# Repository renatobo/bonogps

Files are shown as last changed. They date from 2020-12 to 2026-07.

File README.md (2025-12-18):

# What is BonoGPS?

- [What is BonoGPS?](#what-is-bonogps)
  - [For the track day enthusiast](#for-the-track-day-enthusiast)
  - [For the SW Engineer / maker](#for-the-sw-engineer--maker)
    - [Diagram of project components](#diagram-of-project-components)
  - [Quick Start Guide](#quick-start-guide)
  - [Known Good Configurations](#known-good-configurations)
  - [Complete Bill of Materials (BOM)](#complete-bill-of-materials-bom)
  - [How to Verify Everything is Working](#how-to-verify-everything-is-working)
  - [Common Mistakes to Avoid](#common-mistakes-to-avoid)
  - [HowTo](#howto)
    - [Daily Usage](#daily-usage)
      - [Save a configuration](#save-a-configuration)
    - [Connecting to an app](#connecting-to-an-app)
  - [Hardware build instructions](#hardware-build-instructions)
    - [GPS Choice and setup preconfiguration](#gps-choice-and-setup-preconfiguration)
  - [Software build instructions](#software-build-instructions)
  - [Technical Specifications](#technical-specifications)
  - [Troubleshooting and FAQ](#troubleshooting-and-faq)
  - [Possible enhancements and ideas](#possible-enhancements-and-ideas)
  - [Glossary](#glossary)
  - [Credits and tools](#credits-and-tools)

## For the track day enthusiast

The main goal of this device is to **make GPS data (speed, location) available to mobile apps that can record data up to 25 Hz, for example for track riding**. While there are many good (and not even too expensive) solutions out there, building one for yourself is a great experience.

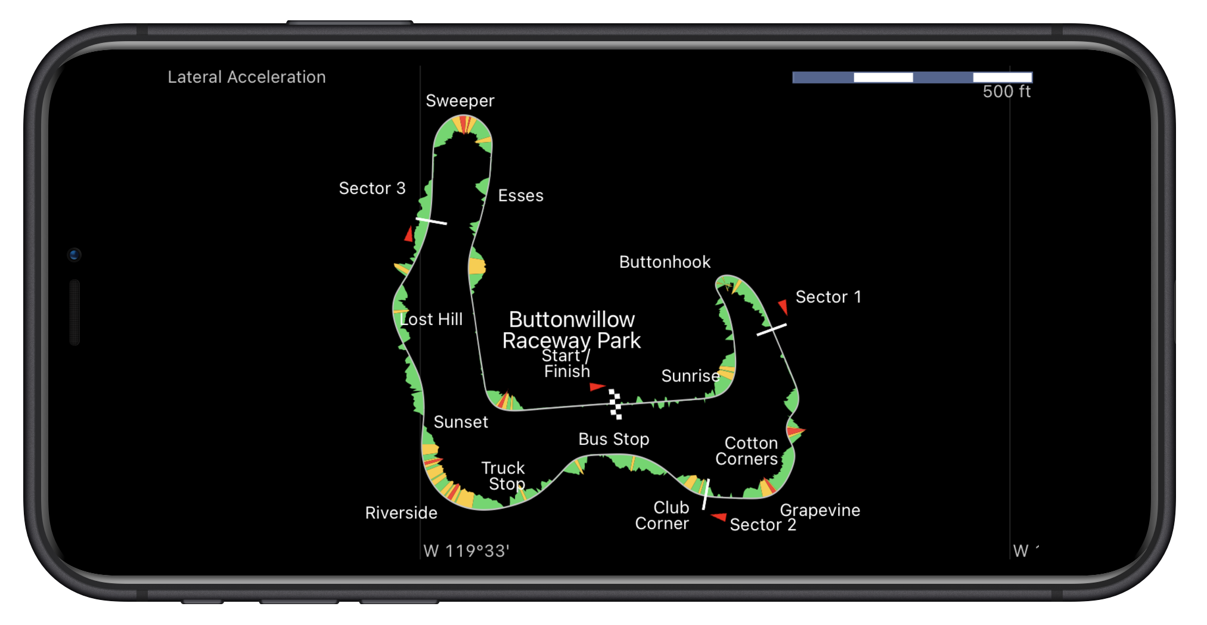
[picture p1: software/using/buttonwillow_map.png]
Map of Buttonwillow lateral acceleration


Currently these apps are supported

1. [Harry's Lap Timer](https://www.gps-laptimer.de) >> details [here](software/connecting/harrylaptimer)
2. [TrackAddict](https://www.hptuners.com/product/trackaddict-app/) >> details [here](software/connecting/trackaddict)
3. [RaceChrono](https://racechrono.com/) >> details [here](software/connecting/racechrono)
4. [RaceTime](https://www.racetimeapp.com/en/) >> details [here](software/connecting/racetime)

If you are not into the maker thing or if you don't know anyone who might be, [look into RaceBox products like mini/miniS](https://www.racebox.pro/) and even [a 25Hz kit](https://www.racebox.pro/products/racebox-micro), or [a XGPS160](https://gps.dualav.com/explore-by-product/xgps160).

## For the SW Engineer / maker

This repo contains software, a list of hardware, and (simple) schematics to build an ESP32 device that reads NMEA sentences from a GPS receiver compatible with u-blox M10 and M8 series, for example:

| GPS Module | Chipset | Max Refresh | Antenna Type | Recommended | Link |
| --- | --- | --- | --- | --- | ---- |
| **BK880** | M10 | **25 Hz** | Active | ✓ Best | [Store](https://store.beitian.com/products/beitian-compass-qmc5883l-amp2-6-pix4-pixhawk-gnss-gps-glonass-dual-flight-control-gps-module-bn-880q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) |
| **BK280** | M10 | **25 Hz** | Passive | ✓ Best | [Store](https://store.beitian.com/collections/gps-module/products/beitian-gps-module-with-antenna-ubx-m10050-gnss-chip-ultra-low-power-gnss-receiver-for-track-be-180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) |
| BN880 | M8 | 10 Hz | Active | Good | [Store](https://store.beitian.com/products/beitian-ubx-m8030-g-mouse-supports-gps-qzss-and-sbas-fixed-wing-traversing-aircraft-gps-module-antenna-bn-180-220-280-357-880-880q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) |
| BN220 | M8 | 10 Hz | Passive | Budget | [Store](https://store.beitian.com/products/beitian-ubx-m8030-g-mouse-supports-gps-qzss-and-sbas-fixed-wing-traversing-aircraft-gps-module-antenna-bn-180-220-280-357-880-880q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) |
| DIYmall NEO-M8N | M8N | 10 Hz | Active | Compatible | [Amazon](https://www.amazon.com/DIYmall-NEO-M8N-Module-HMC5983-Antenna/dp/B012RNLG0K) |

**Note:** Active antennas provide better signal quality. M10 modules (BK880/BK280) offer 25Hz refresh rate which is ideal for track use. See [GPS setup guide](hardware/GPS) for detailed configuration.

and repeats them back to a logger device, either

1. a Bluetooth Low Energy (BLE) service
2. a BT Classic (BT-SPP) stream
3. a TCP-IP socket

The logger device is likely going to be one of the *Track Lap time apps* listed above running on your phone.

Examples of actual devices are in [hardware/assembled](hardware/assembled), at a cost of 25$ and 40$ (GPS receivers with active antennas are a little bit more expensive but worth it, and a larger battery helps as well)

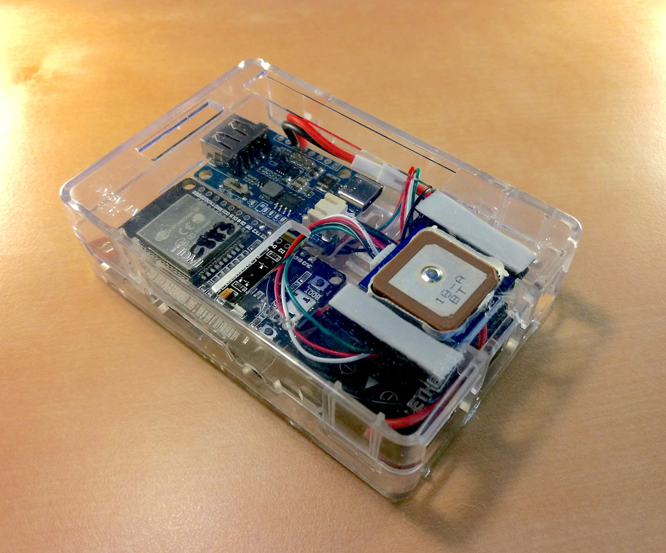
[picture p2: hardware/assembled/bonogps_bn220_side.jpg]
Prototype picture


A web configuration (basic responsive HTML) panel allows changing configuration and selecting GPS parameters on the fly: access it via [http://bonogps.local](http://bonogps.local) (when in WiFi AP mode, this becomes [http://10.0.0.1](http://10.0.0.1) on Android without mDNS resolution).

The settings required by each app are available as presets that you can load for your device (iOS, Android). More information on what version, features, and connections of each app are in [software/connecting](software/connecting).

You can also interface your GPS to [uBlox u-center](https://www.u-blox.com/en/product/u-center) via TCP-IP. In this case, be aware that the UART speed is fixed.

### Diagram of project components

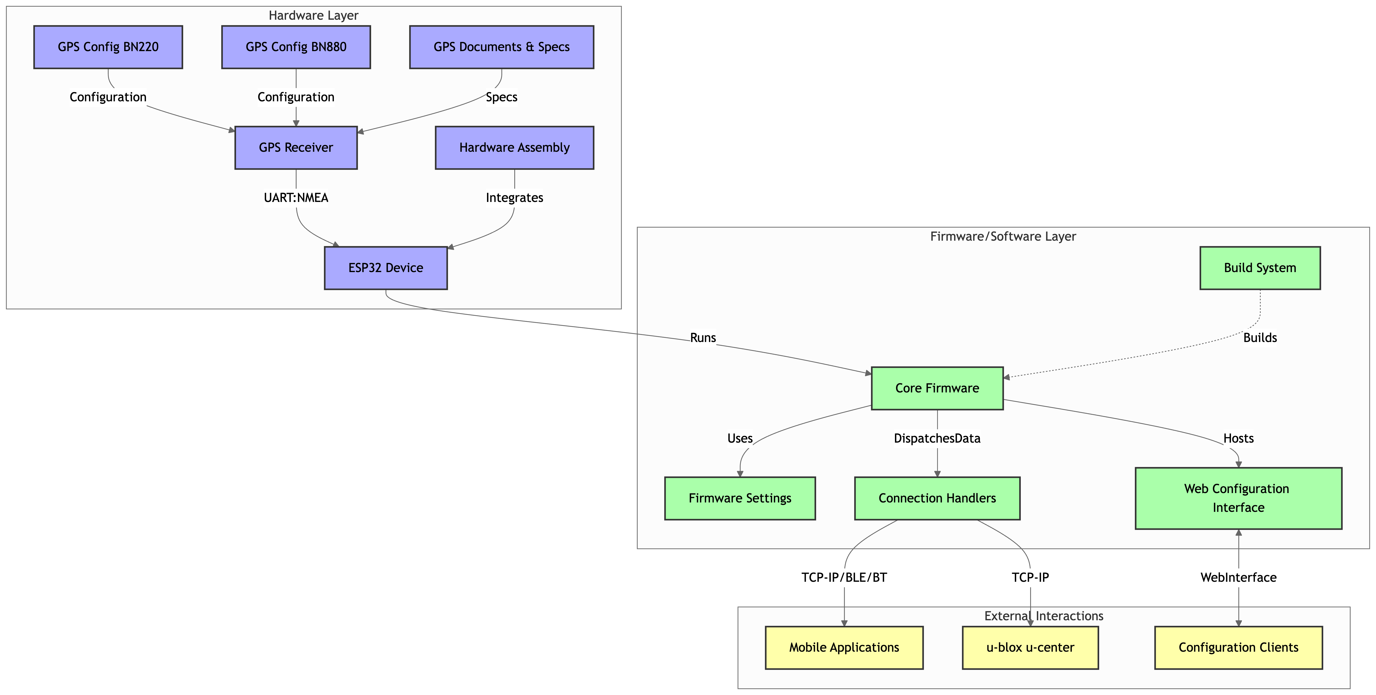
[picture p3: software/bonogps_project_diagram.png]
Project diagram


## Quick Start Guide

**New to BonoGPS? Get started in 5 steps:**

### Step 1: Get the Hardware (Budget: $30-60)

**Minimum setup (~$30):**
- ESP32 DevKit board (~$8-12) - [Amazon](https://www.amazon.com/s?k=esp32+devkit)
- BN220 GPS module (~$15-20) - [Beitian Store](https://store.beitian.com/)
- USB cable for programming/power
- Basic jumper wires

**Recommended setup (~$45):**
- ESP32 DevKit or LOLIN D32 PRO (~$12-20)
- BN880 GPS with active antenna (~$25) - [Beitian Store](https://store.beitian.com/)
- Li-Ion battery (650-2000mAh, ~$5-10)
- Case or 3D printed enclosure

**Best performance (~$60):**
- LOLIN D32 PRO with built-in battery charger (~$15-20)
- BK880 or BK280 GPS (M10, 25Hz) (~$35-45) - [Beitian Store](https://store.beitian.com/)
- 2000mAh Li-Ion battery (~$8-12)
- Custom 3D printed mount

### Step 2: Wire It Up (15 minutes)

Connect GPS to ESP32 - only 4 wires needed:
- GPS **VCC** → ESP32 **3.3V** (power)
- GPS **GND** → ESP32 **GND** (ground)
- GPS **TX** → ESP32 **RX** (GPIO 16 on DevKit, GPIO 4 on LOLIN D32 PRO)
- GPS **RX** → ESP32 **TX** (GPIO 17 on DevKit, GPIO 2 on LOLIN D32 PRO)

See detailed wiring diagrams: [Generic ESP32](hardware/esp32) | [LOLIN D32 PRO](hardware/esp32/lolin_d32_pro.md)

### Step 3: Configure GPS Module (30 minutes)

**Critical:** GPS must be configured before first use.

1. Download [u-blox u-center](https://www.u-blox.com/en/product/u-center)
2. Connect GPS to computer via USB-to-serial adapter
3. Follow the [GPS configuration guide](hardware/GPS)
4. Set baudrate to **115200**
5. Enable required NMEA messages
6. Save configuration to GPS flash memory

### Step 4: Build and Upload Software (20-45 minutes)

**Option A: Arduino IDE (easier for beginners)**
1. Install [Arduino IDE 2.x](https://www.arduino.cc/en/software)
2. Add ESP32 board support
3. Install required libraries (see [library list](software/building#external-libraries))
4. Open `bonogps.ino`
5. Select "ESP32 Dev Module" or "LOLIN D32 PRO"
6. Select "Minimal SPIFFS (1.9MB)" partition scheme
7. Upload to ESP32

**Option B: PlatformIO (recommended for developers)**
1. Install [VS Code + PlatformIO](https://platformio.org/install/ide?install=vscode)
2. Clone this repository: `git clone https://github.com/renatobo/bonogps.git`
3. Open project folder in VS Code
4. Select build target for your board
5. Build and upload

See detailed instructions: [Software build guide](software/building)

### Step 5: Connect to Your App (10 minutes)

1. Power on BonoGPS - wait for GPS fix (LED blinks once/second)
2. Connect phone to **BonoGPS-XXXX** WiFi network
3. Open browser to [http://10.0.0.1](http://10.0.0.1)
4. Go to **Device > Load Preset** - select your app and platform
5. Enable appropriate connection (BLE/BT-SPP/TCP-IP)
6. Open your lap timer app and connect

**Supported apps:** [Harry's Lap Timer](software/connecting/harrylaptimer) | [TrackAddict](software/connecting/trackaddict) | [RaceChrono](software/connecting/racechrono) | [RaceTime](software/connecting/racetime)

**Need help?** See [Troubleshooting FAQ](#troubleshooting-and-faq) below.

---

## Known Good Configurations

These hardware and app combinations have been tested and confirmed working. Use these as reference if you want a guaranteed-to-work setup.

### Budget Build - iOS ($45)
**Hardware:**
- ESP32 DevKit (~$10)
- BN880 GPS with active antenna (~$25)
- 1000mAh Li-Ion battery (~$6)
- Micro USB cable for programming
- Basic transparent case

**Software & Connection:**
- Harry's Lap Timer (iOS)
- Connection: BLE
- Preset: "Harry's Lap Timer iOS BLE"
- Expected performance: 10Hz, good accuracy (2-3m)

**Why this works:** BN880 active antenna provides reliable signal, BLE is native to iOS, Harry's Lap Timer has best BLE support.

### Best Performance - iOS ($65)
**Hardware:**
- LOLIN D32 PRO (~$18)
- BK880 GPS M10 with active antenna (~$40)
- 2000mAh Li-Ion battery (~$10)
- Custom 3D printed mount

**Software & Connection:**
- Harry's Lap Timer (iOS)
- Connection: BLE
- Preset: "Harry's Lap Timer iOS BLE"
- Expected performance: 20Hz over BLE, excellent accuracy (<2m)

**Why this works:** M10 chipset supports 25Hz, LOLIN has battery management, BLE optimized for iOS. Best overall iOS solution.

### Budget Build - Android ($35)
**Hardware:**
- ESP32 DevKit (~$8)
- BN220 GPS with passive antenna (~$18)
- Powered via USB (no battery)
- Velcro mounting

**Software & Connection:**
- RaceChrono (Android)
- Connection: BT-SPP
- Preset: "RaceChrono Android BT-SPP"
- Expected performance: 10Hz, good accuracy in open areas

**Why this works:** BT-SPP is most reliable on Android, RaceChrono is free and widely used, no battery needed for testing.

### Recommended - Android ($50)
**Hardware:**
- ESP32 DevKit or LOLIN D32 PRO (~$12-18)
- BN880 GPS with active antenna (~$25)
- 1500mAh Li-Ion battery (~$8)
- Basic enclosure

**Software & Connection:**
- RaceChrono or TrackAddict (Android)
- Connection: BT-SPP
- Preset: App-specific BT-SPP preset
- Expected performance: 10Hz, excellent accuracy (2-3m)

**Why this works:** Active antenna ensures good signal, BT-SPP handles full NMEA messages reliably, proven battery life for track days.

### Advanced - Android with High Refresh ($65)
**Hardware:**
- LOLIN D32 PRO (~$18)
- BK880 M10 GPS with active antenna (~$40)
- 2000mAh Li-Ion battery (~$10)
- Professional mounting solution

**Software & Connection:**
- Harry's Lap Timer (Android)
- Connection: BT-SPP or TCP-IP
- Preset: "Harry's Lap Timer Android BT-SPP"
- Expected performance: 10Hz over BT-SPP (25Hz requires TCP-IP)

**Why this works:** M10 chipset provides maximum performance, larger battery for full track day, LOLIN handles power management. **Note:** 25Hz requires TCP-IP connection which has less range than Bluetooth.

### Universal WiFi Setup - iOS & Android ($45)
**Hardware:**
- ESP32 DevKit (~$10)
- BN880 GPS (~$25)
- 2000mAh Li-Ion battery (~$10) - important for WiFi power draw

**Software & Connection:**
- RaceChrono (iOS or Android)
- Connection: TCP-IP over WiFi
- IP: 10.0.0.1, Port: 1818
- Expected performance: 10Hz, works on any platform

**Why this works:** TCP-IP works universally, no Bluetooth pairing needed, RaceChrono supports custom TCP devices. Larger battery compensates for WiFi power consumption.

### What About TrackAddict?
**Hardware:** Any ESP32 + BN220/BN880
**Platform:** Android only (not available on iOS)
**Connection:** BT-SPP only
**Important:** Must use **GP Talker ID** (not GN). Load "TrackAddict Android BT-SPP" preset.

### Testing Configuration (Cheapest, $30)
For initial testing before investing in batteries/cases:
- ESP32 DevKit (~$8)
- BN220 GPS (~$18)
- USB power from laptop
- Any supported app
- Test app connection indoors via WiFi, then test GPS outdoors

---

## Complete Bill of Materials (BOM)

Use this comprehensive shopping list to gather all components for your BonoGPS build. Choose components based on your budget and performance requirements.

### Core Components (Required)

| Component | Options | Qty | Est. Cost | Purpose | Where to Buy | Notes |
|---|---|-----|---|---|---|---|
| **ESP32 Board** | ESP32 DevKit (generic) | 1 | $8-12 | Main controller | [Amazon](https://www.amazon.com/s?k=esp32+devkit), AliExpress | Most common, cheapest |
| | LOLIN D32 PRO | 1 | $15-20 | Main controller + extras | [WEMOS/LOLIN Store](https://www.wemos.cc/) | Battery charger, PSRAM, TF card |
| **GPS Module** | BN220 (M8, passive) | 1 | $15-20 | Budget GPS | [Beitian Store](https://store.beitian.com/) | 10Hz max, passive antenna |
| | BN880 (M8, active) | 1 | $23-27 | Good GPS | [Beitian Store](https://store.beitian.com/) | 10Hz max, active antenna (recommended) |
| | BK280 (M10, passive) | 1 | $35-40 | Best GPS | [Beitian Store](https://store.beitian.com/) | 25Hz capable, passive antenna |
| | BK880 (M10, active) | 1 | $38-45 | Best GPS | [Beitian Store](https://store.beitian.com/) | 25Hz capable, active antenna (best performance) |
| | NEO-M8N | 1 | $25-30 | Compatible GPS | [Amazon](https://www.amazon.com/s?k=neo-m8n+gps) | Alternative M8 module |
| **USB Cable** | Micro USB cable | 1 | $3-5 | Programming & power | Amazon, any electronics store | For ESP32 DevKit |
| | USB-C cable | 1 | $5-8 | Programming & power | Amazon, any electronics store | For LOLIN D32 PRO |
| **Jumper Wires** | Male-to-female, 10cm | 4+ | $2-5 | GPS wiring | Amazon, AliExpress | Only needed if not soldering |

**Core components subtotal:** $30-60 depending on choices

### Power Components (Recommended for portable use)

| Component | Options | Qty | Est. Cost | Purpose | Where to Buy | Notes |
|---|---|-----|---|---|---|---|
| **Battery** | 650mAh Li-Ion 3.7V | 1 | $5-7 | ~2-2.5 hrs runtime | Amazon, hobby stores | JST connector |
| | 1000mAh Li-Ion 3.7V | 1 | $6-8 | ~3-4 hrs runtime | Amazon, hobby stores | JST connector |
| | 1500mAh Li-Ion 3.7V | 1 | $8-10 | ~5-6 hrs runtime | Amazon, hobby stores | JST connector |
| | 2000mAh Li-Ion 3.7V | 1 | $8-12 | ~6-8 hrs runtime | Amazon, hobby stores | JST connector, best for track day |
| **Battery Charger** | USB Li-Ion charger | 1 | $3-6 | Battery charging | Amazon, AliExpress | Not needed for LOLIN D32 PRO (built-in) |
| | LiPo balance charger | 1 | $15-25 | Multi-battery charging | Amazon, hobby stores | Optional, for multiple batteries |

**Power components subtotal:** $5-40 depending on battery size and charger

### Assembly Components (Optional but recommended)

| Component | Options | Qty | Est. Cost | Purpose | Where to Buy | Notes |
|---|---|-----|---|---|---|---|
| **Enclosure** | Transparent plastic case | 1 | $3-8 | Basic protection | Amazon, electronics stores | Various sizes available |
| | Custom 3D printed case | 1 | $5-15 | Perfect fit | Local makerspace, online 3D print services | STL files in [hardware/assembled](hardware/assembled) |
| | Weatherproof box | 1 | $10-20 | Professional protection | Amazon | For permanent motorcycle installations |
| **Mounting** | Velcro strips | 1 set | $3-5 | Removable mounting | Amazon, hardware stores | Easy attachment/removal |
| | Double-sided tape (3M VHB) | 1 roll | $5-10 | Semi-permanent | Amazon, hardware stores | Strong, vibration-resistant |
| | Zip ties | 10+ | $2-5 | Cable management | Amazon, hardware stores | Various sizes |
| **Wiring** | Heat shrink tubing | 1 set | $5-8 | Wire insulation | Amazon | Professional finish |
| | 22-24 AWG stranded wire | 1m | $3-5 | Custom wiring | Amazon, electronics stores | If making custom cables |
| | JST connectors | 5 sets | $5-10 | Battery connectors | Amazon, hobby stores | For custom battery connections |
| **Soldering** | Soldering iron kit | 1 | $15-40 | Permanent connections | Amazon | If you don't have one |
| | Solder (lead-free) | 1 roll | $8-15 | Soldering | Amazon, electronics stores | 60/40 or lead-free |
| | Flux pen | 1 | $5-8 | Better solder joints | Amazon | Makes soldering easier |

**Assembly components subtotal:** $0-80+ depending on tools and quality

### Configuration Tools (One-time purchase)

| Component | Options | Qty | Est. Cost | Purpose | Where to Buy | Notes |
|---|---|-----|---|---|---|---|
| **USB-to-Serial Adapter** | CP2102 or FTDI adapter | 1 | $5-10 | GPS configuration | Amazon, AliExpress | Required for GPS setup with u-center |
| | USB-to-TTL with 3.3V/5V switch | 1 | $8-12 | GPS configuration (better) | Amazon | More versatile, safer |

**Configuration tools subtotal:** $5-12 (one-time, reusable)

### Software (Free)

| Software | Cost | Purpose | Where to Get |
|---|---|---|---|
| Arduino IDE 2.x | Free | Firmware compilation (beginner) | [arduino.cc](https://www.arduino.cc/en/software) |
| VS Code + PlatformIO | Free | Firmware compilation (advanced) | [platformio.org](https://platformio.org/) |
| u-blox u-center | Free | GPS configuration | [u-blox.com](https://www.u-blox.com/en/product/u-center) |
| Harry's Lap Timer | $0-100 | iOS/Android lap timing | App Store / Play Store |
| RaceChrono | Free-$20 | iOS/Android lap timing | App Store / Play Store |
| TrackAddict | Free-$25 | Android lap timing | Play Store |
| RaceTime | Free | Android lap timing | Play Store |

### Shopping List Templates

**Minimum viable build ($30-35):**
- [ ] ESP32 DevKit ($8-12)
- [ ] BN220 GPS ($15-20)
- [ ] Micro USB cable ($3-5)
- [ ] 4x jumper wires ($2-5) OR soldering supplies
- [ ] USB-to-serial adapter ($5-10) for GPS config
- **Total: ~$33-52**

**Recommended portable build ($50-65):**
- [ ] ESP32 DevKit or LOLIN D32 PRO ($10-18)
- [ ] BN880 GPS ($25)
- [ ] 1000-1500mAh battery ($6-10)
- [ ] USB cable ($3-8)
- [ ] Plastic case ($3-8)
- [ ] Velcro or double-sided tape ($3-5)
- [ ] USB-to-serial adapter ($5-10)
- **Total: ~$55-84**

**Best performance build ($70-90):**
- [ ] LOLIN D32 PRO ($15-20)
- [ ] BK880 M10 GPS ($38-45)
- [ ] 2000mAh battery ($8-12)
- [ ] USB-C cable ($5-8)
- [ ] 3D printed custom case ($5-15)
- [ ] Mounting solution ($3-10)
- [ ] USB-to-serial adapter ($5-10)
- [ ] Soldering supplies if needed ($15-40)
- **Total: ~$79-160**

### Notes on Purchasing

**GPS Modules:**
- Buy directly from Beitian Store for authentic modules
- Beware of clones on AliExpress/eBay (may have older firmware or fake chipsets)
- Active antennas significantly improve performance in difficult conditions

**Batteries:**
- Match voltage: 3.7V Li-Ion or LiPo only
- Check connector: JST 2-pin is most common
- Capacity = runtime: 650mAh → 2hrs, 2000mAh → 8hrs
- Never charge Li-Ion batteries below 0°C (32°F)

**ESP32 Boards:**
- DevKit: Universal compatibility, cheapest
- LOLIN D32 PRO: Built-in battery management worth the extra cost for portable use

**Where to save money:**
- Skip the case initially (test on desk)
- Use USB power instead of battery for testing
- Use jumper wires instead of soldering initially
- BN220 instead of BN880 (passive vs active antenna)

**Where NOT to save money:**
- GPS module quality (buy from reputable source)
- USB cable quality (cheap cables cause upload/power issues)
- Battery quality (cheap batteries fail quickly)

---

## How to Verify Everything is Working

After completing the Quick Start, use this checklist to confirm your BonoGPS is functioning correctly:

### Hardware & Boot Checks
- ✅ **ESP32 powers on:** Device responds when plugged in via USB or battery
- ✅ **Built-in LED indicates WiFi mode:**
  - Slow blink (500ms cycle) = Access Point mode active
  - Fast blink (250ms cycle) = Client mode active
  - Off = WiFi disabled
- ✅ **GPS module powers on:** GPS module LED is visible (if module has one)

### GPS Functionality
- ✅ **GPS acquires satellite fix:**
  - BN/BK modules: Red LED blinks once per second after fix
  - First time: Allow 5-15 minutes outdoors with clear sky view
  - Subsequent times: Should get fix in 1-5 seconds
- ✅ **Satellite count adequate:** At least 4 satellites visible for accurate positioning
  - Check in web interface under "Status" or "GPS Info"
  - 8+ satellites = excellent signal
  - 4-7 satellites = good signal
  - <4 satellites = insufficient for accurate position

### Connectivity & Web Interface
- ✅ **Can access web interface:**
  - Connect to BonoGPS-XXXX WiFi network
  - Navigate to http://10.0.0.1 (Android) or http://bonogps.local (iOS/desktop)
  - Configuration page loads successfully
- ✅ **Web interface shows correct device info:**
  - Device name displays (BonoGPS-XXXX)
  - Battery voltage shown (if using LOLIN D32 PRO with battery)
  - Firmware version visible

### App Connection
- ✅ **Mobile app discovers device:**
  - BLE: Device appears as "BonoGPS-XXXX" in Bluetooth settings
  - BT-SPP: Device pairs successfully via Bluetooth
  - TCP-IP: App connects to 10.0.0.1:1818
- ✅ **App receives GPS data:**
  - Speed readings update in real-time
  - Position shows on map (if app has map view)
  - Satellite count matches GPS module readings
- ✅ **Data update rate is correct:**
  - 10Hz modules: ~10 updates per second
  - 25Hz modules: ~25 updates per second (M10 chipset only)

### Track Day Ready
- ✅ **Battery runtime adequate:** Full charge provides expected runtime based on capacity
- ✅ **GPS maintains fix while moving:** No dropouts during test drive
- ✅ **Mounting secure:** Device stays in place under vibration
- ✅ **App records session successfully:** Can complete and save a test session

**If any check fails**, see the [Troubleshooting FAQ](#troubleshooting-and-faq) section below.

---

## Common Mistakes to Avoid

### Critical Mistakes (Will prevent device from working)

**❌ Forgetting to configure GPS before first use**
- **Why it matters:** GPS modules ship with default settings that may not work with BonoGPS or your app
- **Solution:** Follow the [GPS configuration guide](hardware/GPS) before connecting GPS to ESP32
- **Time cost:** 30-45 minutes to configure correctly

**❌ Wrong partition scheme during upload**
- **Why it matters:** Default partition is too small for BonoGPS firmware with Bluetooth
- **Solution:** Select "Minimal SPIFFS (1.9MB)" in Arduino IDE or PlatformIO
- **Error:** Build fails with "not enough space" or upload fails

**❌ Swapped TX/RX pins**
- **Why it matters:** UART communication requires TX→RX and RX→TX crossover
- **Solution:** Connect GPS TX to ESP32 RX, and GPS RX to ESP32 TX
- **Symptom:** No GPS data received, web interface shows "No GPS fix"

**❌ Testing GPS indoors**
- **Why it matters:** GPS requires direct line of sight to satellites
- **Solution:** Test outdoors with clear sky view, away from buildings and trees
- **First fix:** Allow 5-15 minutes for initial satellite almanac download

### App Compatibility Mistakes

**❌ Using GN Talker ID with RaceChrono or TrackAddict**
- **Why it matters:** These apps require GP Talker ID specifically
- **Solution:** Load the app-specific preset from web interface (sets Main Talker ID = GP)
- **Symptom:** App shows "no data" or "invalid GPS"

**❌ Wrong connection method for platform**
- **Why it matters:** iOS doesn't support BT-SPP, Android BLE has limitations
- **Solution:**
  - **iOS:** Use BLE (Harry's Lap Timer) or TCP-IP (RaceChrono)
  - **Android:** Use BT-SPP (most reliable) or TCP-IP as backup
- **Symptom:** Device not found or connection drops

**❌ Too high refresh rate with satellite messages enabled**
- **Why it matters:** Bluetooth bandwidth is limited
- **Solution:**
  - For BLE: Use 20Hz or lower, disable GSA/GSV or poll at 5-second intervals
  - For BT-SPP: 10Hz is safe with full messages
- **Symptom:** Connection drops, data corruption, app crashes

### Build and Upload Mistakes

**❌ Wrong NimBLE library version**
- **Why it matters:** Breaking changes between versions 1.x, 2.x, and 3.x
- **Solution:** Use NimBLE-Arduino version **2.x** specifically
- **Error:** Compilation fails with "class NimBLEDevice has no member..."

**❌ Not cloning from Git (downloading ZIP instead)**
- **Why it matters:** Build script uses Git to determine version info
- **Solution:** Use `git clone https://github.com/renatobo/bonogps.git`
- **Error:** "git_rev_macro.py" errors during PlatformIO build

**❌ Insufficient USB power**
- **Why it matters:** ESP32 + GPS + WiFi can draw up to 500mA
- **Solution:** Use quality USB cable and powered USB port (not USB hub)
- **Symptom:** Random resets, brownouts, WiFi disconnections

### Hardware Assembly Mistakes

**❌ Using 5V instead of 3.3V for GPS power**
- **Why it matters:** Most GPS modules are 3.3V only, 5V will damage them
- **Solution:** Connect GPS VCC to ESP32 **3.3V pin**, never 5V
- **Result:** Permanent GPS module damage

**❌ Weak solder connections for motorcycle use**
- **Why it matters:** Vibration will eventually break cold solder joints
- **Solution:** Use proper soldering technique or crimped connectors
- **Symptom:** Intermittent GPS connection, random disconnections

**❌ GPS antenna placement under metal or carbon fiber**
- **Why it matters:** Metal and carbon fiber block GPS signals completely
- **Solution:** Place antenna under plastic fairings/seat cowls only
- **Symptom:** Never gets satellite fix, satellite count always 0

### Configuration Mistakes

**❌ Not saving GPS configuration to flash**
- **Why it matters:** Configuration is lost when GPS powers off
- **Solution:** In u-center, send UBX-CFG-CFG command to save to flash
- **Symptom:** GPS works after configuration but reverts on next power-on

**❌ Mismatched baudrate between GPS and ESP32**
- **Why it matters:** Serial communication requires matching speeds
- **Solution:** Set GPS to 115200 baud, matches `GPS_STANDARD_BAUD_RATE` in code
- **Symptom:** Garbled data, no GPS messages received

**❌ Forgetting to enable required NMEA messages**
- **Why it matters:** Apps need specific messages (GGA, RMC minimum)
- **Solution:** Load app preset or manually enable messages in u-center
- **Symptom:** App connects but shows "no GPS data"

**Pro tip:** Follow the Quick Start Guide step-by-step and verify each stage before moving to the next. Most issues are caught early this way.

---

## HowTo

### Daily Usage

1. Turn on the ESP32 and wait a few minutes for the GPS to get a fix on position (on BN devices, the red led will blink every second)
2. Open your preferred mobile app and connect it to your BonoGPS-*ABCD* device (ABCD is a combination of 4 letters and numbers unique to your ESP32 device)
3. Enjoy your ride!

Most runtime configurations are managed via its web-based interface: you can use your phone or any device with a web browser which is able to connect to either the built-in Access Point the BonoGPS provides or (if you are home and you have configured the WiFi Client credentials) [http://bonogps.local](http://bonogps.local)

The local built-in access point will be named BonoGPS-*ABCD* device (ABCD is a combination of 4 letters and numbers unique to your ESP32 device) and the password to it is in the source code (you can change it to your discretion - it's simply meant to avoid anyone connecting by mistake)

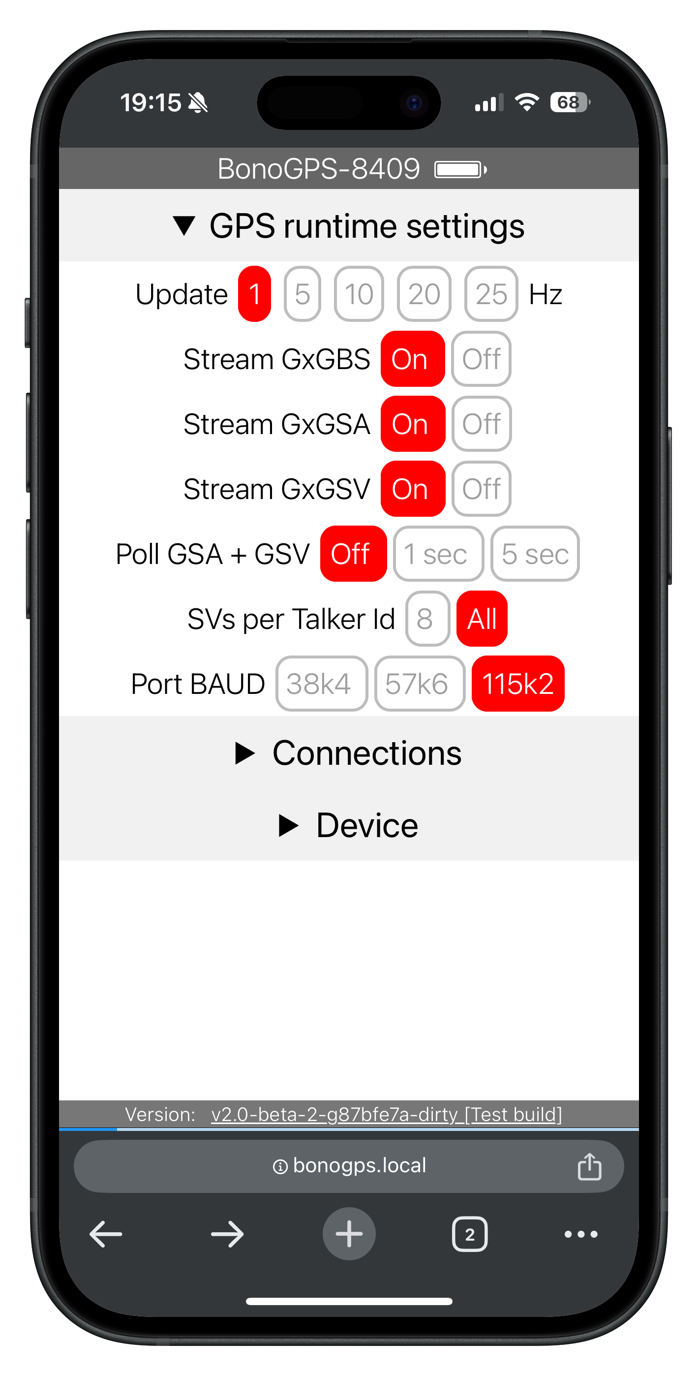
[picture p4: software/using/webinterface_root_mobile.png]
Main page of web configuration panel from mobile device


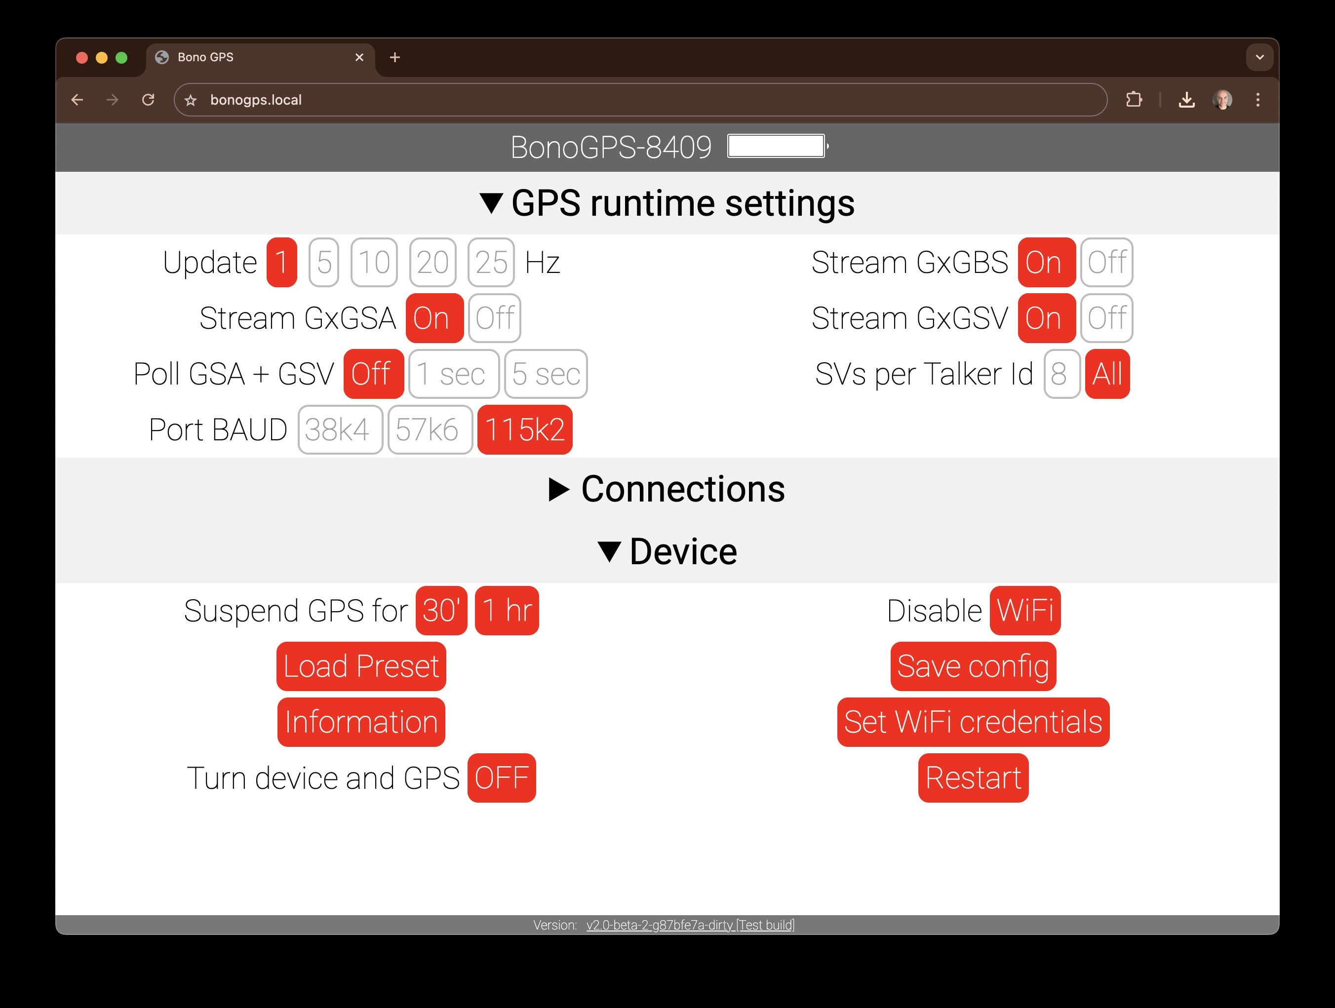
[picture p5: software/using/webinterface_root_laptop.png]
Main page of web configuration panel from laptop


- **GPS runtime settings:** GPS messages, rate of updates, serial port speed
- **Connections:** List clients, enable BLE/BT-SPP connectivity, enable/disable the builtin TCP-IP messages repeater, switch between WiFi client to a well-known WiFi network or built-in Access Point
- **Device:** Put GPS in powersaving for some time, Disable WiFi, load preset configurations, save current configuration, collect information about current status of the device, save WiFi credentials for client mode restart the ESP32

The BOOT button (or another button of your choice) allows you to loop between WiFi modes on the fly:

- short press: toggle between WiFi Access Point (built in led, usually blue, slowly blinking 500 ms cycle) and no WiFi (built in led off)
- long press (at least 2 seconds): enable WiFi Client so that you can reach the unit from your preferred WiFi network (internal led/blue led light flashes rapidly with a 250 ms cycle)

#### Save a configuration

If you load a preset or if you change a runtime settings, you can preserve it across restart of the device.

Go to *Device > Save Config* and you'll find these options

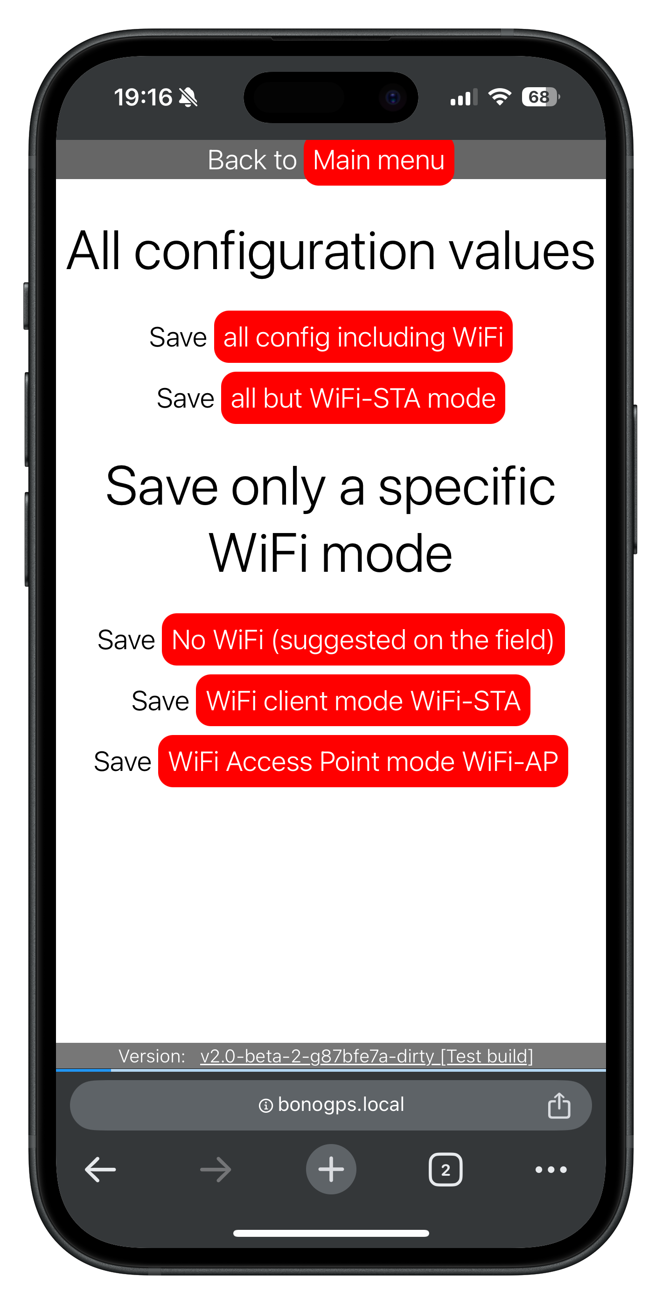
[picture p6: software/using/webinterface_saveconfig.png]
Save Config page


For convenience, the WiFi status (Start its own AP, or connect to a local WiFi) can be excluded or saved separately.

### Connecting to an app

There are many mobile apps to log lap times, few accept custom devices, in particular on iOS. The ones below are tested.

| App | Platform | Connection | Max Refresh | Tested Version | Setup Guide |
| --- | --- | --- | --- | --- | --- |
| [Harry's Lap Timer](https://www.gps-laptimer.de) | iOS | **BLE** (recommended), TCP-IP | 20Hz (BLE) | v24.9.1 | [Guide](software/connecting/harrylaptimer) |
| [Harry's Lap Timer](https://www.gps-laptimer.de) | Android | **BT-SPP** (recommended), TCP-IP | 10Hz | v24.9.1 | [Guide](software/connecting/harrylaptimer) |
| [TrackAddict](https://www.hptuners.com/product/trackaddict-app/) | Android | BT-SPP | 10Hz | v4.6.0 | [Guide](software/connecting/trackaddict) |
| [RaceChrono](https://racechrono.com/) | iOS | TCP-IP | 10Hz | v7.0.10 | [Guide](software/connecting/racechrono) |
| [RaceChrono](https://racechrono.com/) | Android | BT-SPP | 10Hz | v7.0.10 | [Guide](software/connecting/racechrono) |
| [RaceTime](https://www.racetimeapp.com/en/) | Android | BT-SPP | 10Hz | v3.3.8 lite | [Guide](software/connecting/racetime) |

**Note:** Recommended connection methods are shown in **bold**. See detailed setup instructions in each guide.

You can load a preset configuration from the configuration page selecting *Device > Load Preset* and then choosing your mobile phone device and app combination (when there are alternatives, the recommended option is in bold)

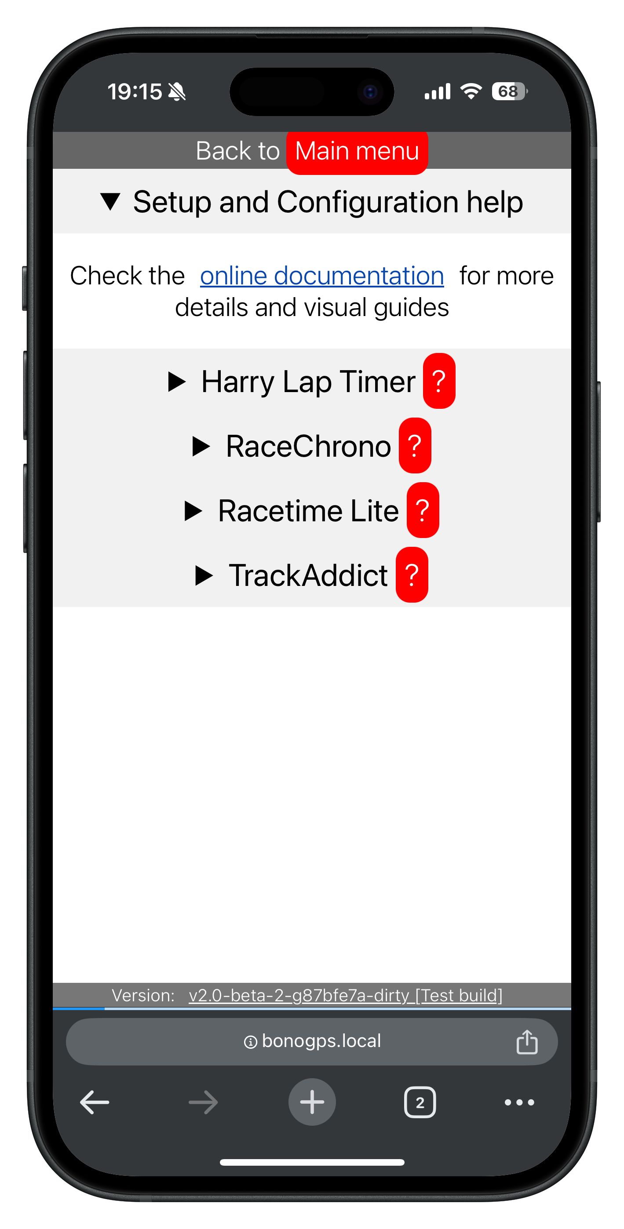
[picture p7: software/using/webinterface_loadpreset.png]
Loading presets


## Hardware build instructions

**⏱️ Time:** 30-60 minutes | **🎯 Difficulty:** Beginner (basic soldering skills helpful)

The minimum build is a ublox M8 series GPS receiver module connected to an ESP32:

- TX/RX from the GPS to a serial port (default in the code is UART2/Serial2) on ESP32. Remember: you need to connect RX on one device to TX on the other and viceversa
- the GPS power pins to ESP32: VCC to 3v3, GND to GND

BN220 comes with a 4 pin adapter cable for GND TX RX VCC, while BN880 includes 2 additionals pins for SDA and SCL of the IMU which are not used so you should leave them unconnected.

Schematics are relatively simple

- power the GPS module (3.3V on ESP32 to VCC on GPS receiver, GND on ESP32 to GND on GPS receiver)
- connect GPS RX to ESP32 UART2 TX and GPS TX to ESP32 UART2 RX (RX and TX are switched: GPS transmits, ESP32 receives)

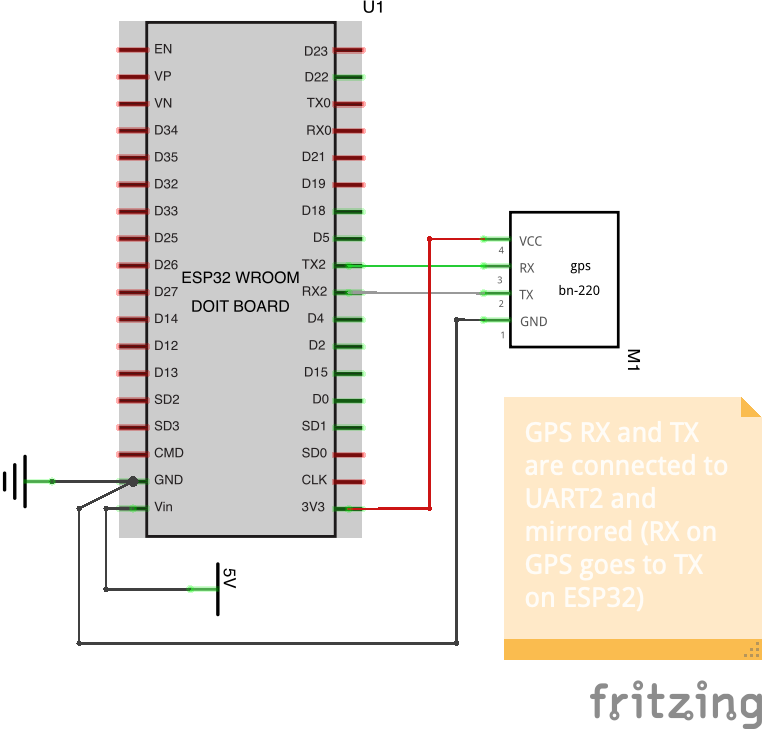
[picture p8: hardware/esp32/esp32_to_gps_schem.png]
Schematics


Examples are in [hardware/assembled](hardware/assembled) including an example with more options using an ESP32 device type Lolin D32 Pro which has an internal battery charger [hardware/esp32/lolin_d32_pro.md](hardware/esp32/lolin_d32_pro.md)

**See also:**
- [GPS Configuration Guide](hardware/GPS) - Configure GPS before use
- [Assembly Troubleshooting](hardware/assembled#hardware-assembly-troubleshooting) - Common wiring issues
- [LOLIN D32 PRO Specific Guide](hardware/esp32/lolin_d32_pro.md) - Battery charging setup

### GPS Choice and setup preconfiguration

**⏱️ Time:** 30-45 minutes | **🎯 Difficulty:** Intermediate | **Prerequisites:** USB-to-serial adapter, u-center software

Thanks to needs of a very active drone community, there are a lot of inexpensive GPS receivers: some considerations on performance/accuracy/cost are reported [in the hardware/GPS folder](hardware/GPS).

What you need to configure is documented [in the hardware/GPS folder](hardware/GPS): this is **important**, the performances of your GPS won't be optimal until you do, or the whole setup will not work at all.

**See also:**
- [GPS Module Comparison](hardware/GPS#performance-comparison) - Detailed specs for each module
- [GPS Troubleshooting](hardware/GPS#gps-hardware-troubleshooting) - Module-specific issues
- [u-blox u-center Guide](hardware/GPS) - Configuration software instructions

## Software build instructions

**⏱️ Time:** 20-45 minutes (Arduino IDE: 20-30 min, PlatformIO: 30-45 min first time) | **🎯 Difficulty:** Beginner to Intermediate | **Prerequisites:** Arduino IDE or VS Code with PlatformIO, USB cable

This code is developed specifically for ESP32, and tested with [PlatformIO](https://platformio.org/) (main development platform) and the [Arduino IDE version 2 (2.3.4)](https://www.arduino.cc/en/software). More information on what libraries are needed and software organization [in the software/building folder](software/building).

**See also:**
- [Build Troubleshooting](software/building#build-troubleshooting) - Library versions, compilation errors
- [Board Settings](include/README.md) - Pin definitions and configurations
- [Connecting to Apps](software/connecting) - After successful build

## Technical Specifications

### Performance Expectations

**GPS Accuracy:**
- **Horizontal position:** 2-3 meters (6-10 feet) typical with M8/M10 chipsets
- **Speed accuracy:** ±0.1 km/h at constant velocity
- **Update rates:** 10Hz (M8 modules), 25Hz (M10 modules)
- **Cold start time:** 5-15 minutes (first power-on)
- **Hot start time:** 1-5 seconds (after recent fix)
- **Signal quality:** C/N0 values typically 30-40 dBHz (higher is better)

**Power Consumption:**
- **ESP32:** 80-160mA (varies with WiFi/Bluetooth activity)
- **GPS module:** 30-80mA (depends on module and fix status)
- **LED indicators:** 10-40mA
- **Total typical:** 250-350mA average during operation
- **Peak consumption:** Up to 500mA when WiFi and GPS are both active

**Battery Life Examples:**
- 650mAh battery: ~2-2.5 hours runtime
- 1000mAh battery: ~3-4 hours runtime
- 2000mAh battery: ~6-8 hours runtime (full track day)

**Note:** Actual battery life depends on WiFi/Bluetooth usage, GPS update rate, and environmental conditions.

### Connectivity Specifications

**WiFi:**
- **Standard:** 802.11 b/g/n (2.4 GHz only)
- **Range:** ~30-50 meters open air (depends on environment)
- **Access Point mode:** Supports up to 4 simultaneous clients
- **TCP server port:** 1818 (configurable)
- **mDNS hostname:** bonogps.local

**Bluetooth Low Energy (BLE):**
- **Standard:** Bluetooth 4.2 / 5.0 (depends on ESP32 module)
- **Range:** ~10-30 meters typical
- **Service UUID:** 1819 (Location and Navigation Service)
- **Max throughput:** ~20Hz GPS data with minimal satellite info
- **iOS support:** Full (recommended connection method)

**Bluetooth Classic (BT-SPP):**
- **Standard:** Bluetooth 2.0 SPP (Serial Port Profile)
- **Range:** ~10-30 meters typical
- **Baudrate:** 115200 (matches GPS UART)
- **Max throughput:** ~10Hz GPS data with satellite info
- **Android support:** Full (recommended connection method)

### Build Size and Memory

**Flash Memory Usage:**
- **With BLE + BT-SPP:** ~1.5-1.7 MB (requires Minimal SPIFFS partition)
- **With BLE only:** ~1.3-1.4 MB
- **With BT-SPP only:** ~1.2-1.3 MB
- **Minimum partition:** 1.9 MB app space required

**RAM Usage:**
- **ESP32 SRAM:** ~120-180 KB used (out of 320 KB available)
- **PSRAM:** Optional, helps with stability if available (LOLIN D32 PRO has 4MB)

**SPIFFS Storage:**
- **Configuration files:** ~2-4 KB
- **Reserved space:** 190 KB (with Minimal SPIFFS partition)

### Supported NMEA Messages

**Standard output messages:**
- `GxGGA` - Global Positioning System Fix Data
- `GxRMC` - Recommended Minimum Specific GPS Data
- `GxGBS` - GNSS Satellite Fault Detection (accuracy estimates)
- `GxGSA` - GPS DOP and Active Satellites (optional, polled)
- `GxGSV` - GPS Satellites in View (optional, polled)
- `GxVTG` - Track Made Good and Ground Speed
- `GxZDA` - Time and Date

**Talker ID support:**
- `GN` - Multi-constellation GNSS (GPS+GLONASS+Galileo+BeiDou)
- `GP` - GPS only (required by some apps like RaceChrono)

**Message rates:** Configurable from 1Hz to 25Hz (hardware dependent)

### Environmental Specifications

**Operating conditions:**
- **Temperature:** -20°C to +70°C (-4°F to 158°F) typical
- **Note:** Li-Ion batteries should not be charged below 0°C (32°F)
- **Humidity:** Most ESP32 boards are not waterproof without enclosure
- **Vibration:** Solder connections recommended for motorcycle use
- **Mounting:** GPS antenna requires clear sky view (metal/carbon blocks signal)

**GPS antenna considerations:**
- **Active antennas:** Better signal quality, require 3.3V power, ~50mA draw
- **Passive antennas:** Lower signal quality, no extra power required
- **Placement:** Best under plastic fairings/seat cowls, avoid metal/carbon

### Limitations and Known Issues

**Connection limitations:**
- **BT-SPP reconnection:** Android may require device restart or re-pairing
- **BLE throughput:** Limited to ~20Hz with full NMEA messages
- **WiFi TCP:** Single client at a time for GPS data stream
- **Memory pressure:** Running BLE + BT-SPP + WiFi simultaneously may cause instability

**GPS limitations:**
- **Indoor use:** GPS will not work indoors or under metal roofs
- **Urban canyons:** Tall buildings can degrade accuracy
- **Tree cover:** Dense foliage can reduce satellite visibility
- **First fix:** Takes 5-15 minutes on first power-on to download almanac

**Software limitations:**
- **OTA updates:** Disabled by default to save flash space
- **Web interface:** Basic HTML/CSS, optimized for mobile browsers
- **Configuration backup:** Manual export/import via web interface

See [Troubleshooting FAQ](#troubleshooting-and-faq) for solutions to common problems.

## Troubleshooting and FAQ

### Common Issues and Solutions

#### GPS and Hardware Issues

**Q: My GPS is not getting a fix / takes very long to acquire satellites**

**A:** Several factors can affect GPS acquisition time:
- **First time setup:** Cold start can take 5-15 minutes to download almanac data
- **Antenna placement:** Ensure the GPS antenna has clear view of the sky. The BN-880 LED should blink once per second when it has a fix
- **Antenna orientation:** For BN-880/BK-880, the antenna should face upward (skyward)
- **Indoor use:** GPS will not work indoors or in areas with obstructed sky view
- **Configuration:** Verify your GPS is properly configured with the correct baudrate (115200) and messages enabled. See [GPS configuration guide](hardware/GPS)

**Q: No GPS data is reaching my mobile app**

**A:** Troubleshooting steps:
1. Check that the GPS has a fix (BN devices: red LED blinking every second)
2. Verify the baudrate matches: GPS port should be 115200 (check `GPS_STANDARD_BAUD_RATE` in code)
3. Confirm correct NMEA messages are enabled for your app (load the appropriate preset)
4. Check TX/RX wiring: GPS TX → ESP32 RX, GPS RX → ESP32 TX
5. Open an [issue](https://github.com/renatobo/bonogps/issues) with details if problem persists

**Q: Which GPS module should I buy?**

**A:** See the [GPS comparison table](#for-the-sw-engineer--maker) in this README. Quick recommendations:
- **Best performance:** BK880 or BK280 (M10 chipset, 25Hz, ~$35-45)
- **Good balance:** BN880 (M8 chipset with active antenna, 10Hz, ~$25)
- **Budget option:** BN220 (M8 chipset with passive antenna, 10Hz, ~$15-20)

Active antennas provide significantly better signal quality. Avoid NEO-M8N if you need multiple GNSS constellations.

#### Bluetooth and Connection Issues

**Q: ESP32 reboots when I change Bluetooth settings / No Bluetooth available**

**A:** This is typically caused by:
- **Insufficient partition space:** Ensure you're using the "Minimal SPIFFS" partition scheme (1.9MB app space)
- **Memory issues:** Both BLE and BT-SPP enabled simultaneously can cause memory pressure. Try disabling one if not needed
- **Library conflicts:** Ensure you're using NimBLE-Arduino version 2.x (not 1.x)
- Check the [closed issue #60](https://github.com/renatobo/bonogps/issues/60) for resolution details

**Q: Can't reconnect to RaceChrono via BT-SPP after first disconnect**

**A:** Known issue with Android BT-SPP. Workarounds:
- Restart the ESP32 device
- "Forget" the Bluetooth device on Android and re-pair
- Restart the RaceChrono app
- See [issue #30](https://github.com/renatobo/bonogps/issues/30) for ongoing discussion

**Q: BLE connection issues with Harry's Lap Timer on iOS**

**A:** Common solutions:
- Ensure BLE is enabled in the web configuration
- Verify the service UUID is **1819** and characteristic UUID is **2A67**
- Device name should be `BonoGPS-XXXX` (check web interface header)
- iOS may cache old Bluetooth data - try restarting your iPhone
- BLE works best at 20Hz or lower with GSA/GSV polling disabled or at low frequency (every 5 seconds)

#### WiFi and Web Interface Issues

**Q: Can't access the web interface at bonogps.local**

**A:** Troubleshooting:
- **Android users:** Use [http://10.0.0.1](http://10.0.0.1) instead (Android doesn't support mDNS by default)
- **Access Point mode:** Connect to the BonoGPS-XXXX WiFi network first (password is in the source code)
- **Client mode:** Ensure your device is on the same WiFi network as BonoGPS
- Check the built-in LED: Slow blink (500ms) = AP mode, Fast blink (250ms) = Client mode
- Use the BOOT button to cycle between WiFi modes (short press for AP/off, long press for Client)

**Q: How do I change WiFi modes?**

**A:** Use the BOOT button (or external button on LOLIN D32 PRO):
- **Short press:** Toggle between Access Point mode and WiFi off
- **Long press (2+ seconds):** Switch to Client mode (connects to your saved WiFi network)

The built-in blue LED indicates the mode:
- Slow blinking (500ms cycle): Access Point active
- Fast blinking (250ms cycle): Client mode active
- Off: WiFi disabled

#### Build and Compilation Issues

**Q: Arduino IDE compilation fails with NimBLE errors**

**A:** Solutions:
- Use NimBLE-Arduino version **2.x** (not 1.x or 3.x)
- Install the exact library versions from `platform.ini` `lib_deps` section
- Use EasyButton version **2.0.1** specifically (newer versions have breaking changes)
- Ensure you selected "Minimal SPIFFS (1.9MB)" partition scheme
- See [issue #50](https://github.com/renatobo/bonogps/issues/50) for NimBLE-specific solutions

**Q: Build fails with "not enough space" or partition errors**

**A:** The compiled binary is large due to Bluetooth stacks:
- Select `Tools > Partition Scheme > Minimal SPIFFS (1.9MB APP)`
- In PlatformIO: use `board_build.partitions = min_spiffs.csv`
- Disable unused features (BLE or BT-SPP) if you only need one connection type

**Q: Git revision macro errors during PlatformIO build**

**A:** The build uses `git_rev_macro.py` to get version info:
- Clone the repository with git (don't download as ZIP)
- If issues persist, comment out the script invocation in `platformio.ini`
- Manually define `GIT_REV` and `GIT_REPO` macros if needed

### App-Specific Issues

**Q: RaceChrono shows weird/incorrect data**

**A:** Check these settings:
- Main Talker ID must be **GP** (not GN) for RaceChrono
- Enable only `GPGGA`, `GPRMC`, optionally `GPGSA`/`GPGSV`
- Load the RaceChrono preset from *Device > Load Preset*
- See [RaceChrono setup guide](software/connecting/racechrono)

**Q: TrackAddict not receiving data**

**A:** TrackAddict requirements:
- Requires Main Talker ID = **GP**
- Must have `GPRMC`, `GPGGA`, and `GPGLL` enabled
- Only works via BT-SPP on Android
- Load the TrackAddict preset from the web interface

### Getting Help

If your issue isn't covered here:

1. Check the [GitHub Discussions](https://github.com/renatobo/bonogps/discussions) - many questions already answered
2. Review [closed issues](https://github.com/renatobo/bonogps/issues?q=is%3Aissue+is%3Aclosed) for similar problems
3. Check app-specific guides in [software/connecting](software/connecting)
4. Open a new [issue](https://github.com/renatobo/bonogps/issues) with:
   - Your hardware (ESP32 model, GPS model)
   - Software version and how you built it
   - What app you're connecting to
   - Detailed description of the problem
   - Any error messages or logs

## Possible enhancements and ideas

See [issues with label enhancement](https://github.com/renatobo/bonogps/issues?q=is%3Aissue+is%3Aopen+label%3Aenhancement) on the github project

## Glossary

**GPS & Navigation Terms:**

- **GPS Fix:** When the GPS receiver has locked onto enough satellites (minimum 4) to calculate position. Indicated by LED blinking once per second on BN/BK modules.
- **Cold Start:** First power-on when GPS has no recent satellite data. Takes 5-15 minutes to download almanac and ephemeris data.
- **Hot Start:** GPS restart when recent satellite data is still valid. Typically achieves fix in 1-5 seconds.
- **Warm Start:** GPS restart after some time, when almanac is still valid but ephemeris is outdated. Takes 30-60 seconds.
- **Satellite Almanac:** Coarse orbital data for all satellites, valid for months. Required for cold start.
- **Ephemeris:** Precise orbital data for specific satellites, valid for 2-4 hours. Required for accurate positioning.
- **GNSS (Global Navigation Satellite System):** Umbrella term for all satellite navigation systems (GPS, GLONASS, Galileo, BeiDou).
- **GPS (Global Positioning System):** US satellite navigation system, one type of GNSS.
- **M8 / M10:** u-blox GPS chipset generations. M8 supports 10Hz max, M10 supports 25Hz max.
- **C/N0 (Carrier-to-Noise Ratio):** Signal quality measurement in dBHz. Higher is better (30-40 dBHz typical, 45+ excellent).
- **HDOP (Horizontal Dilution of Precision):** Geometric accuracy indicator. Lower is better (<1.0 excellent, 1-2 good, >5 poor).
- **DOP (Dilution of Precision):** Measure of satellite geometry effect on position accuracy.

**GPS Antenna Terms:**

- **Active Antenna:** Has built-in amplifier (LNA), requires power, better signal quality. Typical for BN880/BK880.
- **Passive Antenna:** No amplifier, cheaper, lower signal quality. Typical for BN220/BK280.
- **LNA (Low Noise Amplifier):** Built-in amplifier in active antennas that boosts weak GPS signals.

**GPS Message Formats:**

- **NMEA (National Marine Electronics Association):** Standard text format for GPS data (e.g., $GPGGA,123456...).
- **UBX:** u-blox binary protocol, more compact than NMEA but requires parsing library.
- **Talker ID:** Two-letter prefix indicating satellite system source:
  - **GP:** GPS only (US satellites)
  - **GN:** Multi-constellation GNSS (GPS + GLONASS + Galileo + BeiDou)
- **NMEA Messages:**
  - **GGA:** Global Positioning System Fix Data (position, altitude, fix quality)
  - **RMC:** Recommended Minimum Specific GPS Data (position, speed, course, time)
  - **GSA:** GPS DOP and Active Satellites (satellite IDs, dilution of precision)
  - **GSV:** GPS Satellites in View (satellite count, signal strength per satellite)
  - **GBS:** GNSS Satellite Fault Detection (accuracy estimates)
  - **VTG:** Track Made Good and Ground Speed (course and speed)
  - **ZDA:** Time and Date (UTC time and date)

**Connectivity Terms:**

- **BLE (Bluetooth Low Energy):** Low-power Bluetooth standard (Bluetooth 4.0+). Recommended for iOS with Harry's Lap Timer. Max ~20Hz GPS data.
- **BT-SPP (Bluetooth Serial Port Profile):** Classic Bluetooth serial connection. Recommended for Android. Max ~10Hz with full messages.
- **TCP-IP:** Network connection over WiFi. Works on both iOS and Android. Single client at a time for GPS stream.
- **UART (Universal Asynchronous Receiver-Transmitter):** Serial communication protocol between GPS and ESP32.
- **Baudrate:** Speed of serial communication in bits per second. BonoGPS uses 115200 baud.
- **mDNS (Multicast DNS):** Network protocol that resolves bonogps.local to IP address. Doesn't work on Android by default.

**ESP32 Terms:**

- **ESP32:** Microcontroller with built-in WiFi and Bluetooth. Brain of BonoGPS device.
- **Flash Memory:** Non-volatile storage on ESP32 where firmware is stored (~4MB total).
- **RAM/SRAM:** Volatile memory for program execution (~320KB on standard ESP32).
- **PSRAM:** Optional extra RAM (4MB on LOLIN D32 PRO) for improved stability.
- **Partition Scheme:** How flash memory is divided. BonoGPS requires "Minimal SPIFFS (1.9MB)" for app space.
- **SPIFFS:** File system on ESP32 for storing configuration files (~190KB with minimal partition).
- **OTA (Over-The-Air):** Wireless firmware updates. Disabled by default in BonoGPS to save flash space.
- **GPIO (General Purpose Input/Output):** Programmable pins on ESP32 for connecting peripherals.
- **UART2/Serial2:** Second serial port on ESP32, used for GPS communication (TX=GPIO17, RX=GPIO16 on DevKit).

**Build & Development Terms:**

- **Arduino IDE:** Beginner-friendly development environment for programming ESP32.
- **PlatformIO:** Professional IDE extension for VS Code, preferred for BonoGPS development.
- **Library:** Pre-written code package that adds functionality (e.g., NimBLE-Arduino for Bluetooth).
- **NimBLE:** Lightweight Bluetooth Low Energy library for ESP32. BonoGPS requires version 2.x.
- **Preset:** Pre-configured settings for specific apps, loaded via web interface (Device > Load Preset).

**u-blox Configuration Terms:**

- **u-center:** Windows software from u-blox for configuring GPS modules.
- **UBX-CFG-xxx:** Configuration commands for u-blox GPS modules (e.g., UBX-CFG-PRT for port settings).
- **Save to Flash:** Persist GPS configuration so it survives power cycles. Critical step often forgotten!

**Hardware Terms:**

- **DevKit:** Generic ESP32 development board, most common and cheapest option (~$8-12).
- **LOLIN D32 PRO:** Premium ESP32 board with battery charger, PSRAM, and TF card slot (~$15-20).
- **Li-Ion / LiPo:** Rechargeable lithium battery types. 3.7V nominal, charge to 4.2V, discharge to 3.0V minimum.
- **JST Connector:** Small 2-pin connector commonly used for batteries.
- **VCC:** Power supply voltage pin (3.3V for GPS modules).
- **GND:** Ground / 0V reference voltage pin.
- **TX (Transmit):** Data output pin. GPS TX connects to ESP32 RX.
- **RX (Receive):** Data input pin. GPS RX connects to ESP32 TX.

**App-Specific Terms:**

- **Harry's Lap Timer (HLT):** Most feature-rich lap timer app, only iOS app supporting BLE GPS.
- **RaceChrono:** Lap timer with cleanest UX, requires GP Talker ID.
- **TrackAddict:** Android-only lap timer, requires GP Talker ID.
- **Hz (Hertz):** Updates per second. 10Hz = 10 position updates per second. 25Hz = 25 updates per second (M10 modules only).

## Credits and tools

- Very valuable information from the mobile apps developers: [Harry's Lap Timer forum](http://forum.gps-laptimer.de/viewforum.php?f=2), [HP Tuner Track Adict forum](https://forum.hptuners.com/forumdisplay.php?74-TrackAddict), [RaceChrono forum](https://racechrono.com/forum/categories/diy-builds)
- Email conversations with Harald Schlangmann (Harry's Lap Timer) and Roberto Morini (Racetime) who I thank for the time and effort in developing and supporting their apps
- There are several other similar projects on github, a few from which I learned a lot: [RaceChronoDYI-TBeam](https://github.com/0x8008135/RaceChronoDYI-TBeam) [RaceChrono BLE DIY device (GPS and CAN-Bus)](https://github.com/aollin/racechrono-ble-diy-device) [DAWA](https://github.com/quichedood/DAWA-6.x)
- Screenshot framing by [Mockuphone](https://mockuphone.com/) and [Android developers marketing tools
](https://developer.android.com/distribute/marketing-tools/device-art-generator)
- [The GPS Dictionary](https://www.u-blox.com/sites/default/files/the_gps_dictionary.pdf)

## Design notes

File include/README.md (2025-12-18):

# Include files

This directory contains header files used by the BonoGPS project.

## Board Configuration

- [include/bonogps_board_settings.h](bonogps_board_settings.h) includes board settings (PINS mostly) that are specific to a tested board.

## Generated files

**Important:** These header files are auto-generated - do not manually modify them. Regenerate them with [generate_css.sh](../generate_css.sh)

- [include/bonogps_css_base.h](bonogps_css_base.h) preprocessing macro that defines the strings returned by the `http://bonogps.local/css` url in the portal
- [include/bonogps_css_base_battery.h](bonogps_css_base_battery.h) preprocessing macro that defines the strings returned by the `http://bonogps.local/css` url in the portal with additional definitions to show the battery (no need to increase the flash size if you don't need a battery gauge). This is used when macro `SHOWBATTERY` is used

## Source files

Apply your customizations to CSS files here in their native format: they are minimized when imported in the source code.

- [include/style_base.css](style_base.css) CSS definitions for the web portal
- [include/style_base_battery.css](style_base_battery.css) CSS definitions required to display the battery gauge in the web portal

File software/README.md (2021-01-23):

# Documentation on Software

How to develop/build/upload the source code in [building](building)

How to connect your running bonogps device to a mobile app in [connecting](connecting)

Everyday usage and configurations in [using](using)

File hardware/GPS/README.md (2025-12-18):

# Which GPS receiver?

- [Which GPS receiver?](#which-gps-receiver)
  - [FAQ](#faq)
    - [Q: Can I use a cheaper Neo-6M module?](#q-can-i-use-a-cheaper-neo-6m-module)
    - [Q: Can I use a newer Neo-9M module?](#q-can-i-use-a-newer-neo-9m-module)
    - [Q: What modules are recommended?](#q-what-modules-are-recommended)
    - [Q: No data is made available to my apps, what's wrong?](#q-no-data-is-made-available-to-my-apps-whats-wrong)
    - [Q: M8N, M8Q, M8U .. which one?](#q-m8n-m8q-m8u--which-one)
  - [Comparison of performance vs precision](#comparison-of-performance-vs-precision)
    - [3 hours of measurements side by side](#3-hours-of-measurements-side-by-side)
  - [GPS modules setup via presaved configuration](#gps-modules-setup-via-presaved-configuration)
  - [Setup on your own, step by step](#setup-on-your-own-step-by-step)
    - [Settings that are required](#settings-that-are-required)
      - [UBX-CFG-GNSS](#ubx-cfg-gnss)
        - [GPS, SBAS, Galileo, GLONASS](#gps-sbas-galileo-glonass)
        - [GPS, SBAS](#gps-sbas)
      - [UBX-CFG-MSG](#ubx-cfg-msg)
      - [UBX-CFG-NMEA](#ubx-cfg-nmea)
      - [UBX-CFG-PRT](#ubx-cfg-prt)
      - [UBX-CFG-NAV5](#ubx-cfg-nav5)
    - [Settings to optimize performances](#settings-to-optimize-performances)
      - [UBX-CFG-RATE](#ubx-cfg-rate)
      - [UBX-CFG-PMS](#ubx-cfg-pms)
      - [UBX-CFG-SBAS](#ubx-cfg-sbas)
        - [Without Integrity, WAAS for Americas](#without-integrity-waas-for-americas)
        - [With Integrity, WAAS for Americas](#with-integrity-waas-for-americas)
      - [UBX-CFG-NAVX5](#ubx-cfg-navx5)
      - [UBX-CFG-ITFM](#ubx-cfg-itfm)
        - [With Active Antenna (e.g. BN-880)](#with-active-antenna-eg-bn-880)
        - [With Passive Antenna (e.g. BN-220)](#with-passive-antenna-eg-bn-220)
    - [Messages that do not required changes](#messages-that-do-not-required-changes)
    - [Save Configuration](#save-configuration)
  - [References](#references)

This project requires a receiver compatible with inexpensive Beitian M8 (classic) or M9 series (performance)

- they are widely available: used in avionics (drones) projects
- cost-effective
- allow 10Hz (M8 Classic) to 25Hz (M10 Performance series) refresh rate
- granular configuration of NMEA messages

## FAQ

### Q: Can I use a cheaper Neo-6M module or Beitian M10 BE-XXX series?

**A:** Neo-6M not really, as it gives a max of 5Hz frequency and its performance are far less than a Neo-8M module for a fraction more of the cost. Beitian BE-XXX series is limited to 4 Hz, so that's also a no.

### Q: Can I use a newer M9 module?

**A:** Yes - testing performed on some M9 Beitian devices like BK880 and BK280 confirm them as good choices if you are looking at 25 Hz refresh

### Q: What modules are recommended?

**A:** Genuine ublox are best, with an active antenna that is tuned for GPS+Glonass+Galileo. Too much to say about this subject, see the discussion forum.

### Q: No data is made available to my apps, what's wrong?

**A:** First thing to check is: is the PORT RATE stored in your GPS (see below paragraph **UBX-CFG-PRT**) matching the one expected by the bonogps.cpp code in macro `GPS_STANDARD_BAUD_RATE` ? It should be 115200. Open an issue otherwise so that we can work out troubleshooting

### Q: M8N, M8Q, M8U .. which one?

**A:** According to the [NEO-M8-FW3 datasheet](https://www.u-blox.com/sites/default/files/NEO-M8-FW3_DataSheet_%28UBX-15031086%29.pdf), you should avoid NEO-M8N as it's limited to 5 Hz for 2 or more concurrent constellations (e.g. GPS+<GLONASS/Galileo> or even all three). NEO-M8Q and NEO-M8M have 10Hz for multiple constellations, and 18Hz for a single one. Read up [here](https://discuss.ardupilot.org/t/gps-config-u-blox-m8n/46970/34) as well. Beitian uses a different naming convention and it can be confusing: check specs for (a) refresh rate (b) type of antenna

## Comparison of performance vs precision

A comparison in a static location with clear sky among performance (speed = navigation rate, intensity = SV CN0) and precision (HDOP):

| Module | Chipset | Antenna | Multi-Constellation Rate | GPS Only Rate | Signal Quality (C/N0) | Precision | Notes |
| --- | --- | --- | --- | --- | --- | --- | ----- |
| BK880 | M10 | Active | 25 Hz | 25 Hz | 35-40 dBHz | Excellent | Best choice for track use |
| BK280 | M10 | Passive | 25 Hz | 25 Hz | 30-35 dBHz | Excellent | Best budget option |
| NEO-M8N | M8N | Active | 5 Hz | 10 Hz | 35-40 dBHz | Very Good | Genuine u-blox, slow refresh |
| BN880 | M8 | Active | 10 Hz | 18 Hz | 30-35 dBHz | Good | Good balance |
| BN220 | M8 | Passive | 10 Hz | 18 Hz | ~30 dBHz | Good | Budget, may struggle in poor visibility |

**Key Findings:**
- **M10 modules (BK series)** offer the best overall performance with 25Hz support
- **Active antennas** significantly improve signal quality (5-10 dBHz better)
- **Signal quality (C/N0):** Higher is better; 35+ dBHz is excellent
- **Galileo** provides better precision than GLONASS in current testing

### 3 hours of measurements side by side

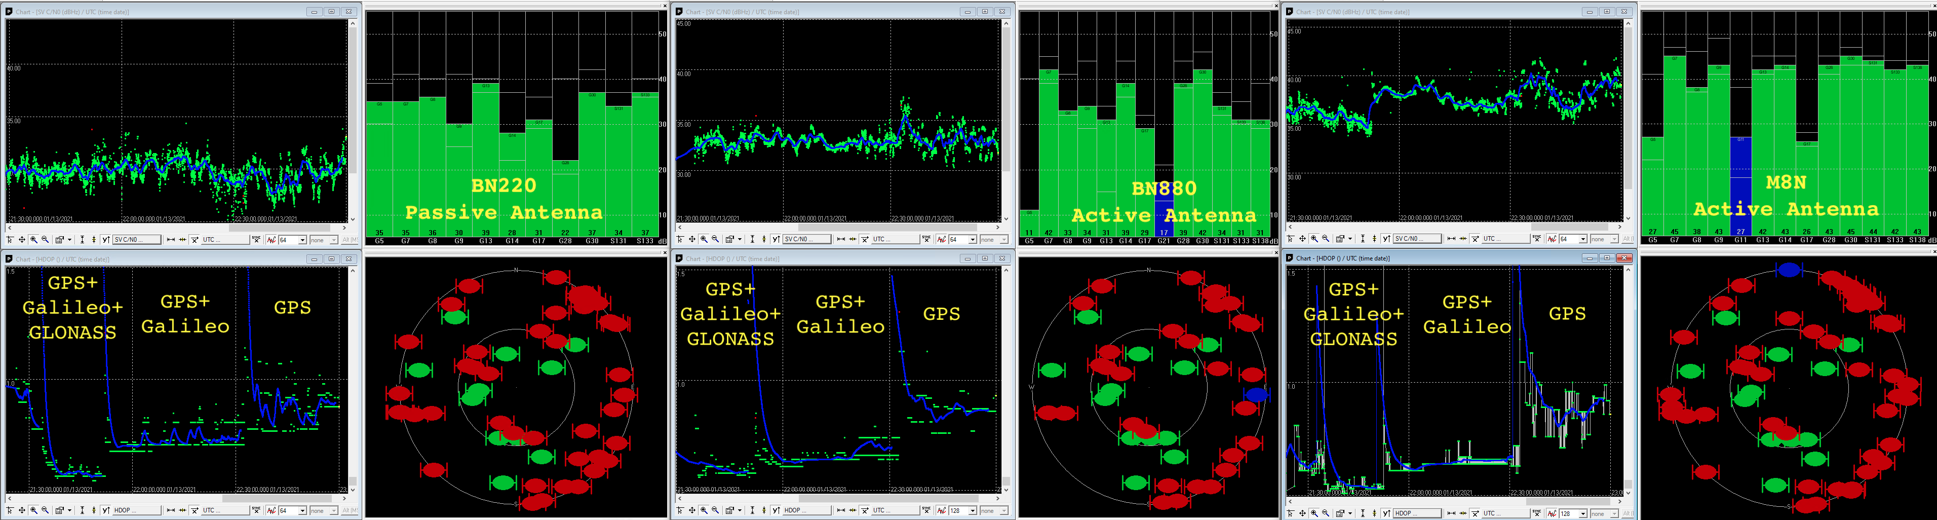
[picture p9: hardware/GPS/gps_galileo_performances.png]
Comparison of performances


## GPS modules setup via presaved configuration

To reduce complexity of this software, you need to save a baseline configuration of your GPS module. Parameters include

- default port speed (it should match GPS_STANDARD_BAUD_RATE, starting from v1.1 there is a basic auto baud rate detection)
- what satellite systems to use (GPS, Glonass, Galileo, BeiDou)
- what Wide Area Augmentation System to be used
- disable all unnecessary NMEA messages
- set motion defaults

... etc.

_Note: these instructions are specific to a GPS module compatile with ublox 8 messages._

You can setup an out of the box M8 module restoring one of these saved configurations:

- passive antenna [BN220](gps-bn220-config.txt)
- active antenna [BN820](gps-bn880-config.txt)

The procedure is

1. Connect the receiver to your PC (a FTDI USB to TTL module comes handy, the same one used to program Arduino boards without USB ports, [example](https://www.amazon.com/s?k=ftdi+usb+to+serial&i=electronics&ref=nb_sb_noss_1));
2. Open U-Center and connect to the serial device used at step 1 (you can configure correct COM port and Baudrate under Receiver tab);
3. Go to Tools -> GNSS Configuration or Tools -> Receiver Configuration, depending on your U-Center version;
4. Find one of the saved configuration files in this folder;
5. Select your GPS module series (BN220 and BN820 is M8);
6. Select "Store Configurations into BBR/Flash";
7. Click 'File > GNSS'.

At this point the configuration is stored on your device in its flash memory. Please note that some cheap GPS receiver modules do not have flash memory and they will not work for this project.

The example configuration offered in this repo configures the default baudrate of the GPS receiver at 115200 (which is the expected baudrate by bonogps software), but sometimes the GPS receiver has a factory default of 9600 baudrate. This will lead to connection errors as soon as U-Center applies the baudrate setting. So, once you start receiving connection errors, configure the baudrate to 115200 via (Receiver -> Baudrate). After that, the flashing should continue normally.

Save configuration is notably (as is - several sources say so and I find it as well) unreliable, so please run it more than a few times and check that settings have actually been saved across resets/power downs.

## Setup on your own, step by step

### Settings that are required

After an established connection with your GPS, open 'View > Messages' or press F9

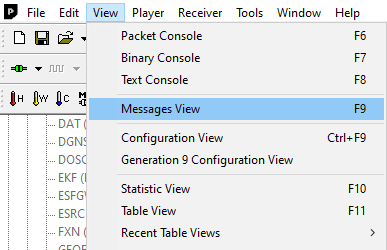
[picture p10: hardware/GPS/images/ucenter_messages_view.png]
F9


then go the UBX section

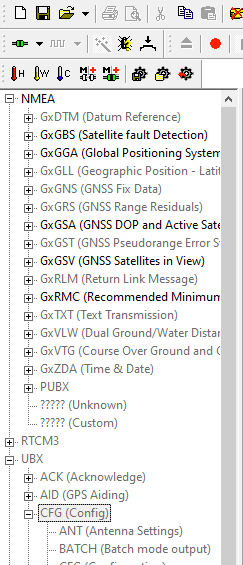
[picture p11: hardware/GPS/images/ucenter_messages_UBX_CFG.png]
UBX->CFG


#### UBX-CFG-GNSS

More satellites and constellations (GPS, Galileo, GLONASS) does not necessarily mean better results: hardware here limits performances, so you might have to compromise speed for amount of data.

There is plenty of information online on drone GPS solutions that explain the optimal update rate for each hardware (e.g. [ArduPilot](https://github.com/ArduPilot/ardupilot/issues/13053)).

Configurations tested, optimized for NAMER:

- BK280, BK880 or other 10 series capable of 20Hz or 25Hz with 2+ constellations and tracking 42 channels: Enable GPS, SBAS, Galileo, Glonass
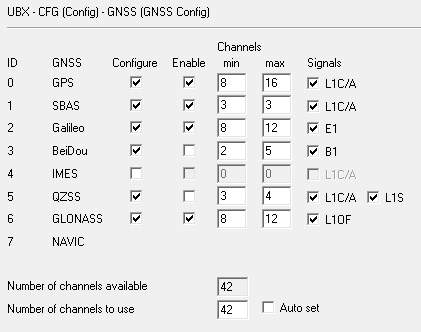
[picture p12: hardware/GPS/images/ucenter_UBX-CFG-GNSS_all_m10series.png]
All constellations M10 series


- BN-880, BN220, NEO-M8Q, NEO-M8M and other devices capable of 10Hz with 2+ constellations: Enable GPS, SBAS, Galileo, Glonass
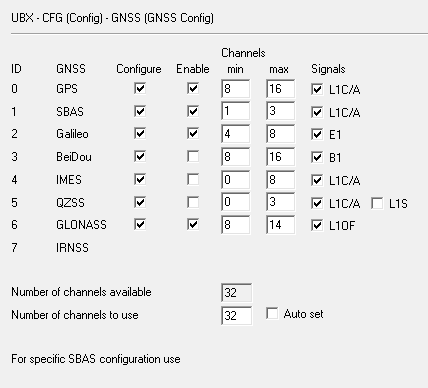
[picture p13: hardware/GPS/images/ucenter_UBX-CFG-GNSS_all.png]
All constellations


- NEO-M8N: GPS, SBAS (unless you are happy with 5Hz, then you can enable additional ones)
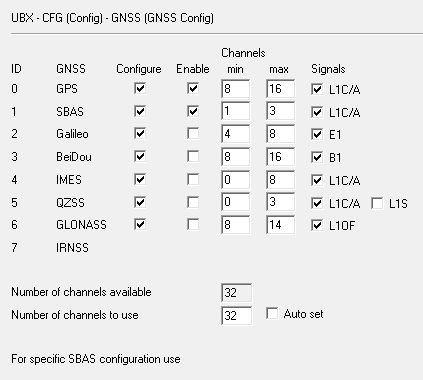
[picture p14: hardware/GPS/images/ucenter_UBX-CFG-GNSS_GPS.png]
GPS and SBAS only


Common for NAMER users

- GPS, Galileo, Glonass: enabled
- SBAS: enabled
- BeiDou has good coverage in APAC => disabled 
- IMES disabled as ineffective for this use
- QZSS is used to improve coverage in East Asia and Oceania => disabled

##### GPS, SBAS, Galileo, GLONASS

BK-880, BK-280, M10 and other devices at 25Hz with multiple constellations up to 42 satellites

```text
B5 62 06 3E 34 00 00 00 2A 06 00 08 10 00 01
00 01 01 01 03 03 00 01 00 01 01 02 08 0C 00
01 00 01 01 03 02 05 00 00 00 01 01 05 03 04
00 00 00 05 01 06 08 0C 00 01 00 01 01 21 DE
```

BN-880, BN-220, M8Q and other devices at 10Hz with multiple constellations

```text
B5 62 06 3E 3C 00 00 20 20 07 00 08 10 00 01
00 01 01 01 01 03 00 01 00 01 01 02 04 08 00
01 00 01 01 03 08 10 00 00 00 01 01 04 00 08
00 00 00 01 03 05 00 03 00 00 00 01 05 06 08
0E 00 01 00 01 01
```

##### GPS, SBAS

E.g. to use 10Hz on M8N

```text
B5 62 06 3E 3C 00 00 00 20 07 00 08 10 00 01
00 01 01 01 01 03 00 01 00 01 01 02 04 08 00
00 00 01 01 03 08 10 00 00 00 01 01 04 00 08
00 00 00 01 01 05 00 03 00 00 00 01 01 06 08
0E 00 00 00 01 01 2D 79
```

#### UBX-CFG-MSG

- First disable all messages (click on the top level node NMEA, right click -> 'Disable child messages')

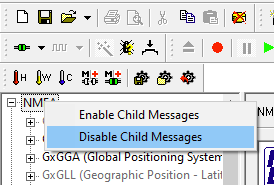
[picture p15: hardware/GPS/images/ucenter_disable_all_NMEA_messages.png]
disable all messages


- Enable `GxGGA` and `GxRMC` messages

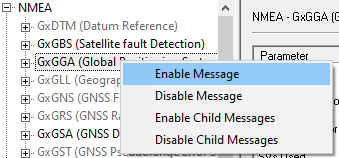
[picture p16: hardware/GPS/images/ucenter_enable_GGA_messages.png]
Enable GGA


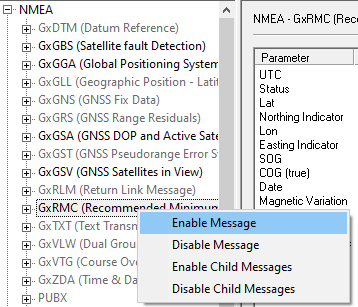
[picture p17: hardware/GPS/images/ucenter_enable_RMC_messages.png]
Enable RMC


Disable all messages

```text
B5 62 06 01 03 00 F0 0A 00 04 23
B5 62 06 01 03 00 F0 09 00 03 21
B5 62 06 01 03 00 F0 00 00 FA 0F
B5 62 06 01 03 00 F0 01 00 FB 11
B5 62 06 01 03 00 F0 0D 00 07 29
B5 62 06 01 03 00 F0 06 00 00 1B
B5 62 06 01 03 00 F0 02 00 FC 13
B5 62 06 01 03 00 F0 07 00 01 1D
B5 62 06 01 03 00 F0 03 00 FD 15
B5 62 06 01 03 00 F0 0F 00 09 2D
B5 62 06 01 03 00 F0 04 00 FE 17
B5 62 06 01 03 00 F0 05 00 FF 19
B5 62 06 01 03 00 F0 08 00 02 1F
B5 62 06 01 03 00 F1 00 00 FB 12
B5 62 06 01 03 00 F1 01 00 FC 14
B5 62 06 01 03 00 F1 03 00 FE 18
B5 62 06 01 03 00 F1 04 00 FF 1A
B5 62 06 01 03 00 F1 05 00 00 1C
B5 62 06 01 03 00 F1 06 00 01 1E
```

Enable `GGA`

```text
B5 62 06 01 03 00 F0 00 01 FB 10
```

then enable `RMC`

```text
B5 62 06 01 03 00 F0 04 01 FF 18
```

#### UBX-CFG-NMEA

This is automatically set when changing the number of SV's, no need to set it

- NMEA messages: 4.10 format
- Max SVs `0 - Standard`
- Mode Flags: Consider Mode checked
- Numbering used for SVs not supported by NMEA: `1 - Extended (3 digit)`
- Main Talker ID `0 - System dependent`
- GSV Talker ID `0 - GNSS Specific`

If you are using BeiDou, there might be additional configuration required

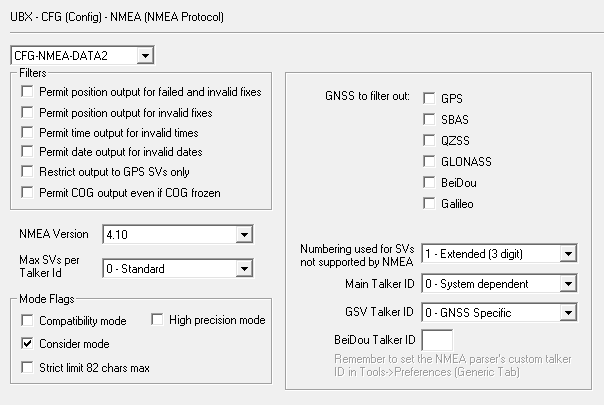
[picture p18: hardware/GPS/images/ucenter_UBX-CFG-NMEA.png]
ucenter_UBX-CFG-NMEA


```text
B5 62 06 17 14 00 00 41 00 02 00 00 00 00 01
00 00 01 00 00 00 00 00 00 00 00 76 63
```

#### UBX-CFG-PRT

go to UBX > CFG > PRT (Port) node and for Target 1 set

- Protocol In: `0+1 UBX+MNEA`
- Protocol Out: `0+1 UBX+MNEA`
- Baudrate: `115200`
  
Version 1 required a predefine Baudrate, but it caused issues when a temporary value was changed, so from version 1.1 BonoGPS tries to automatically set the baud rate.

If you have long cables, you might want to test `56k`

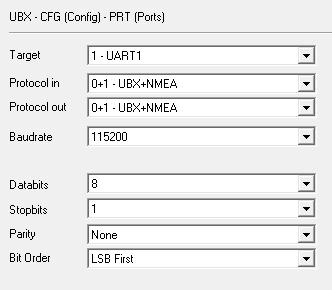
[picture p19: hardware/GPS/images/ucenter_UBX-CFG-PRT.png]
ucenter_UBX-CFG-PRT


```text
B5 62 06 00 14 00 01 00 00 00 D0 08 00 00 00
C2 01 00 03 00 03 00 00 00 00 00 BC 5E 
```

#### UBX-CFG-NAV5

The default configuration of these GPS receiver is optimized for pedestrian or slowly moving vehicles. We can suggest parameters that are a better fit for a fast vehicle

- Dynamic model -> 4 Automotive

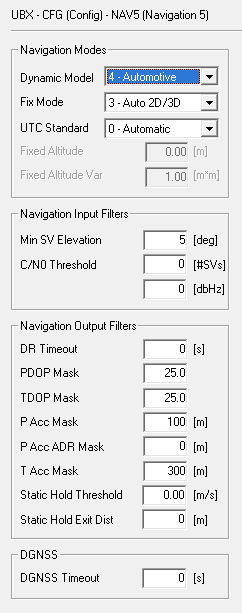
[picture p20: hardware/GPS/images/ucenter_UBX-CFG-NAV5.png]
ucenter_UBX-CFG-NAV5


```text
B5 62 06 24 24 00 FF FF 04 03 00 00 00 00 10
27 00 00 05 00 FA 00 FA 00 64 00 2C 01 00 00  
00 00 00 00 00 00 00 00 00 00 00 00 14 98
```

### Settings to optimize performances

#### UBX-CFG-RATE

This is automatically set by the configuration portal, no need to set it. For 10Hz

- Time Source `0 - UTC Time` (not sure if `1 - GPS` is a better option)
- Measurement Period `100 ms`

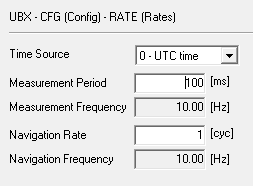
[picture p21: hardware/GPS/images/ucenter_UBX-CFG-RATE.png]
ucenter_UBX-CFG-RATE


```text
B5 62 06 08 06 00 64 00 01 00 00 00 79 10
```

On BN220 and other devices that can handle > 10 Hz, you can use 18Hz (not supported by the configuration portal right now)

```text
B5 62 06 08 06 00 37 00 01 00 00 00 4C 02
```

#### UBX-CFG-PMS

This sets optimal performances, sacrificing battery life

- Set `0 - Full Power`, and `Save Configuration`

ucenter_UBX-CFG-PMS

```text
B5 62 06 86 08 00 00 00 00 00 00 00 00 00 94 5A
```

then

```text
B5 62 06 09 0D 00 00 00 00 00 FF FF 00 00 00 00 
00 00 07 21 AF
```

#### UBX-CFG-SBAS

- Enable SBAS
- Turn on Ranging, Correction Data
- If you are using GPS only, then you should enable Integrity information
- Number of search channels = 3 is configured in the CFG-GNSS panel
- Set SBAS specific to your region: use the PRN Codes WAAS for Americas, EGNOS for Europe. Auto-scan will identify them by itself at the cost of a longer startup time

##### Without Integrity, WAAS for Americas

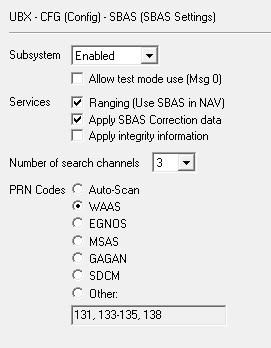
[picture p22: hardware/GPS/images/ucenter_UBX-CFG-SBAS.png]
ucenter_UBX-CFG-SBAS


```text
B5 62 06 16 08 00 01 03 03 00 00 E8 04 00 17 79
```

##### With Integrity, WAAS for Americas

```text
B5 62 06 16 08 00 01 07 03 00 00 E8 04 00 1B 95
```

#### UBX-CFG-NAVX5

- Message Version 2 (the default)
- AssistNow Autonomous `Use AssistNow Autonomous`

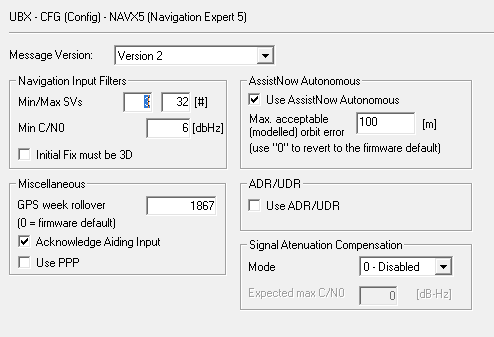
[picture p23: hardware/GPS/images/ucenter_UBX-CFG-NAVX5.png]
ucenter_UBX-CFG-NAVX5


```text
B5 62 06 23 28 00 02 00 4C 66 C0 00 00 00
00 00 03 20 06 00 00 00 00 01 4B 07 00 00
00 00 00 00 00 01 00 00 64 00 00 00 00 00
00 00 00 00 A6 82
```

#### UBX-CFG-ITFM

- Enable jamming and interference

##### With Active Antenna (e.g. BN-880)

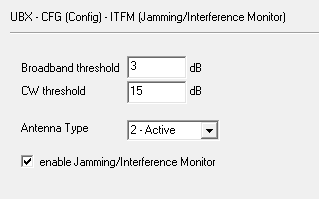
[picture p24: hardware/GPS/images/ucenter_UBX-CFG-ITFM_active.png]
ucenter_UBX-CFG-ITFM_active


```text
B5 62 06 39 08 00 F3 AC 62 AD 1E 63 00 00 76 A5
```

##### With Passive Antenna (e.g. BN-220)

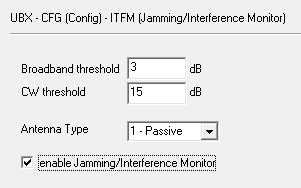
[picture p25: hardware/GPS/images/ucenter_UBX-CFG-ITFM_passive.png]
ucenter_UBX-CFG-ITFM_passive


```text
B5 62 06 39 08 00 F3 AC 62 AD 1E 53 00 00 66 75
```

### Messages that do not required changes

- CFG-ANT
- CFG-DAT
- CFG-INF
- CFG-ODO
- CFG-PM2 *-> use UBX-CFG-PMS instead*
- CFG-RXM *-> use UBX-CFG-PMS instead*
- CFG-TP5
- CFG-USB
- CFG-LOGFILTER

### Save Configuration

- Open menu "Receiver > Action > Save config"

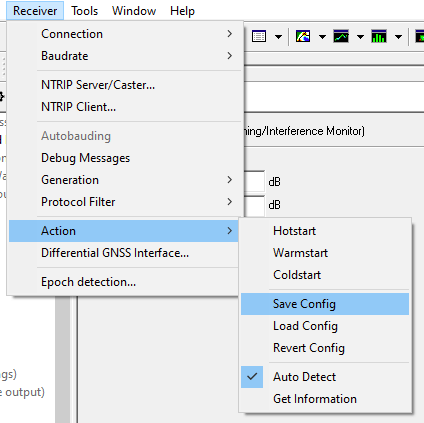
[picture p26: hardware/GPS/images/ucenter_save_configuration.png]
ucenter_save_configuration


or issue

```text
B5 62 06 09 0D 00 00 00 00 00 FF FF 00 00 00 00 00 00 17 31 BF
```

## GPS Hardware Troubleshooting

### Module-Specific Issues

#### BN220 / BN880 Series (M8 Chipset)

**Problem:** GPS not responding / No communication with ESP32

**Solution:**
- Verify power connections: VCC to 3.3V (NOT 5V), GND to GND
- Check TX/RX are crossed: GPS TX → ESP32 RX, GPS RX → ESP32 TX
- Confirm baudrate is 115200 after configuration (factory default may be 9600)
- Try swapping TX/RX if no communication after verifying baudrate
- Measure voltage at GPS VCC pin - should be 3.0-3.6V

**Problem:** GPS has fix (LED blinking) but no data in app

**Solution:**
- Verify NMEA messages are enabled (not just UBX binary)
- Check Main Talker ID matches app requirements (GP for most apps, GN for Harry's Lap Timer)
- Load the correct preset for your app from web interface
- Verify baudrate is 115200 in both GPS config and ESP32 code

**Problem:** BN220 poor signal quality / slow to acquire

**Solution:**
- BN220 has passive antenna - signal quality will be lower than BN880
- Ensure clear sky view - even thin materials can significantly degrade signal
- Consider upgrading to BN880 (active antenna) or BK280/BK880 (M10 chipset)
- Passive antennas struggle in marginal conditions (urban canyons, heavy cloud cover)
- Expected C/N0: ~30 dBHz (compared to 30-35 dBHz for BN880)

**Problem:** Configuration not persisting after power cycle

**Solution:**
- Some cheap GPS modules lack flash memory - configuration is lost on power down
- Save configuration multiple times in U-Center (known to be unreliable)
- Verify "Store Configurations into BBR/Flash" is selected
- After saving, power cycle and verify settings persist
- If settings don't persist, module may not have flash - consider replacement

#### BK280 / BK880 Series (M10 Chipset)

**Problem:** Can't configure to 25Hz refresh rate

**Solution:**
- Verify your module is genuine M10 chipset (check label)
- M10 supports 25Hz with multiple constellations enabled
- In U-Center: View > Messages View > UBX > CFG > RATE
- Set Measurement Period to 40ms (25Hz = 1000ms/25)
- Ensure Time Source is set to UTC or GPS Time
- Save configuration to flash

**Problem:** Module not recognized in U-Center

**Solution:**
- Try multiple baudrates: 9600, 38400, 115200
- M10 modules may ship with different default baudrates
- Use "Auto Bauding" feature in U-Center
- Check physical connections to FTDI adapter
- Try different USB ports / cables

**Problem:** Performance worse than expected with 25Hz

**Solution:**
- Verify constellation configuration: GPS + Galileo + GLONASS + SBAS recommended
- Check that GSA/GSV messages are polled (not streaming) at low frequency (every 5 seconds)
- Streaming all messages at 25Hz can saturate UART - use selective message configuration
- Monitor ESP32 serial buffer overflow in logs

#### NEO-M8N (Genuine u-blox)

**Problem:** Limited to 5Hz with multiple constellations

**Solution:**
- This is normal behavior for M8N variant - hardware limitation
- M8N: 5Hz max with 2+ constellations, 10Hz with GPS only
- For higher rates with multiple constellations, use M8Q/M8M or M10 series
- Consider if accuracy improvement from multiple constellations worth lower refresh rate for your use case

**Problem:** Module more expensive but seems identical to BN880

**Solution:**
- Genuine u-blox modules have better signal quality (35-40 dBHz vs 30-35 dBHz)
- Better accuracy and consistency in challenging conditions
- Higher manufacturing quality and reliability
- Better support and documentation from u-blox
- Worth the premium for professional/critical applications

### Antenna Issues

**Problem:** Intermittent GPS fix / Signal drops

**Solution:**
- Check antenna cable connections (especially BN880 with separate antenna)
- Ensure antenna has clear sky view - 45° cone from vertical is minimum
- Verify antenna is mounted horizontally (patch antennas must face sky)
- Check for interference sources: phone chargers, LED lights, other RF devices
- Metal surfaces can improve ground plane but can also shield if antenna is too close

**Problem:** Active antenna not working (BN880, BK880)

**Solution:**
- Verify GPS module is providing power to antenna (3.3V on antenna connection)
- Check antenna cable for damage (especially at connectors)
- Active antennas have internal LNA - requires clean power supply
- Measure current draw: active antenna should draw 10-30mA additional
- Try passive antenna temporarily to isolate issue (antenna vs module)

**Problem:** GPS works on bench but not when installed in vehicle/bike

**Solution:**
- Metal fairing/tank can shield GPS signal
- Carbon fiber blocks GPS signals effectively - avoid mounting under CF
- Find location with least obstruction: top of seat cowl, under transparent plastics
- Test signal quality at installation location before finalizing mounting
- May need external antenna with longer cable to reach better location

### Configuration and Communication Issues

**Problem:** U-Center shows communication errors

**Solution:**
- Verify correct COM port selected
- Check FTDI adapter drivers installed (CH340, CP2102, FT232)
- Try lower baudrate (9600) if connection fails at 115200
- Ensure no other software accessing serial port simultaneously
- Windows: Check Device Manager for COM port conflicts
- Linux: Add user to dialout group: `sudo usermod -a -G dialout $USER`

**Problem:** Configuration changes not taking effect

**Solution:**
- After changing any UBX-CFG setting, click "Send" button in U-Center
- Watch for ACK/NAK response in message view
- NAK indicates parameter rejected - check valid ranges in u-blox documentation
- Changes are temporary until saved to flash with UBX-CFG-CFG
- Power cycle module after saving to verify persistence

**Problem:** NMEA messages contain wrong Talker ID

**Solution:**
- Configure UBX-CFG-NMEA Main Talker ID
- Options: 0=System dependent (usually GN), 1=GP, 2=GL, 3=GA, 4=GB
- Most apps require GP (GPS only talker)
- Harry's Lap Timer accepts GN (GNSS multi-constellation)
- Wrong Talker ID is #1 reason apps don't recognize GPS data

### Performance and Accuracy Issues

**Problem:** HDOP values too high / Poor accuracy

**Solution:**
- Ensure multiple constellations enabled (GPS + Galileo + GLONASS)
- Verify clear sky view - buildings/trees cause multipath errors
- Allow 5-15 minutes for almanac download on first fix
- Check number of satellites in use (need 6+ for good accuracy)
- Urban canyon effects can't be eliminated - need clear horizon
- Good HDOP: < 2.0, Acceptable: 2.0-5.0, Poor: > 5.0

**Problem:** Position jumps or drifts when stationary

**Solution:**
- Normal with consumer GPS - typical accuracy 2-3 meters
- Can be improved with SBAS (WAAS/EGNOS) enabled
- Static position will wander within accuracy circle
- Use dynamic model "Automotive" not "Stationary" for vehicle use
- Consider post-processing with RTKLIB if accuracy critical (not real-time)

**Problem:** Altitude readings inaccurate

**Solution:**
- GPS altitude is MSL (Mean Sea Level), not AGL (Above Ground Level)
- Vertical accuracy 1.5x worse than horizontal (typical: 3-5 meters vs 2-3 meters)
- Barometric altitude sensor needed for precise altitude
- Many track apps correct altitude using track database

### Testing and Validation

**Problem:** How to verify GPS is working correctly?

**Solution:**
1. **Check LED indicators** (BN modules):
   - Red LED blinking every second = GPS has fix
   - Red LED solid or irregular = No fix

2. **Use U-Center via TCP/IP**:
   - Connect BonoGPS via WiFi
   - U-Center: Receiver > Connection > Network > TCP
   - IP: 10.0.0.1 (AP mode) or bonogps.local (Client mode)
   - Port: 1818
   - View satellite constellation and signal strength

3. **Check web interface**:
   - Navigate to Device > Info
   - Should show GPS status, number of satellites, fix type

4. **Monitor serial output**:
   - Enable debug logging (`Core Debug Level > Debug`)
   - Check for NMEA sentences in serial monitor
   - Verify message format matches app requirements

**Problem:** How to compare GPS module performance?

**Solution:**
- Place modules side-by-side with clear sky view
- Record C/N0 (carrier-to-noise) values - higher is better
- Compare time to first fix (TTFF) - should be < 30 seconds (hot start)
- Check number of satellites tracked simultaneously
- Monitor HDOP values - lower is better
- Static test: measure position scatter over 10+ minutes
- Dynamic test: Record same track with different modules and compare

### Common Configuration Mistakes

**Problem:** Checklist of common configuration errors

**Common Mistakes:**
1. ❌ Wrong baudrate (ESP32 expects 115200, GPS still at 9600)
2. ❌ NMEA messages disabled (only UBX binary enabled)
3. ❌ Wrong Main Talker ID (app expects GP, GPS sending GN)
4. ❌ Configuration not saved to flash (lost on power cycle)
5. ❌ Too many messages streaming at high rate (UART overflow)
6. ❌ GSA/GSV streaming instead of polling (bandwidth waste)
7. ❌ Navigation mode set to "Stationary" instead of "Automotive"
8. ❌ TX/RX not crossed (GPS TX must go to ESP32 RX)
9. ❌ SBAS disabled (loses accuracy improvement)
10. ❌ Update rate too high for chipset (M8N can't do 10Hz with multi-GNSS)

### Getting Help with GPS Issues

If problems persist:
1. Test GPS with U-Center directly (bypass ESP32) to isolate hardware vs software issues
2. Check [u-blox support portal](https://portal.u-blox.com) for module-specific documentation
3. Review [GitHub Discussions - GPS topics](https://github.com/renatobo/bonogps/discussions/categories/q-a)
4. Post issue with:
   - GPS module model and chipset (M8/M9/M10)
   - Configuration used (attach U-Center config if possible)
   - U-Center screenshots showing satellite view and message traffic
   - Description of environment (indoor/outdoor, vehicle type, mounting location)

## References

- [ublox M8 Receiver description](https://www.u-blox.com/sites/default/files/products/documents/u-blox8-M8_ReceiverDescrProtSpec_%28UBX-13003221%29.pdf)
- [Assist Now](https://portal.u-blox.com/s/question/0D52p00008eSdzE/how-to-enable-and-flash-assistnow-autonomous-on-zoem8b)
- [SBAS](https://github.com/cleanflight/cleanflight/blob/master/docs/Gps.md)
- [Enable Galileo](https://github.com/iNavFlight/inav/wiki/Ublox-3.01-firmware-and-Galileo)
- [UBX Tool](https://gpsd.io/ubxtool-examples.html)
- Setting PORT, Frequency and save settings from [freematics](https://freematics.com/forum/viewtopic.php?t=1759)
- [https://learn.sparkfun.com/tutorials/getting-started-with-u-center-for-u-blox/all](https://learn.sparkfun.com/tutorials/getting-started-with-u-center-for-u-blox/all)

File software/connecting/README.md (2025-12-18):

# Setup and configuration of mobile apps

**⏱️ Time:** 10-20 minutes per app | **🎯 Difficulty:** Beginner to Intermediate (varies by platform)

This directory contains detailed setup instructions for connecting BonoGPS to various lap timer applications.

## Supported Apps

| App | iOS | Android | Recommended Connection | Features | Setup Guide |
| --- | --- | --- | --- | --- | --- |
| Harry's Lap Timer | ✓ | ✓ | BLE (iOS), BT-SPP (Android) | Satellite view, 20Hz support, battery status | [Guide](harrylaptimer) |
| TrackAddict | ✗ | ✓ | BT-SPP | Standard lap timing | [Guide](trackaddict) |
| RaceChrono | ✓ | ✓ | TCP-IP (iOS), BT-SPP (Android) | Satellite view, clean UX | [Guide](racechrono) |
| RaceTime | ✗ | ✓ | BT-SPP | Lightweight, simple setup | [Guide](racetime) |

## Quick Start

1. Choose your app from the table above
2. Follow the detailed setup guide for your platform
3. Load the appropriate preset from the BonoGPS web interface (*Device > Load Preset*)
4. Connect and start recording!

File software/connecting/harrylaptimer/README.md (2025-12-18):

# Connecting to Harry's LapTimer

**⏱️ Time:** 10-15 minutes | **🎯 Difficulty:** Beginner (iOS BLE), Intermediate (Android BT-SPP or TCP/IP)

- [Connecting to Harry's LapTimer](#connecting-to-harrys-laptimer)
  - [Features](#features)
  - [iOS Bluetooth Low Energy setup](#ios-bluetooth-low-energy-setup)
  - [iOS and Android TCP/IP setup](#ios-and-android-tcpip-setup)
  - [Android BT-SPP Setup](#android-bt-spp-setup)
  - [GPS Configuration for NMEA messages](#gps-configuration-for-nmea-messages)

More info at [https://www.gps-laptimer.de/](https://www.gps-laptimer.de/), where you can also find a very good [user and developer forum](http://forum.gps-laptimer.de/viewforum.php?f=2). It offers the largest set of customizable options to build your own external device and it is the only supported platform for iOS phones via Bluetooth Low Energy.

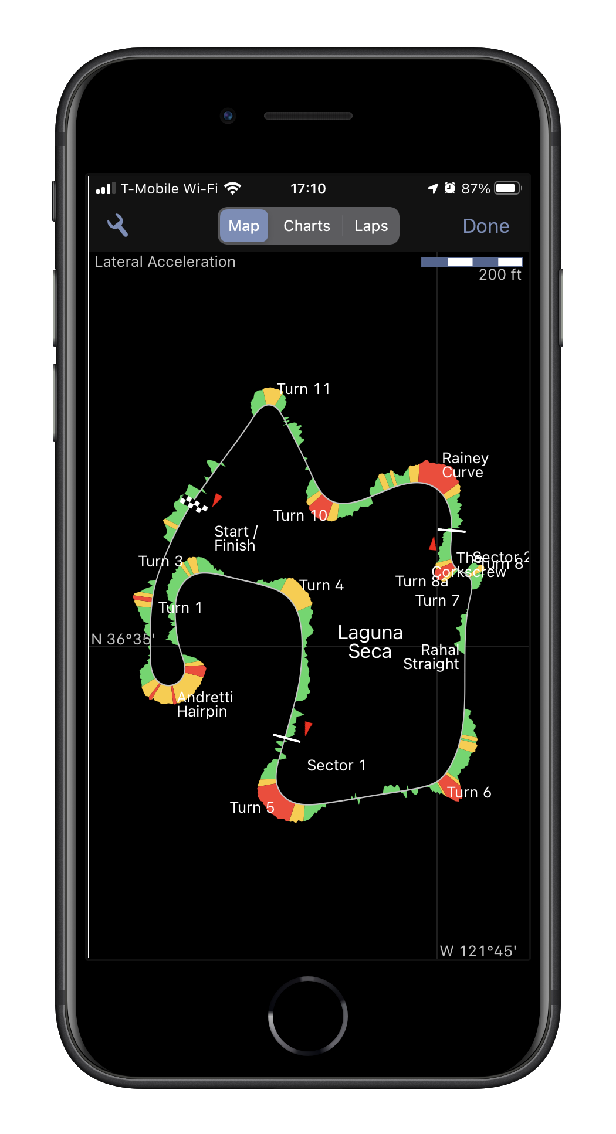
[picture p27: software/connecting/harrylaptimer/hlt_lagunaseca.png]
Example


## Features

- NMEA parsing offered by HLT directly: `GxRMC`+`GxGGA`+`GxGBS` messages
- Enable or Disable `GxGSV`+`GxGSA` as needed, with a lower update frequency selectable for 1, 2, or 5 sec (as [instructed by Harry](http://forum.gps-laptimer.de/viewtopic.php?t=4359))
- tested up to v24.9.1
- from v1.2 of BonoGPS, battery information on certain ESP32 boards (for example LOLIN D32 PRO) is available so that HLT can provide it back to you while using the app

Connections

- iOS and Android: TCP/IP port 8118. This is the easier option, yet it prevents connecting other devices to your mobile phone (e.g. an action camera or an ODBII device) so it's not recommended
- iOS: BLE tested on iPhone (tested from 7 to 15). BLE nicely handles up to 20Hz GPS update rates when `GSV`/`GSA` streaming is disabled or polled at low frequencies (e.g. every 5 seconds)
- Android: BT-SPP tested on Android, 10Hz and  `GSV`/`GSA` at higher polling frequency (streaming saturates the UART connection on the GPS itself)

After configuring the connection, your unit shows up in the Sensors List as 'Custom [BTLE/TCP-IP] GNSS' device

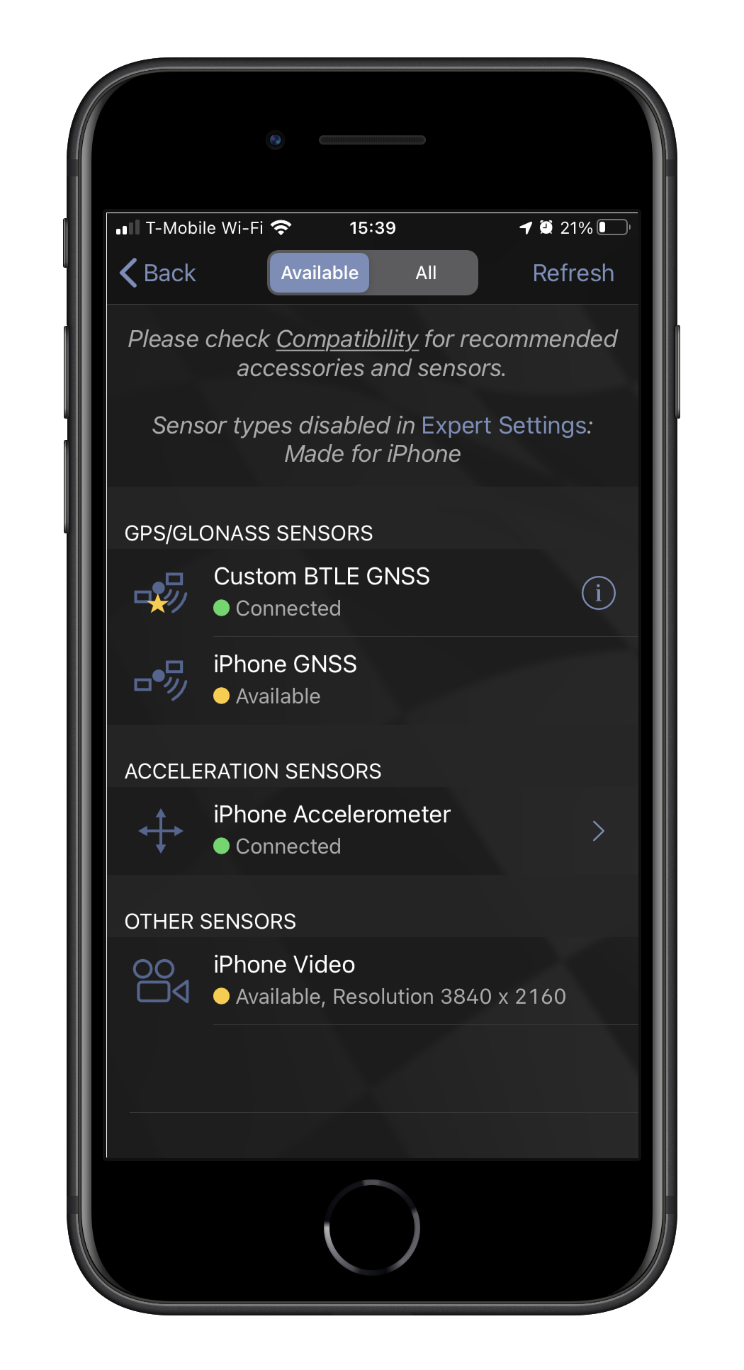
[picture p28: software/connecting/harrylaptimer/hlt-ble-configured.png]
Configured


now you can open the '**GPS**' page and check that you are receiving valid GPS data

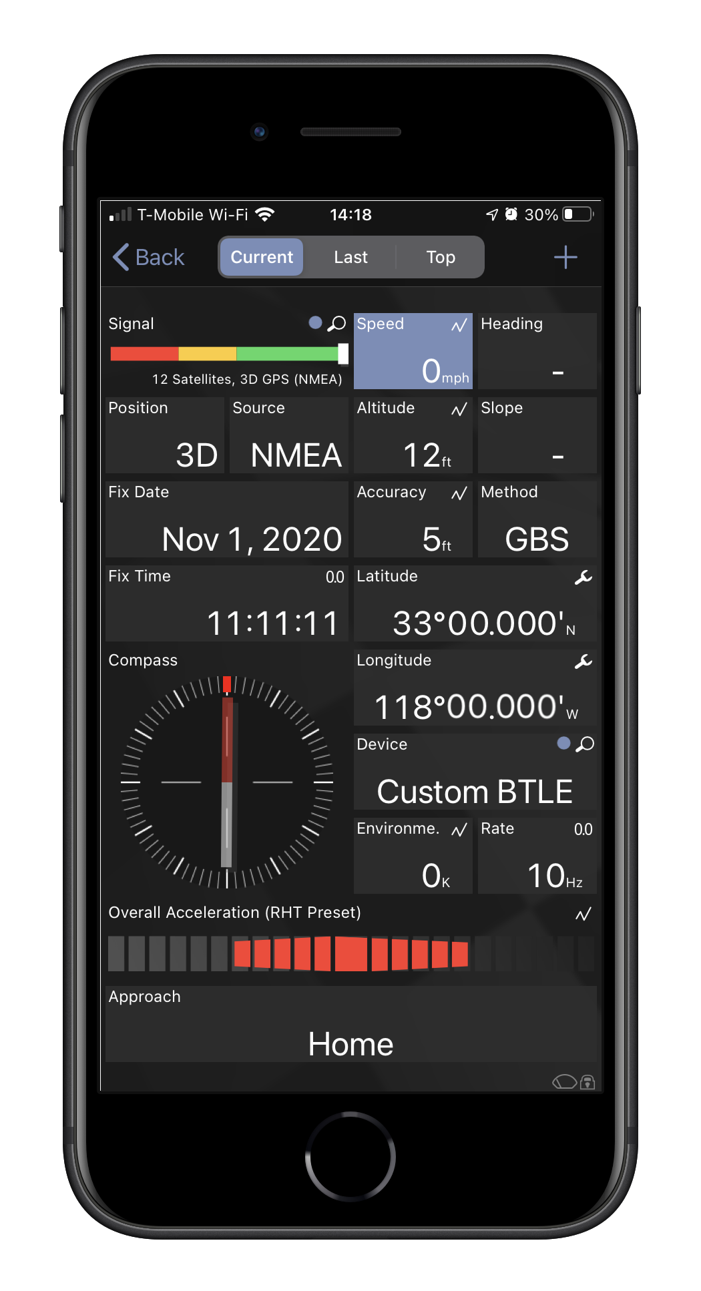
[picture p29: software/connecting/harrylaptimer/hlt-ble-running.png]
Running


with a paid add-on, you can also see the satellites constellation map

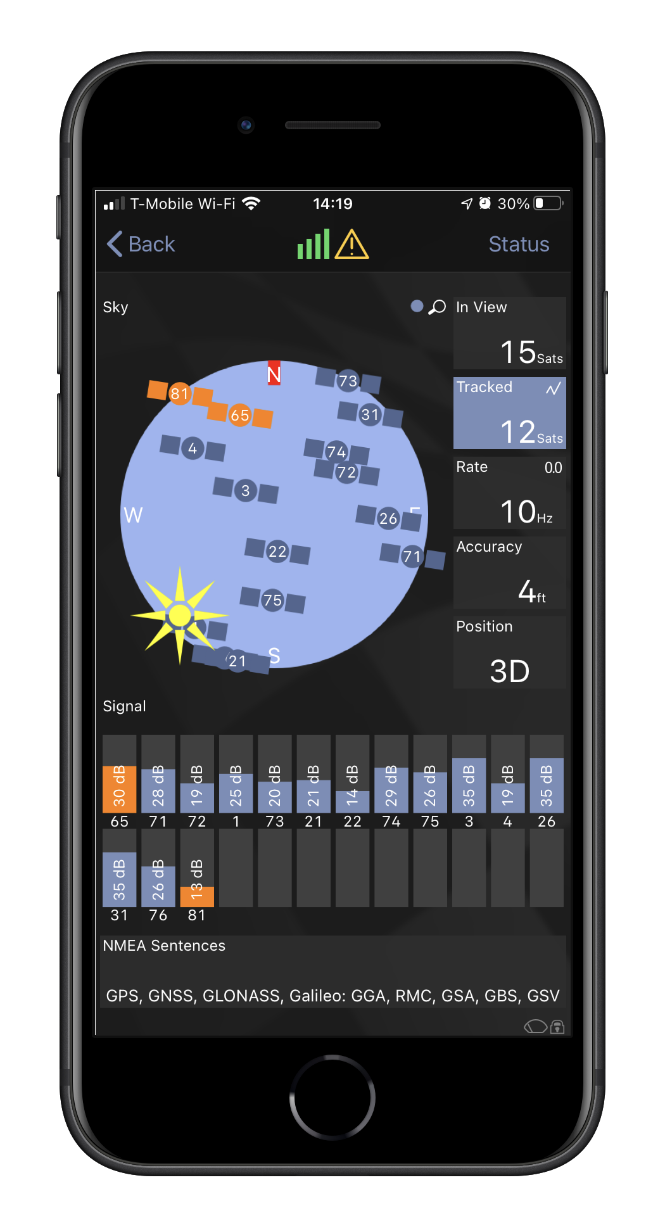
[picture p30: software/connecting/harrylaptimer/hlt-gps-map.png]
GPS Map


## iOS Bluetooth Low Energy setup

Go to *Administration > Settings > Expert Settings* and

- within 'accessory tweaks', turn on 'Use Bluetooth LE Sensors'
- within 'custom btle gps adapter', set 'Peripheral Name' to `BonoGPS-XXXX` where `XXXX` is the id of your device as shown in the title of the configuration page
- within 'custom btle gps adapter', set 'Service UUID' to  **1819** (standard for `SERVICE_LOCATION_AND_NAVIGATION_UUID`)
- within 'custom btle gps adapter', set 'Read Characteristic UUID' **2A67** (standard for `CHARACTERISTIC_LOCATION_AND_SPEED_CHARACTERISTIC_UUID`)

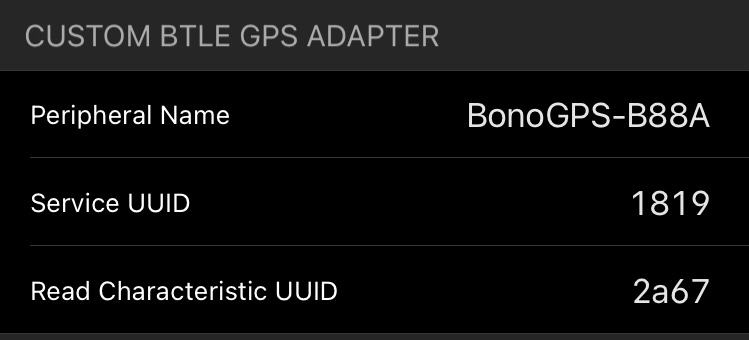
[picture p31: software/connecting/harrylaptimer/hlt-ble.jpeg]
BLE


Click on the (i) to see more information about what HLT collects
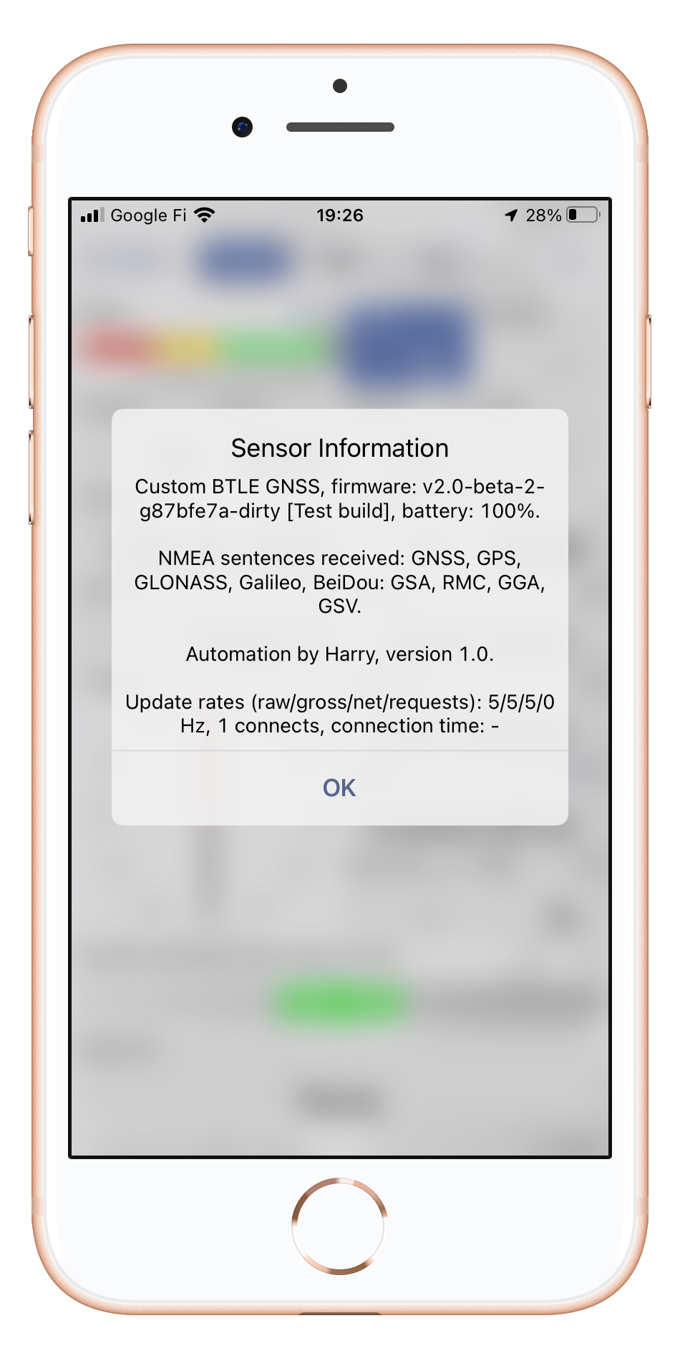
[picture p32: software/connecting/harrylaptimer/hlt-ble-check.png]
BLE with battery


If your ESP32 board has a battery and you have enabled the `SHOWBATTERY` feature, it will be reported as battery %.

## iOS and Android TCP/IP setup

Go to *Administration > Settings > Expert Settings* and

- within 'accessory tweaks', turn on 'Use WiFi Sensors'
- within 'custom WiFi gps adapter', set Connection Type `TCP/IP`, 'Device IP Address' to `10.0.0.1`, TCP Port to `1818`

WiFi

## Android BT-SPP Setup

Go to *Sensor List* and

- Pair your bluetooth device as any BT device on your phone
- Click on the _Bluetooth +_ icon at the top of the page
- Select your newly paired BonoGPS device
- Specify _use as GPS_

Configuration panel

Use the (i) icon to check the messages being exchanged

List of received messages

Now head to *GPS* to verify it is correctly working

GPS page showing status and information received

## GPS Configuration for NMEA messages

According [to this good reference message](http://forum.gps-laptimer.de/viewtopic.php?f=19&t=4359) on the forum

> I recommend to enable RMC+GGA+GSA+GSV, with RMC+GGA at 10 Hz and GSA+GSV at 1 Hz or lower.

- `GxGSA` and `GxGSV` are polled every 5 seconds (2.5 seconds each) with `$EIGNQ,GSA*2D` and `$EIGNQ,GSV*3A` respectively
- `GxGGA`, `GxRMC`, and `GxGBS` are streaming

HLT is the only app that easily works with the GN talker id, so no translation of Talker ID was necessary.

**See also:**
- [GPS Configuration Guide](../../../hardware/GPS) - How to set up NMEA messages
- [Main Troubleshooting FAQ](../../../README.md#troubleshooting-and-faq) - Common connection issues
- [Other Supported Apps](../) - Compare with RaceChrono, TrackAddict, RaceTime

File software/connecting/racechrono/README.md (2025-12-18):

# RaceChrono

**⏱️ Time:** 10-15 minutes | **🎯 Difficulty:** Beginner | **Prerequisites:** Load RaceChrono preset from BonoGPS web interface

- [RaceChrono](#racechrono)
  - [Setup over BT-SPP on Android](#setup-over-bt-spp-on-android)
  - [Setup over WiFi on iOS](#setup-over-wifi-on-ios)
  - [GPS configuration for NMEA messages](#gps-configuration-for-nmea-messages)

The lap timer with the cleanest UX currently supported: [https://racechrono.com/](https://racechrono.com/)

- tested with v7.0.10 free (thus satellites view untested) on Android
- BT-SPP on Android
- TCP-IP for iOS
- GSA+GSV polling at 5 sec

## Setup over BT-SPP on Android

Open settings from the gear icon in the main page, then add a bluetooth receiver selecting your BonoGPS unit

Setup

When you start recording (the round big "start" button) if everything goes well you'll be able to see the constellations of satellites in the dashboard view

Display

When you click on the lower left green "swipe up" icon, you'll be able to see further information about the GPS status

Information

## Setup over WiFi on iOS

Make sure you have connected your iPhone to the AP on the BonoGPS device as you would to perform the setup

Open settings from the gear icon in the main page, then add an Internal sensor

Information

Select "RaceChrono DIY" as the next option 

Information

Under the "Add other device" select TCP/IP 

Information

This next section requires several selections, step 1, enable the "NMEA 0183" slider 

Information

On the same page as above now set your target IP address and port, the default is shown below but if you have changed the network and the port in the code please put the updated values in. 

Information

When you start recording (the round big "start" button) if everything goes well you'll be able to see the constellations of satellites in the dashboard view

Display

When you click on the lower left green "swipe up" icon, you'll be able to see further information about the GPS status

Information

## GPS configuration for NMEA messages

Instructions directly from the SW Developer of RaceChrono in the support forum point out [here](https://racechrono.com/forum/discussion/comment/11252/#Comment_11252) and [here](https://racechrono.com/forum/discussion/1421/best-settings-for-qstarz818xt)

- Sentences need to start with `$GP`
- Only `GGA+RMC` or `RMC+VTG+ZDA` combinations are used
- `GSA+GSV` are optional
- `GBS` sentence is not used

This means

- Main Talker ID = GP
- `GSA` and `GSV` every 5 seconds, with only `GSV` restricted to GP

**See also:**
- [GPS Configuration Guide](../../../hardware/GPS) - How to set up GP Talker ID and NMEA messages
- [Main Troubleshooting FAQ](../../../README.md#troubleshooting-and-faq) - Connection and GPS issues
- [Other Supported Apps](../) - Compare with Harry's Lap Timer, TrackAddict, RaceTime

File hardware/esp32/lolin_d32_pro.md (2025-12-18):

# LOLIN D32 PRO

- [No BOOT Button](#no-boot-button)
- [Serial2 PINs need to be assigned](#serial2-pins-need-to-be-assigned)
- [Battery monitoring](#battery-monitoring)
- [Turning on and off when on a battery](#turning-on-and-off-when-on-a-battery)
- [External LEDs for WiFi and Active](#external-leds-for-wifi-and-active)
- [Complete example schematic](#complete-example-schematic)

## No BOOT Button

You need to supply an external temporary button to enable the WiFi switching option that the builtin BOOT button provides on the DevKit board.

Its pin is defined in `include/bonogps_board_settings.h` as  `WIFI_MODE_BUTTON`

## Serial2 PINs need to be assigned

This board does not have dedicated definitions for Serial2, so you need to pick a couple of PINs and assign them to the TX/RX function.

These pins need to be defined in `include/bonogps_board_settings.h` as `RX2` and `TX2`

The recommended options (defined in `bonogps_board_settings`) are

- RX2 -> GPIO_NUM_4 (aka IO4, pin 12)
- TX2 -> GPIO_NUM_2 (aka IO2, pin 14)

pin out lolin d32 pro

Note: IO4 is used by the SD Card, so this might have to be changed if you use it.

## Battery monitoring

`GPIO_35`  provides Battery voltage with an A2D conversion (check this [tutorial](https://www.youtube.com/watch?t=88&v=yZjpYmWVLh8&feature=youtu.be)).

This replicates the functionality of *battery fuel gauge* available on the [Lipo Rider Plus](https://wiki.seeedstudio.com/Lipo-Rider-Plus/), but printed directly on the header of the main page of the web configuration interface.

main page header

This is the simple function used to collect voltage

```C
analogRead(GPIO_BATTERY) / 4096.0 * 7.445
```

Percentage is based on the common LiPo values as charged by its [TP4054](https://datasheetspdf.com/pdf/1090540/NanJingTopPower/TP4054/1): linear scale from 3.3V (0%) to 4.2V (100%).

These are enabled by the preprocessing macro `SHOWBATTERY`

## Turning on and off when on a battery

Since the battery is always attached, the easiest option is to use the `EN` pin by tying it to the ground. This disables the onboard voltage regulator ME6211 (check [schematics](https://www.wemos.cc/en/latest/_static/files/sch_d32_pro_v2.0.0.pdf))

## External LEDs for WiFi and Active

If you fully enclose your device, you should have external LEDs to show that the device is on and what type of WiFi mode.

- pick a low power LED (e.g. a 3mm red or yellow)
- compute what resistance you need (suggested: [LED Calculator](https://www.hobby-hour.com/electronics/ledcalc.php))

Now let bonogps know using these macros

- `LED_ACTIVE_EXTERNAL` : define it to the pin where the Active LED is connected
- `LED_WIFI` : define it to the pin where the Active LED is connected

## Complete example schematic

Considering

- `LED_ACTIVE_EXTERNAL` defined as `GPIO_NUM_14`, with LED at 20 mA so closest resistor off the shelf is 47 Ohm
- `LED_WIFI` defined as `GPIO_NUM_12`, with LED at 20 mA so closest resistor off the shelf is 47 Ohm
- `WIFI_MODE_BUTTON` defined as `GPIO_NUM_25`, with temporary switch
- external On/Off locking switch
- LiPo battery

This is how the schematics looks like

Lolin d32 pro schematic

BN-220 is shown, but it does not matter - it could be any of the supported ones.

[Fritzing source file](lolin_d32_pro.fzz)

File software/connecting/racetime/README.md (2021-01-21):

# Racetime

- [Setup](#setup)
- [GPS Configuration for NMEA messages](#gps-configuration-for-nmea-messages)

Latest supported app: [https://www.racetimeapp.com/en/](https://www.racetimeapp.com/en/)

- tested with v3.3.8 lite
- BT-SPP is the only option
- `GPGGA`, `GPRMC`, `GPVTG`, `GPGLL` enabled, with main talker id GP

## Setup

Open the app, an icon to connect an external bluetooth adapter is displayed

Setup

From the connection page, search your device

Connecting

When activated, the satellite icon lets you check the connection to the device

Actiated

The location icon lets you check the quality of signal, showing a red exclamation point if something is not in place correctly

Signal

## GPS Configuration for NMEA messages

According to information shared via email with the developer Roberto Morini, RaceTime supports

- `GPGSA`
- `GPGGA`
- `GPRMC`
- `GPVTG`
- `GPGLL`

which means we have to enable the _Main Talker id = GP_ option.
As there is no display of satellite positions, `GPGSA` is not enabled.

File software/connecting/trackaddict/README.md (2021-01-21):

# TrackAddict

- [Configuration](#configuration)
- [GPS Configuration for NMEA messages](#gps-configuration-for-nmea-messages)

Another very popular app, [https://www.hptuners.com/product/trackaddict-app/](https://www.hptuners.com/product/trackaddict-app/)

Example

- tested with v4.6.0 on Android
- BT-SPP is the only option
- it needs a specific set of NMEA messages configurations
- NBP was coded, yet not going to matter for TrackAddict as reported in [the forum](https://forum.hptuners.com/showthread.php?78403-GPS-over-NBP&highlight=gps)  

Please make sure that your BonoGPS unit is connected before recording a session, it will default back to internal GPS without informing you otherwise in a clear way.

## Configuration

In the main page, click on the gear icon, scroll down to "Input position and speed" and select Bluetooth GPS

Setup

Assuming everything well, the main page will now show the new refreshed rate of your BonoGPS unit

Connect

You can click on the green line at the bottom to find out more and validate the connection parameters

Check

Once you have setup a connection, remember to check you are using the external GPS when starting the recording of your session

## GPS Configuration for NMEA messages

> Track Addict is similarly configured to only accept NMEA messages with a GPS talker ID (i.e., `GPRMC` instead of `GNRMC`) [as discussed in the forum](https://forum.hptuners.com/showthread.php?69123-Track-addict-external-GPS&highlight=gps)
> Ideally, TrackAddict wants `GPRMC`, `GPGGA`, and `GPGLL` messages, with `GPRMC` and `GPGGA` being the recommended minimum.

These messages are enabled

- `GPGGA`
- `GPRMC`
- `GPGLL`

The _Main Talker id = GP_ option is required.

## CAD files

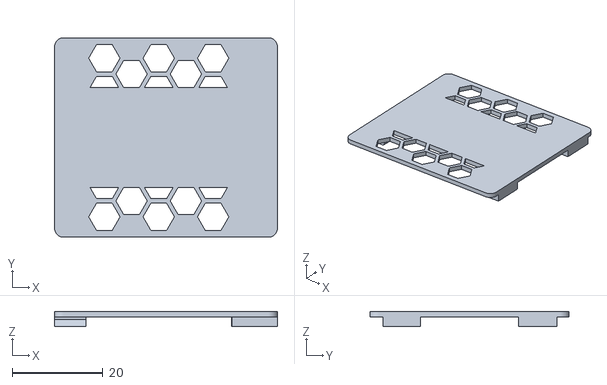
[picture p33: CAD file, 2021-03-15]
hardware/assembled/bonogps_panigale_battery_slider.stl
49.2 x 44.0 x 3.20

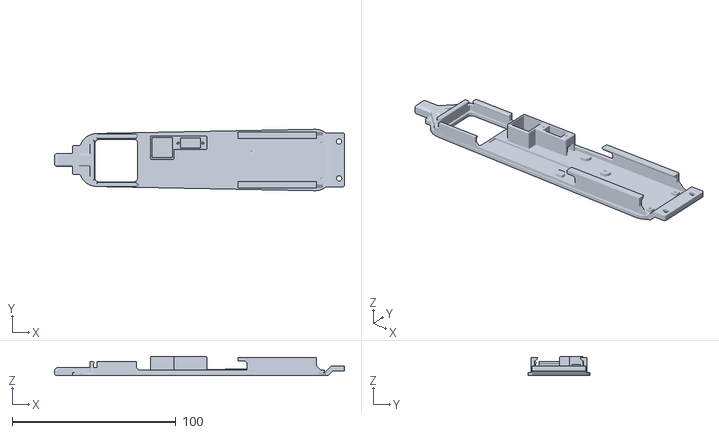
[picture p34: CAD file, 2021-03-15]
hardware/assembled/bonogps_panigale_baseboard.stl
177.0 x 37.6 x 11.8

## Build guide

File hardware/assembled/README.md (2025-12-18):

# A couple of working prototypes that don't look fancy but get the job done

- [A couple of working prototypes that don't look fancy but get the job done](#a-couple-of-working-prototypes-that-dont-look-fancy-but-get-the-job-done)
  - [Integrated in seat cowl (with BN880) of a Ducati Panigale 959 with 3D printed base](#integrated-in-seat-cowl-with-bn880-of-a-ducati-panigale-959-with-3d-printed-base)
    - [Rendering of 3D model](#rendering-of-3d-model)
    - [Picture of installed model](#picture-of-installed-model)
    - [3D printing](#3d-printing)
  - [Transparent case (with BN220)](#transparent-case-with-bn220)

Hardware is similar for both and it's mostly based on things I could easily find:

- basic [ESP32 DEVKIT](https://www.amazon.com/D-FLIFE-Development-Dual-Mode-Microcontroller-Integrated/dp/B08DR31G4G) board
- [BN880](https://www.amazon.com/Geekstory-Navigation-Raspberry-Aircraft-Controller/dp/B078Y6323W) (better as it has an active antenna) GPS or [BN220](https://www.amazon.com/Beitian-Navigation-Raspberry-Betaflight-Aircraft/dp/B07WM1GFY8) (cheaper)
- Li-Ion battery
- [JST2.0 cables](https://www.amazon.com/gp/product/B07NWD5NTN/ref=ppx_yo_dt_b_asin_title_o05_s00?ie=UTF8&psc=1) to connect battery to LiPo charger and LiPo charger to ESP32 power inputs (Vin, GND)

In one case, the unit is assembled within a left-over Raspberry Pi case (the transparent case helps in checking the light status) and a LiPo charger (Seeedstudio [LiPo Rider Plus](https://wiki.seeedstudio.com/Lipo-Rider-Plus/) charger - the first LiPo charger I found at MicroCenter while shopping, with a couple of nice features such as a fuel gauge)

A recommended and supported ESP32 board is [Wemos/LOLIN D32 Pro](https://www.wemos.cc/en/latest/d32/d32_pro.html) which has some benefits

- integrated LiPo charger
- more flash memory and PSRAM
- SD slot builtin

This software runs on it (be sure to select it within the Arduino IDE or to use the tasks named 'lolind32pro' within PlatformIO or to select the right definition in [include/bonogps_board_settings.h](include/bonogps_board_settings.h))

## Integrated in seat cowl (with BN880) of a Ducati Panigale 959 with 3D printed base

**⏱️ Time:** 3-4 hours (plus 12-15 hours for 3D printing) | **🎯 Difficulty:** Intermediate to Advanced | **Prerequisites:** Soldering skills, 3D printer access, basic electronics knowledge

The GPS antenna is underneath the very end of the tail, with minimal plastic over it and with the best clear line of sight of any other location on the bike.

A simple 3D printed board is used to hold all components in place

- GPS: BN880 or BK880 or BK280 (same form factor)
- ESP32: Lolin d32pro
- LiPo Battery (2000 mAh will last a full day of riding)
- A small on/off button
- A momentary button to serve as WiFi mode selection button (equivalent to BOOT on other ESP32 models)

Please note the battery holder is not stable, after several months of use it started randomly coming loose. A redesign of that part would be best.

### Rendering of 3D model

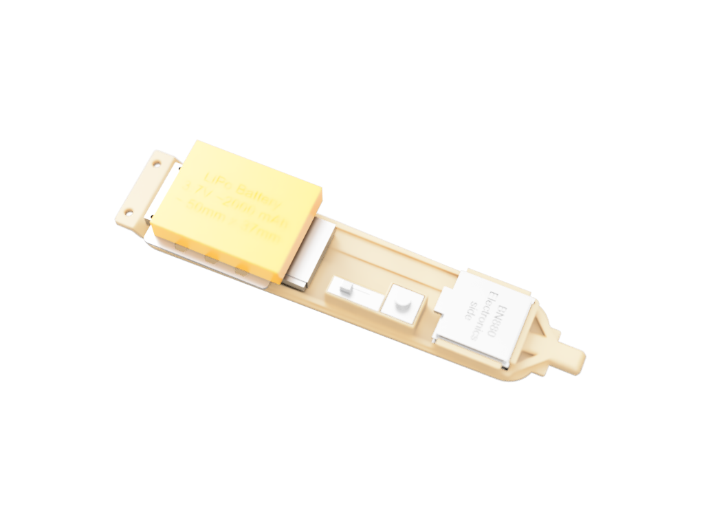
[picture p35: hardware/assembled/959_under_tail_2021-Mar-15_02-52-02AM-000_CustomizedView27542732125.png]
959 rendering


### Picture of installed model

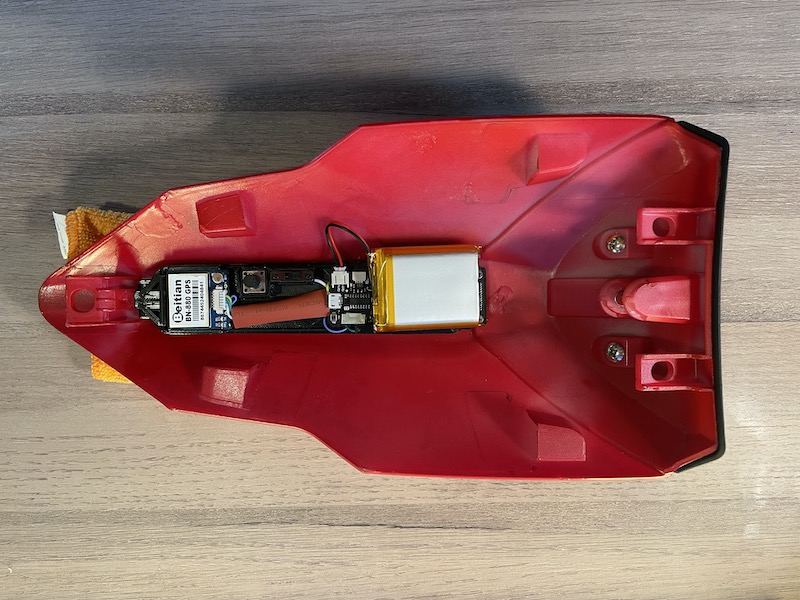
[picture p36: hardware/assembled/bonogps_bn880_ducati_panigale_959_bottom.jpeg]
959 3D printed base


### 3D printing

- [base board](bonogps_panigale_baseboard.stl)
- [battery slider](bonogps_panigale_battery_slider.stl)

If you have different components, [source files for Fusion 360 are also available](BonoGPS%20-%20Panigale%20899%201199%20959%201299.f3d).

Schematics are simple:

- a GPS serial connection TX+RX and its power
- a on/off switch that disables power to the internal Lolin D32 Pro regulator
- a momentary switch to act as WiFi mode selector, in lieu of a Boot button

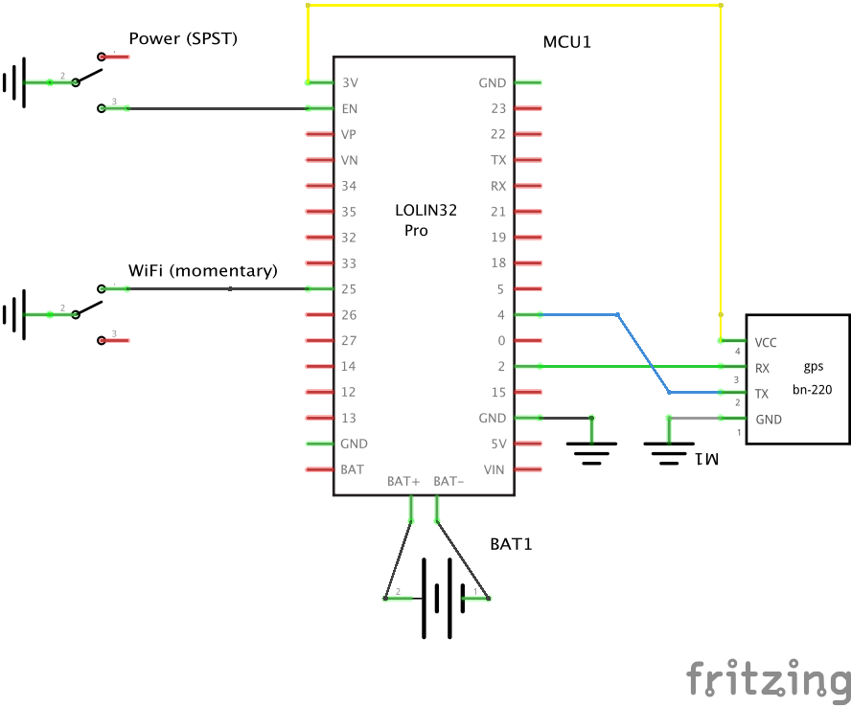
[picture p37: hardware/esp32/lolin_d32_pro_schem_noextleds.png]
schematic


Steps - [here a video of how all pieces fit together](959%20under%20tail%20v11.mp4)

- print the base board
- print the battery slider
- connect/solder the connector cables between ESP32 and GPS (4 wires): VCC to 3V, RX to pin 0, TX to pin 4, GND to GND
- connect/solder micro on/off switch and momentary button cables (leave cables open on the end towards ESP32) (3 wires). The on/off connects GND to EN pin or it leaves it open, the momentary button connects pin 25 to GND
- connect/solder the open end of cables for switches to ESP32
- mount the ESP32 in place with 3 small screws (I suggest M1.7)
- slide in BN880
- connect the BN880 with its connector
- use a zip tie or double sided tape or strong velcro to hold the battery on the battery slider
- carefully slide in the battery slider and make sure it holds its place: this is delicate so make sure you don't break the support structures
- connect the LiPo JST battery

.. and you are done! Don't forget you need to store a base configuration on your GPS before it's ready for use (check [GPS configuration](../GPS/README.md))

**See also:**
- [GPS Configuration Guide](../GPS) - **Critical:** Configure before first use
- [Software Build Guide](../../software/building) - Flash firmware to ESP32
- [Connecting Apps](../../software/connecting) - Link BonoGPS to lap timer apps

## Transparent case (with BN220)

**⏱️ Time:** 1-2 hours | **🎯 Difficulty:** Beginner | **Prerequisites:** Basic soldering, double-sided tape or velcro

A small 650mAh battery gives ~ 4 hrs of autonomy, I repurposed one that was supposed to be used for a digital camera

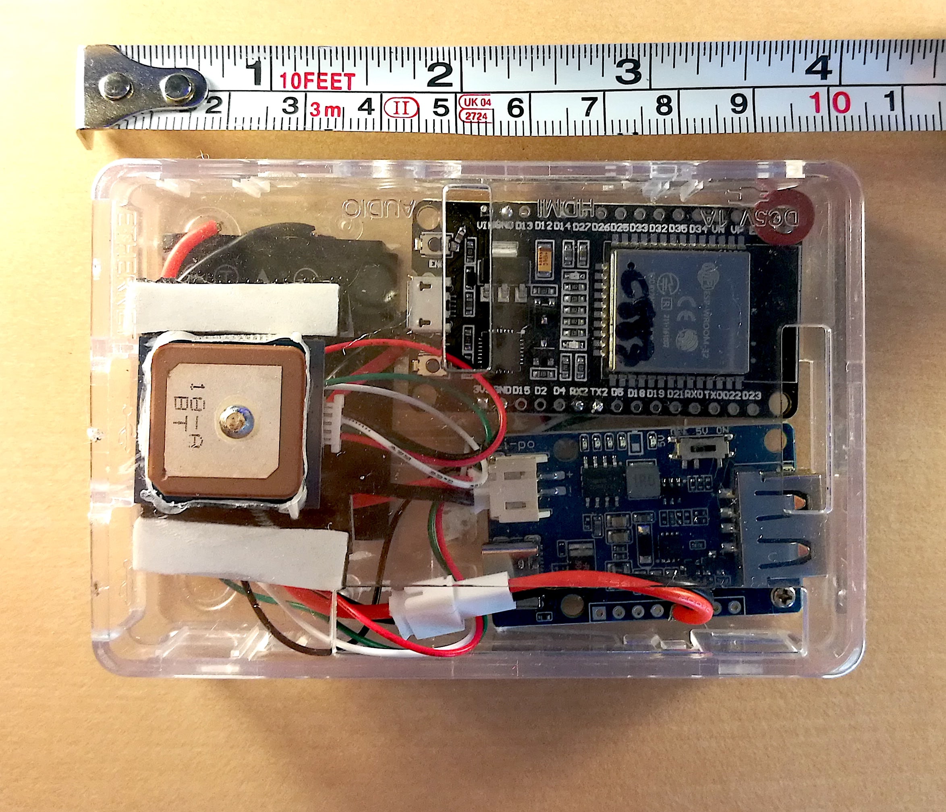
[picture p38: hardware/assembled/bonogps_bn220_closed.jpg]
Closed


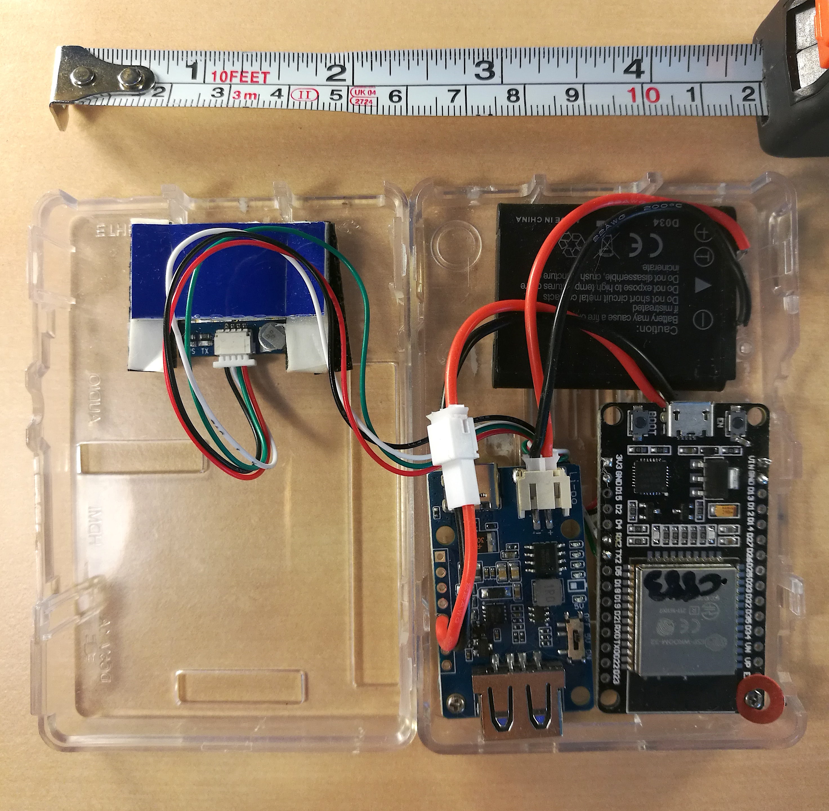
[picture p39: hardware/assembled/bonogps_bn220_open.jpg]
Open


From the side

I used double sided tape to attach this on top of a back seat/seat cowl or to secure it inside the fairing: an example for a Ducati Panigale 959/1299 here below:

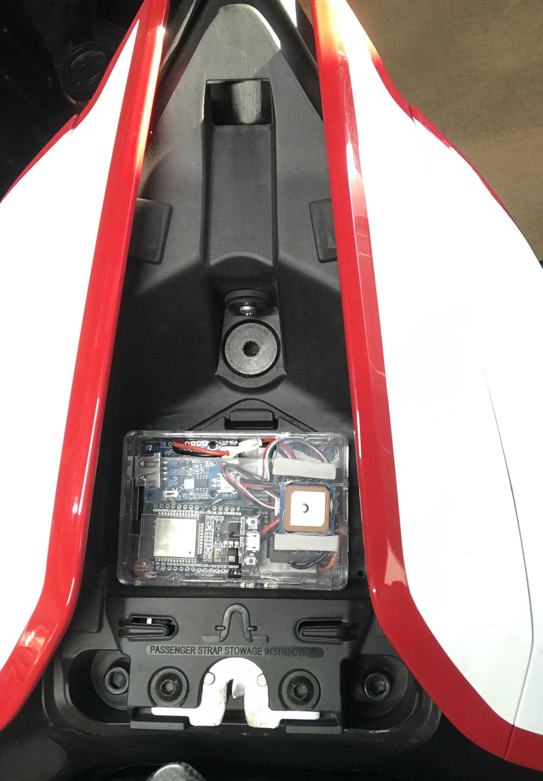
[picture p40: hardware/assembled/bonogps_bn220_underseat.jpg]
Inside


## Hardware Assembly Troubleshooting

### Wiring and Connection Issues

**Problem:** Device not powering on

**Solution:**
- Check battery voltage with multimeter (should be 3.7-4.2V for LiPo)
- Verify battery polarity (red=positive, black=negative)
- Test battery under load (weak batteries may show voltage but can't supply current)
- Check on/off switch connections (EN pin to GND = off, EN floating = on)
- For LOLIN D32 PRO: verify JST connector polarity matches board markings
- Try powering via USB to isolate battery/switch issues

**Problem:** ESP32 powers on but GPS doesn't work

**Solution:**
- Verify GPS power connections: VCC to 3.3V, GND to GND
- **Critical:** Do NOT connect GPS VCC to 5V - will damage GPS
- Check for loose connections in GPS connector
- Measure voltage at GPS VCC pin (should be 3.0-3.6V with GPS connected)
- If using dupont wires, ensure good mechanical connection (crimp quality)
- Solder connections preferred for reliability in vibration environment

**Problem:** Intermittent connection / Device works on bench but not when riding

**Solution:**
- Vibration from riding can loosen connections
- **Solder all critical connections** - do not rely on breadboard/dupont wires
- Add hot glue or strain relief to solder joints
- Secure GPS module with zip ties or mounting screws
- Check that wires aren't pulling on connections
- Consider using crimped JST/Molex connectors for removable connections

**Problem:** Wrong TX/RX connections

**Solution:**
- **Remember: TX → RX and RX → TX (crossed)**
- GPS TX (transmit) connects to ESP32 RX (receive)
- GPS RX (receive) connects to ESP32 TX (transmit)
- Common mistake: connecting TX to TX and RX to RX
- If no GPS data, try swapping TX/RX wires
- Double-check pinout diagram for your specific ESP32 board

### ESP32 Board Specific Issues

**Problem:** Generic ESP32 DevKit - which pins to use?

**Solution:**
- **UART2 default pins:**
  - RX2: GPIO16 (RX2)
  - TX2: GPIO17 (TX2)
- **Alternative if conflicts:**
  - Any GPIO can be used with Serial2.begin(baudrate, config, RX_pin, TX_pin)
  - Avoid: GPIO 6-11 (flash), GPIO 0 (boot), GPIO 2 (boot)
  - Good choices: GPIO 16, 17, 25, 26, 27, 32, 33
- Check `bonogps_board_settings.h` for configured pins
- Update code if using different pins

**Problem:** LOLIN D32 PRO specific issues

**Solution:**
- **No default Serial2 pins** - must be configured in code
- Default configuration uses:
  - RX2: GPIO4 (conflicts with SD card if used)
  - TX2: GPIO2
- **Battery not charging:**
  - Ensure LiPo battery has built-in protection circuit
  - Use 1S LiPo only (3.7V nominal)
  - Charging current: ~500mA via USB
- **No BOOT button:**
  - Must add external momentary button between GPIO25 and GND
  - Define `WIFI_MODE_BUTTON` in board settings
- See [LOLIN D32 PRO guide](../esp32/lolin_d32_pro.md) for complete wiring

**Problem:** ESP32 keeps resetting / Brown-out detected

**Solution:**
- Insufficient current from power source
- USB power: Some ports provide only 100mA (need 500mA+)
- Battery: Weak or depleted battery can't provide peak current
- GPS + ESP32 + WiFi/BT can draw 300-500mA peaks
- **Solutions:**
  - Use quality USB cable (charge cables, not data)
  - Use battery rated for at least 500mA continuous (1C for 500mAh+ battery)
  - Add 100-470µF capacitor near ESP32 power pins
  - Check for shorts in wiring
- Monitor serial output for brown-out messages

### Mounting and Installation Issues

**Problem:** GPS not getting fix when installed

**Solution:**
- Test GPS with device outside first (confirm GPS works)
- **Sky view critical** - GPS needs to "see" satellites
- Metal tank/fairing can block signal - test at intended location
- Carbon fiber is opaque to GPS signals
- Best locations on motorcycle:
  - Under seat cowl (transparent plastic above)
  - Top of tail section
  - Under gas tank cowl (only if plastic/fiberglass)
- Worst locations:
  - Under metal tank
  - Under carbon fiber bodywork
  - Inside metal case/box
- Use U-Center via TCP/IP to check signal strength at installation location

**Problem:** Device falls off / comes loose

**Solution:**
- Double-sided tape fails in heat and vibration
- Better options:
  - Velcro (industrial strength) - removable but secure
  - 3D printed mount with screws
  - Zip ties through fairing mounting holes
  - Adhesive-backed Velcro (3M brand)
- Clean mounting surface with isopropyl alcohol before applying adhesive
- Allow adhesive to cure 24 hours before riding
- Test security by pulling firmly before first ride

**Problem:** Battery life shorter than expected

**Solution:**
- **Calculate runtime:** Battery_mAh / Current_mA = Hours
- Example: 650mAh / 300mA average = 2.1 hours
- Current draw varies:
  - ESP32: 80-160mA (depends on WiFi/BT use)
  - GPS: 30-80mA (depends on module and fix status)
  - LEDs: 10-40mA
  - **Total typical: 250-350mA**
- **To extend runtime:**
  - Use larger battery (2000mAh+ for full day)
  - Disable WiFi when not needed
  - Use power saving GPS modes between sessions
  - Disable unused features (BLE or BT-SPP if not needed)
  - Turn off external LEDs
- Check for battery degradation (old batteries lose capacity)

### Switch and Button Issues

**Problem:** On/off switch not working

**Solution:**
- Verify switch is in series with power (typically between battery+ and EN pin)
- LOLIN D32 PRO: Switch connects EN to GND (pulled low = off)
- Check switch orientation - may be backwards
- Use multimeter continuity mode to verify switch operation
- Poor quality switches can have intermittent contact

**Problem:** WiFi mode button (BOOT) not responding

**Solution:**
- Short press (< 500ms) should toggle WiFi AP on/off
- Long press (> 2 seconds) should enable WiFi Client
- Check button is momentary (not latching)
- Verify button connects GPIO to GND (not GPIO to 3.3V)
- May need pull-up resistor if using long wires (10kΩ to 3.3V)
- Check `WIFI_MODE_BUTTON` definition matches your wiring
- Test button with multimeter in continuity mode

### LED Indicator Issues

**Problem:** Built-in LED not working or showing wrong pattern

**Solution:**
- Different ESP32 boards use different pins for LED
- Common LED pins: GPIO2 (DOIT), GPIO5 (LOLIN D32 PRO has RGB)
- Check your board schematic for LED pin
- **LED patterns:**
  - Slow blink (500ms): WiFi AP mode
  - Fast blink (250ms): WiFi Client mode
  - Solid/Off: WiFi disabled or wrong LED pin configured
- Some boards have inverted LED logic (LOW=on, HIGH=off)

**Problem:** External LED not working

**Solution:**
- Verify LED polarity (long leg = anode/positive, short leg = cathode/negative)
- **Typical wiring:** GPIO → Resistor → LED anode, LED cathode → GND
- Calculate resistor: R = (3.3V - LED_Vf) / LED_I
  - Red LED: (3.3-2.0)/0.020 = 65Ω (use 47-100Ω)
  - Blue/White LED: (3.3-3.0)/0.020 = 15Ω (use 22-47Ω)
- Test LED with multimeter in diode test mode
- Check GPIO pin definitions in `bonogps_board_settings.h`

### Enclosure and Environmental Issues

**Problem:** Device overheats in enclosure

**Solution:**
- ESP32 generates heat, especially with WiFi enabled
- Ensure ventilation in enclosure
- Avoid direct sunlight on enclosed device
- Consider heatsink on ESP32 module if in sealed enclosure
- LOLIN D32 PRO may get warm when charging - this is normal

**Problem:** Water/moisture damage

**Solution:**
- Most ESP32 boards are not waterproof
- Use conformal coating on PCB for moisture protection
- Silicone conformal coating spray (MG Chemicals 422B)
- Do not coat connectors or switches
- For rain riding: use waterproof enclosure with IP65+ rating
- Add desiccant pack inside sealed enclosures
- USB port is vulnerable - use dust cap when not in use

**Problem:** GPS performance degraded after installation

**Solution:**
- Antenna may be too close to metal
- Electrical noise from ignition/alternator can interfere
- Keep GPS away from:
  - Ignition coils (15+ cm minimum)
  - Alternator/stator
  - Power cables
  - Phone/RF transmitters
- Add ferrite bead on GPS power cable if noise suspected
- Test by powering from separate battery (isolate from vehicle electrical)

### Testing and Validation

**Problem:** How to test assembled device before installation?

**Checklist:**
1. ✅ Power on test (ESP32 boots, LED visible)
2. ✅ WiFi test (can connect to BonoGPS-XXXX AP)
3. ✅ Web interface test (can access http://10.0.0.1)
4. ✅ GPS test (place outside, wait for fix, check LED)
5. ✅ App connection test (connect phone app, verify data)
6. ✅ Button test (verify WiFi mode switching)
7. ✅ Battery test (fully charge, verify runtime)
8. ✅ Vibration test (shake device, check for loose connections)
9. ✅ Heat test (run for 30+ minutes, check for overheating)

**Problem:** Device works with USB but not with battery

**Solution:**
- USB provides regulated 5V, battery provides variable 3.3-4.2V
- Check if ESP32 has voltage regulator (most do)
- Verify battery is charged (> 3.6V under load)
- Check battery current capacity (need 500mA+)
- Test battery with multimeter under load
- Some ESP32 clones have poor quality regulators
- May need external LDO regulator for stable operation

### Getting Help with Assembly Issues

If you're stuck:
1. Take clear photos of your wiring
2. Measure voltages at key points with multimeter
3. Test components individually (GPS with U-Center, ESP32 with simple sketch)
4. Post in [GitHub Discussions](https://github.com/renatobo/bonogps/discussions) with:
   - Your ESP32 board model
   - GPS module model
   - Wiring diagram or photos
   - What works and what doesn't
   - Any error messages from serial monitor

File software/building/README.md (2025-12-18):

# Software development and build

- [Software development and build](#software-development-and-build)
  - [IDE options/suggestions: Arduino IDE or VS Code+Platformio](#ide-optionssuggestions-arduino-ide-or-vs-codeplatformio)
    - [Arduino IDE (recommended if you are new to the 'maker' approach)](#arduino-ide-recommended-if-you-are-new-to-the-maker-approach)
    - [PlatformIO](#platformio)
  - [Libraries](#libraries)
    - [External Libraries](#external-libraries)
    - [Built-in libraries](#built-in-libraries)
  - [Build options](#build-options)
    - [Large use of preprocessing macro](#large-use-of-preprocessing-macro)
    - [Logging facilities](#logging-facilities)
    - [How to enable OTA build](#how-to-enable-ota-build)
      - [OTA on Arduino IDE](#ota-on-arduino-ide)
      - [OTA on PlatformIO](#ota-on-platformio)
    - [Important: Partition size](#important-partition-size)
  - [Build Troubleshooting](#build-troubleshooting)

## IDE options/suggestions: Arduino IDE or VS Code+Platformio

Development is active on the [VS Code + Platformio](https://platformio.org/install/ide?install=vscode) combination: you can download the complete repository and work directly.

### Arduino IDE (recommended if you are new to the 'maker' approach)

**⏱️ Time:** 20-30 minutes | **🎯 Difficulty:** Beginner | **Prerequisites:** Arduino IDE 2.x, ESP32 board support

Code is written to be compatible with the Arduino IDE, there are a couple of steps required, starting from the assumption that you have already installed and set up the Arduino IDE for ESP32

- install the 'External libraries' listed in the section [deps] entry `lib_deps` of `platform.ini`. See below an example of how and when to select a specific version
- open the `bonogps.ino` file: it's empty as all in the code is somewhere else
- choose your board: "ESP32 Dev Module" (the generic board that everyone has, often tagged DOIT) or ["LOLIN D32 PRO" are supported](hardware/esp32/lolin_d32_pro.md), otherwise you might have to redefine your pins in `bonogps_board_settings.h`
- choose a partition schema with enough space (e.g. the Minimal SPIFFS with 1.9 MB of flash space)

The rest is common to any other build on the Arduino IDE.

If you are unsure of what board you are running, [check this introductory tutorial](https://randomnerdtutorials.com/getting-started-with-esp32/).

You can update software OTA, check a later paragraph here on how, as it's not enabled by default.

### PlatformIO

**⏱️ Time:** 30-45 minutes (first time setup) | **🎯 Difficulty:** Intermediate | **Prerequisites:** VS Code, Python, Git

Beside install PlatformIO (on VS Code as a recommendation), the build system uses a custom **python** script to determine the current software release version: `git_rev_macro.py` and it expects the project folder to be downloaded from github directly to build up the `GIT_REV` and `GIT_REPO` macro variables correctly.

If you are having issues, you can remove the line that invokes `git_rev_macro.py` and optionally set the 2 macros `GIT_REV` and `GIT_REPO` manually.

If you would like to define custom targets for your build, I recommend using a `platformio_custom.ini` file (there is a template in `platformio_custom.ini.template`).

## Libraries

### External Libraries

- [NimBLE-Arduino](https://github.com/h2zero/NimBLE-Arduino) from version 2.X
- [Uptime Library](https://github.com/YiannisBourkelis/Uptime-Library)
- [EasyButton](https://easybtn.earias.me/) specifically version 2.0.1: do not use any other version. This feature will be migrated to another library, as EasyButton is no longer developed and the latest version is not working
- [Task Scheduler](https://github.com/arkhipenko/TaskScheduler) 

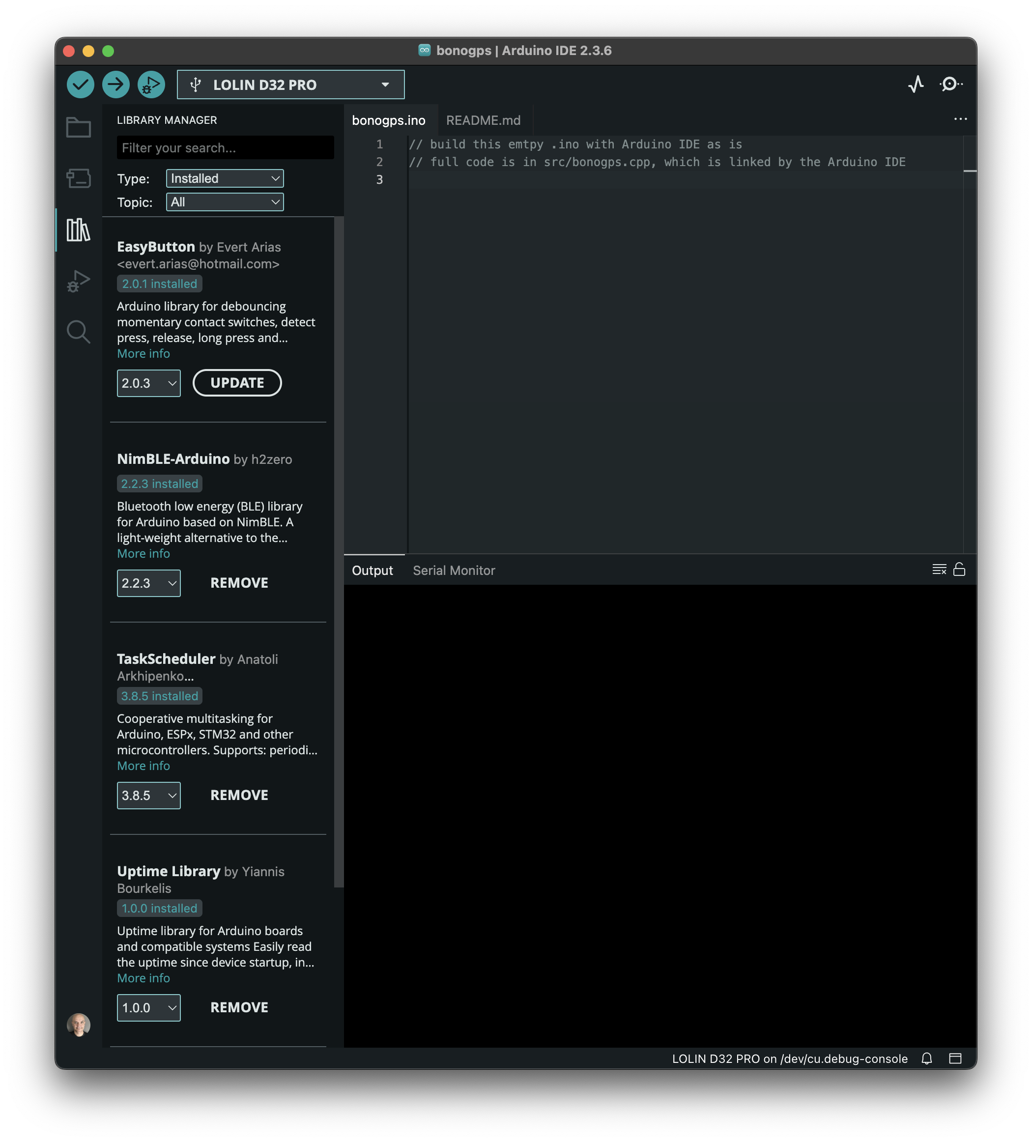
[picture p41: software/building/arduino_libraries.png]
arduino_libraries
On Arduino this would look like 

### Built-in libraries

Always included

- WebServer
- FS
- Preferences
- WiFi
- DNSServer
- ESPmDNS
- Update
- BluetoothSerial

Included via `#define` statements or compile macros

- ArduinoOTA: this really depends on how you prefer to update software on your device. It adds size to the flash, and it uses some memory, so if you don't plan on using it, don't include it.

## Build options

### Large use of preprocessing macro

To keep flash size small and to avoid several versions of the software, almost all features are enabled/disabled via macro preprocessing

For example, if you don't need BT-SPP or BLE, you can remove them. The most important ones are

- `BTSPPENABLED` Include BT-SPP capabilities (default: enabled)
- `BLEENABLED` Include BLE capabilities (default: enabled)
- `ENABLE_OTA` Include OTA capabilities (default: disabled)
- `SHOWBATTERY` Display battery status for boards that have built-in (like [LOLIN D32 PRO](../hardware/esp32/lolin_d32_pro.md)])

### Logging facilities

All logging on Serial Port is managed with `log_<i/d/e/w>()` functions (read more at [ESP32 Logging](https://thingpulse.com/esp32-logging/)). You can control how much logging is enabled within the Arduino IDE from the `Tools > Core Debug Level` menu.

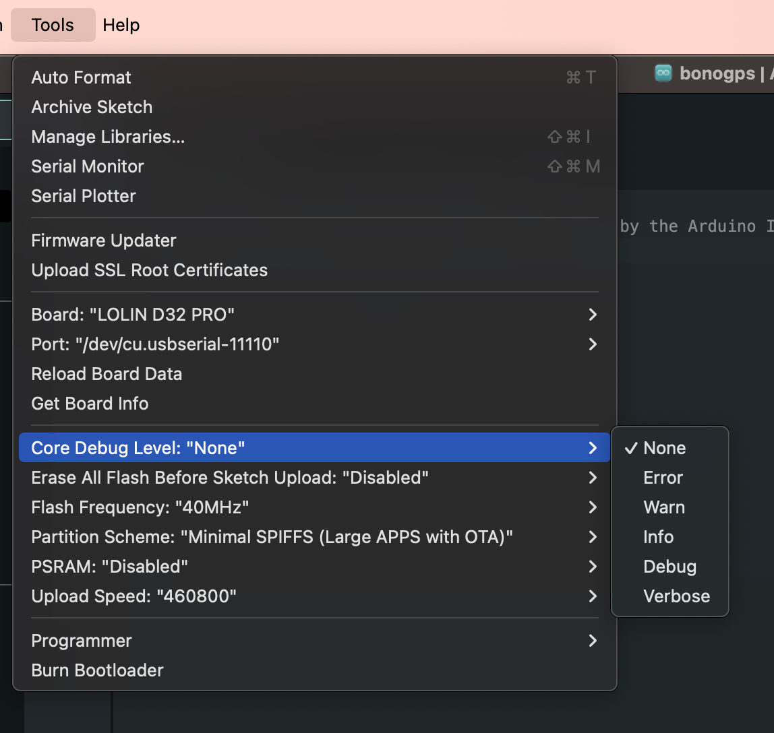
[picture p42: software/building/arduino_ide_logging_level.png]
arduino_ide_logging_level


### How to enable OTA build

OTA libraries are not enabled by default, to keep the binary size smaller and to have less software running at all times (it's a miracle there are no RAM issues with all tasks running).

Since updating via OTA is extremely convenient when you are testing, here is how to activate it via two preprocessing macro variables

- `ENABLE_OTA` if defined, libraries and code are built in, if undefined, no OTA is included
- `OTA_AVAILABILITY_SECS` defines for how long OTA is available after boot, either `-1` (forever) or a finite number of seconds. If undefined, it's `300`, to avoid any mistake on the field where you might mistakenly start flashing a firmware you are actually using

#### OTA on Arduino IDE

- uncomment `// #define ENABLE_OTA` at the beginning of `src/bonogps.cpp` (which you might have renamed to `bonogps.ino`)
- optionally, change for how long OTA is available defining `OTA_AVAILABILITY_SECS`

#### OTA on PlatformIO

- There are a couple of build targets ending in `_ota` that contain the command line define statements. If you need more build targets, I recommend using a local `platformio_custom.ini` that is not synced with the git repository
- you can also permanently enable it by changing the source code, as for the Arduino case (not recommended)

### Important: Partition size

You have to select a partitioning schema with 1.7 MB of programming space (e.g. Minimal SPIFFS with 1.9 MB), as the app with its libraries tends to be pretty large due to BT stacks.

Within PlatformIO, use the [platformio.ini](platformio.ini) available configuration

```ini
board_build.partitions = min_spiffs.csv
```

Within the Arduino IDE, from `Tools > Partition Scheme`

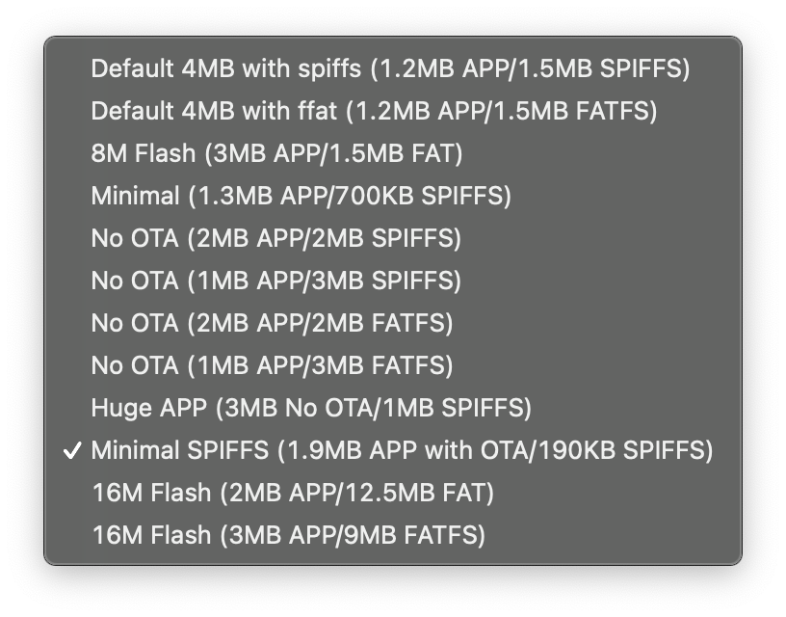
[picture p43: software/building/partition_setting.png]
Partition settings


**See also:**
- [Hardware Assembly Guide](../../hardware/assembled) - Physical connections and wiring
- [GPS Configuration](../../hardware/GPS) - **Must configure GPS before use**
- [Connecting Apps](../connecting) - Test your build with lap timer apps
- [Board Pin Definitions](../../include/README.md) - Customizing for different ESP32 boards

## Build Troubleshooting

### Common Build Issues

#### Library Compatibility Issues

**Problem:** `NimBLE-Arduino compilation errors` or `class NimBLEDevice has no member...`

**Solution:**
- Install NimBLE-Arduino **version 2.x** specifically (not 1.x or 3.x)
- In Arduino IDE: Library Manager → Search "NimBLE-Arduino" → Install version 2.x
- In PlatformIO: Specified in `platformio.ini` as `h2zero/NimBLE-Arduino@^2.0.0`

**Problem:** `EasyButton.h errors` or `undefined reference to EasyButton`

**Solution:**
- Install **EasyButton version 2.0.1** exactly (not 2.0.3 or higher)
- Newer versions have breaking API changes
- In Arduino IDE: Search for "EasyButton" by Evert Arias → Install 2.0.1
- In PlatformIO: `evert-arias/EasyButton@^2.0.1`

#### Compilation Errors

**Problem:** `Region 'iram0_0_seg' overflowed` or similar memory errors

**Solution:**
- Ensure partition scheme is set to "Minimal SPIFFS (1.9MB APP)"
- Reduce enabled features by commenting out `BTSPPENABLED` or `BLEENABLED` if you only need one
- Check `board_build.partitions = min_spiffs.csv` in PlatformIO

**Problem:** `GIT_REV or GIT_REPO undeclared`

**Solution:**
- Clone the repository using git (not download as ZIP)
- If using PlatformIO and still failing:
  1. Comment out the `git_rev_macro.py` line in `platformio.ini`
  2. Add manual defines: `-DGIT_REV=\"manual\"` and `-DGIT_REPO=\"local\"`

**Problem:** `Sketch too big` or `will not fit in partition`

**Solution:**
1. Verify partition scheme is "Minimal SPIFFS (1.9MB)"
2. Disable unused features:
   - Comment out `#define BTSPPENABLED` if not using BT-SPP
   - Comment out `#define BLEENABLED` if not using BLE
   - Comment out `#define ENABLE_OTA` if not using OTA updates
3. In Arduino IDE, ensure optimization is set to "Default" or "More" (not "Debug")

#### Upload and Connection Issues

**Problem:** `Failed to connect to ESP32` during upload

**Solution:**
- Hold the BOOT button while clicking Upload
- Check USB cable (use data cable, not charge-only)
- Install CH340 or CP2102 drivers if using clone ESP32 boards
- Try different USB ports
- Reduce upload speed in Arduino IDE (`Tools > Upload Speed` → try 115200)

**Problem:** `Serial port not found` or `Permission denied` on Linux

**Solution:**
```bash
# Add user to dialout group
sudo usermod -a -G dialout $USER
# Log out and log back in for changes to take effect
```

#### PlatformIO Specific Issues

**Problem:** `platformio.ini not found` or project structure errors

**Solution:**
- Open the root folder of the cloned repository in VS Code
- Ensure `.platformio` folder exists in your home directory
- Rebuild IntelliSense: `Ctrl+Shift+P` → "Rebuild IntelliSense Index"

**Problem:** Custom build targets not working

**Solution:**
- Create `platformio_custom.ini` from the template
- Add your custom configurations there
- This file is gitignored so your settings won't be overwritten

### Getting Verbose Build Output

**Arduino IDE:**
- `File > Preferences` → Check "Show verbose output during: compilation"

**PlatformIO:**
- Add `-v` flag to build: `pio run -v`

### Still Having Issues?

1. Check [GitHub Issues - Build Errors](https://github.com/renatobo/bonogps/issues?q=is%3Aissue+label%3Abuild)
2. Verify all library versions match those in `platformio.ini`
3. Try a clean build:
   - Arduino IDE: Delete sketch build folder
   - PlatformIO: `pio run --target clean` then rebuild
4. Open a new issue with:
   - Full error message
   - IDE and version (Arduino/PlatformIO)
   - ESP32 board model
   - Library versions installed

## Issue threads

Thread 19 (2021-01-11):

Support LOLIN D32 PRO

renatobo, 2021-01-11:
Add support for the [LOLIN D32 PRO](https://www.wemos.cc/en/latest/d32/d32_pro.html) board

Fixes already identified

- LED_BUILTIN needs to be GPIO_NUM_5
- Serial2 needs to be defined with actual PINS

renatobo, 2021-01-16:
Add monitoring of battery

Closed 2021-01-21.

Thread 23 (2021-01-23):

first BLE connection fails

renatobo, 2021-01-23:
Device name is not recognized correctly until a connection with another BLE client is performed (e.g. LightBlue)
E.g. device shows up as either Nimble or a shorter version of its name

renatobo, 2021-03-17:
This seems to be due to iOS caching of previous identifiers - while it is still a problem if you re-use a previously used ESP32, there is no solution at the moment

Closed 2021-03-17.

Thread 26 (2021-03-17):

Great job : can we add the 880 BN Compass ?

smichel19, 2021-03-17:
Great dev .. thanks Renato.
I did the build with a 880 BN GPS, I just cannot get the compass work properly.
Do you think there is a way to have it working ? can I wire the SCL and SDA to the ESP32 ad try to read the values and alter the code to send/feed Harry Latimer with it ?
Apart from that it's great thanks !

renatobo, 2021-03-17:
Glad to hear! iOS or Android?

HLT uses the magnetometer built into your phone so I let it do the dirty work to gain these benefits

- high frequency of data collection
- high precision potentially superior to the HMC5883L available on BN880
- no need to transmit its data (BLE is getting close to the limit in the case of iOS and text based NMEA) with a dedicated data structure because it does not merge with NMEA easily

Since HTL already has all of this and it does an excellent job, I never looked into using heading data from the BN880 - I don't even connect the wires.

There are ready to go libraries to connect to HMC5883L via i2c as

- https://www.arduino.cc/reference/en/libraries/grove-3-axis-digital-compass-hmc5883l/
- https://learn.adafruit.com/adafruit-hmc5883l-breakout-triple-axis-magnetometer-compass-sensor/wiring-and-test

The issue is that HLT is using your phone as the primary strategy so I don't even believe there is an option to do otherwise.

While not using the BN880 built-in magnetometer seems a waste of resources, I do not find benefits in having it done outside of the phone itself.
Harry also confirmed a similar opinion in other postings.

I'll be happy to hear other considerations on how to use it.

smichel19, 2021-03-17:
I use IOS. Thanks for the info sharing. I understand the choice not to use it then.
One again Thanks for the dev... it is really nice ! 👍

Closed 2021-03-19.

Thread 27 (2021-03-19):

Do i need for racechono, harrys Laptimer etc. Taskscheduler?

R1Snake, 2021-03-19:
Hi,

i am using an esp32 with NEO 8M and without a battery.

The ESP is powered via ignition power of my bike so I don't need deepsleep, battery information etc.

Do I need the Taskscheduler for Racechrono or another racing app? If not I would disable this functionality.

renatobo, 2021-03-19:
Hi R1Snake!

Please note that a M8N might be limited to 5Hz updates unless you enable only 1 satellite constellation (which is essentially GPS only) then you can get to 10Hz (see the [hardware/GPS](https://github.com/renatobo/bonogps/tree/main/hardware/GPS#q-m8n-m8q-m8u--which-one) section)

**A note on battery support**
Battery support is optional and activated (and compiled in the code) only when the macro `SHOWBATTERY` is defined (right now I only tested on the Lolin D32 Pro).
Not requiring a battery makes for a much easier hardware configuration indeed: be aware of one limitation which is tied to the cold start of the GPS unit at the beginning of your day when it requires some time (even minutes) to find satellites.

**TaskScheduler**

TaskScheduler is optional and it supports

1. status LED blinking: off, slow blink, fast blink to show WiFi status
2. periodic polling GSA and GSV information. These are not actually required for GPS positioning
3. power saving
4. battery status notifications
2. disabling OTA updates after some configured time

Number 2 above is the only one that changes data sent to your app of choice, the other are helper functions that don't impact base GPS functionality.

You can undefine the macro `TASK_SCHEDULER` to remove it.

A couple of questions

1. Is your goal simpler code, smaller binary, or else?
2. what apps are you using and which connection method (BLE,BTSPP,WiFi) ?

Closed 2021-03-19.

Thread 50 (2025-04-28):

Error while compiling NimBLE on Arduino IDE

arbot532, 2025-04-28:
Code was unable to compile with NimBLE 1.4.3

Switched to v2.2.3 and all was fine.

I think is an old info in the "compiling" section.

renatobo, 2025-04-28:
As of [v2.0 of bonogps](https://github.com/renatobo/bonogps/releases/tag/v2.0) the NimBLE library required is from the 2.X branch - [platformio.ini](https://github.com/renatobo/bonogps/blob/main/platformio.ini) reflects that.

The compiling page was outdated, I have fixed it - thank you!

Closed 2025-04-28.

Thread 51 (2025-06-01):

Error during build

MarekMarcinski, 2025-06-01:
During build proccess I'm getting below error:

Archiving .pio\build\esp32dev\libFrameworkArduino.a
Linking .pio\build\esp32dev\firmware.elf
c:/users/user/.platformio/packages/toolchain-xtensa-esp32/bin/../lib/gcc/xtensa-esp32-elf/8.4.0/../../../../xtensa-esp32-elf/bin/ld.exe: .pio\build\lolind32pro\lib34f\libNimBLE-Arduino.a(cfg_srv.c.o):C:\Users\user\Downloads\bonogps/.pio/libdeps/lolind32pro/NimBLE-Arduino/src/nimble/nimble/host/mesh/src/cfg_srv.c:2543: multiple definition of `bt_mesh_cfg_srv_op'; C:\Users\user\.platformio\packages\framework-arduinoespressif32\tools\sdk\esp32\lib\libbt.a(cfg_srv.c.obj):/home/runner/work/esp32-arduino-lib-builder/esp32-arduino-lib-builder/esp-idf/components/bt/esp_ble_mesh/mesh_core/cfg_srv.c:3280: first defined here
c:/users/user/.platformio/packages/toolchain-xtensa-esp32/bin/../lib/gcc/xtensa-esp32-elf/8.4.0/../../../../xtensa-esp32-elf/bin/ld.exe: .pio\build\lolind32pro\lib34f\libNimBLE-Arduino.a(heartbeat.c.o): in function `bt_mesh_hb_pub_get':
C:\Users\user\Downloads\bonogps/.pio/libdeps/lolind32pro/NimBLE-Arduino/src/nimble/nimble/host/mesh/src/heartbeat.c:268: multiple definition of `bt_mesh_hb_pub_get'; C:\Users\user\.platformio\packages\framework-arduinoespressif32\tools\sdk\esp32\lib\libbt.a(cfg_srv.c.obj):/home/runner/work/esp32-arduino-lib-builder/esp32-arduino-lib-builder/esp-idf/components/bt/esp_ble_mesh/mesh_core/cfg_srv.c:3639: first defined here
collect2.exe: error: ld returned 1 exit status
*** [.pio\build\lolind32pro\firmware.elf] Error 1

MarekMarcinski, 2025-06-13:
with this change it works. thanks.

Closed 2025-06-13.

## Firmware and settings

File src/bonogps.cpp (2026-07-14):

/******************************************************************************

  BonoGPS: connect a GPS to mobile Apps to track lap times
  More info at https://github.com/renatobo/bonogps
  Renato Bonomini https://github.com/renatobo

******************************************************************************/

// For PlatformIO we need to include the Arduino framework
#include <Arduino.h>

// load PINout definitions from this header file
#if __has_include("bonogps_board_settings.h")
#include "bonogps_board_settings.h"
#elif __has_include("include/bonogps_board_settings.h")
#include "include/bonogps_board_settings.h"
#else
#error "cannot find 'bonogps_board_settings.h'"
#endif

/*
 Enable or disable features
 */

#define BTSPPENABLED // add BT-SPP stack, remove if unnecessary as it uses quite a bit of flash space
#define BLEENABLED   // add BLE stack, remove if unnecessary as it uses quite a bit of flash space
// #define ENABLE_OTA     // add OTA Enable here if you are using Arduino IDE, otherwise use -DENABLE_OTA in platformio
#define HIGHER_GPS_RATES // enable 20Hz and 25Hz GPS rates, not all GPS support these rates

/*
 You should not disable these unless there is a problem with the specific feature
*/ 
#define UPTIME         // add library to display for how long the device has been running
#define MDNS_ENABLE    // Enable or disable mDNS - currently not working in all conditions. Small memory save to be worth removing
#define TASK_SCHEDULER // enable adv task scheduler. Small memory save to be worth removing
#define BUTTON         // Enable changing WIFI_STA and WIFI_AP via Boot button. Small memory save to be worth removing - Which button is defined below
#define SHORT_API      // URLs for commands such as enable/disable/change rate respond with a short json answer instead of a full web page

/*
  Configure names and PIN's used for interfacing with external world
*/ 
#define DEVICE_MANUFACTURER "https://github.com/renatobo"
#define DEVICE_NAME "Bono GPS"
#define BONOGPS_BUILD_DATE __TIMESTAMP__
// BONOGPS_FIRMWARE_VER is used in BLE "Firmware" data and in the /status page of web configuration
#ifdef GIT_REV
// if code is under Git revision and compiled from platformio using the additional git_rev_macro.py script, GIT_REV is set
#define BONOGPS_FIRMWARE_VER GIT_REV
#else
// the following define is needed to display version when building this with the Arduino IDE
#define BONOGPS_FIRMWARE_VER "v1.4"
#endif
// GIT_REPO is used to build links to online software release notes and documentation
#ifndef GIT_REPO
#define GIT_REPO "renatobo/bonogps"
#endif

/* 
 WiFi and TCIP-IP settings
 */
#define BONOGPS_MDNS "bonogps"   // Bonjour DNS name, access the GPS configuration page by appending .local as DNS
#define BONOGPS_AP "BonoGPS"     // Prefix for the AP name, followed by 4 digits device id
#define BONOGPS_PWD "bono5678"   // the AP password to avoid random people connecting to the device
#define MAX_AP_NAME_SIZE 20      // the AP name is generated on the fly, this is its maximum size
#define NMEA_TCP_PORT 1818       // TCP Port for NMEA sentences repeater, used for Harry's LapTimer mostly, but also for proxying with uBlox

/* 
 GPS UART settings
 */
#define gpsPort Serial2               // The serial port where the GPS is connected
#define GPS_STANDARD_BAUD_RATE 115200 // The default baud rate for the GPS. You might want to make sure this is set via u-center ahead of time
#define UART_BUFFER_SIZE_RX 256       // How large should the RX buffer for the GPS port - more than 512 creates issues
#define MAX_UART_BUFFER_SIZE 256      // Size of the intermediate buffer where we are storing the current sentence
#define GPS_UART_TIMEOUT 10000UL      // How much time before autobauding times out
#define MIN_NMEA_MESSAGE_SIZE 6       // Minimum size of a NMEA message

/* 
 Define configuration of Bluetooth Low Energy
 */
#define BLE_DEVICE_ID "BonoGPS"                  // The name of the BLE device
#define BLE_SERVICE_UUID (uint16_t)0x1819        // SERVICE_LOCATION_AND_NAVIGATION_UUID
#define BLE_CHARACTERISTIC_UUID (uint16_t)0x2A67 // CHARACTERISTIC_LOCATION_AND_SPEED_CHARACTERISTIC_UUID
#define BLE_MTU 185                              // Maximum Transmission Unit for BLE. 185 is a safe tested value

/* 
 Monitor UART settings
 */
#define SerialMonitor Serial
#define LOG_BAUD_RATE 115200

/********************************
 * 
 * nothing you should need to configure from here below
 * 
********************************/

#if !(defined(ESP32))
#error This code is designed to run only on the ESP32 board
#endif

#if !(defined(LED_BUILTIN))
#error "You are missing the definition of LED_BUILTIN for your board or in bonogps_board_settings.h"
#else
#ifndef LED_WIFI
#define LED_WIFI LED_BUILTIN
#endif // #ifndef LED_WIFI
#endif // #if !(defined(LED_BUILTIN))
#if !(defined(WIFI_MODE_BUTTON))
#error "You are missing the definition of WIFI_MODE_BUTTON in bonogps_board_settings.h"
#endif
#if !(defined(RX2) && defined(TX2))
#error "You are missing definitions of Serial 2 PINS: select a board that has them already defined or change bonogps_board_settings.h"
#endif

// Library to store desidered preferences in NVM
#include <Preferences.h>
Preferences prefs;

// data to be stored
#include "esp_bt.h"
#include "esp_wifi.h"
#include <WiFi.h>

#define WIFI_KEY_MAXLEN (int)64
#define WIFI_SSID_MAXLEN (int)32

typedef struct
{
  unsigned long gps_baud_rate = GPS_STANDARD_BAUD_RATE; // initial or current baud rate
  uint8_t gps_rate = 5;                                 // Rate in Hz
  WiFiMode_t wifi_mode = WIFI_AP;                       // WiFi mode: WIFI_AP, WIFI_STA, WIFI_OFF
  bool nmeaGSA = false;   // Enable GSA sentence
  bool nmeaGSV = false;   // Enable GSV sentence
  bool nmeaVTG = false;   // Enable VTG sentence
  bool nmeaGLL = false;   // Enable GLL sentence
  bool nmeaGBS = true;    // Enable GBS sentence
  bool nmeaTcpServer = false;   // Enable TCP server for NMEA sentences
  bool ble_active = true;       // Enable BLE Server
  bool btspp_active = false;    // Enable BT-SPP Server
  bool trackaddict = false;     // Enable predefined TrackAddict mode
  bool racechrono = false;      // Enable predefined RaceChrono mode
  bool racetime = false;        // Enable predefined RaceTime mode
  uint8_t nmeaGSAGSVpolling = 0;  // Poll GSA and GSV info every n seconds
  char wifi_ssid[WIFI_SSID_MAXLEN];   // SSID of the WiFi network in WIFI_AP mode
  char wifi_key[WIFI_KEY_MAXLEN];     // Key of the WiFi network in WIFI_AP mode
} stored_preference_t;

stored_preference_t stored_preferences;

/*
  esp32 and GPS runtime variables
*/

uint16_t chip; // hold the device id to be used in broadcasting unit identifier strings
char ap_ssid[MAX_AP_NAME_SIZE];         // hold the AP name to be used in WIFI_AP
const char ap_password[] = BONOGPS_PWD; // hold the AP password to be used in WIFI_AP
int max_buffer = 0;                     // hold the maximum buffer size for the GPS copy buffer

/*
  For status page and to enable powersaving mode
*/
#ifdef UPTIME
#include "uptime_formatter.h"
#endif
bool gps_powersave = false;

#ifdef MDNS_ENABLE
#include <ESPmDNS.h>
#endif

// OTA
#ifdef ENABLE_OTA
#include <WiFiUdp.h>
#include <ArduinoOTA.h>
#endif

//for LED status and OTA updates
#ifdef TASK_SCHEDULER
#include <TaskScheduler.h>
// Scheduler for periodic tasks
Scheduler ts;
#endif

// if we have both, we can define a task to check periodic OTA requests
#if defined(ENABLE_OTA) && defined(TASK_SCHEDULER)
// we will define its charateristics later
Task tOTA;
#endif

/*
  BLueTooth classic stack (Android)
*/
#ifdef BTSPPENABLED
#include "BluetoothSerial.h"
BluetoothSerial SerialBT;
bool bt_deviceConnected = false;
bool bt_spp_stop();
void bt_spp_start();
void bt_callback(esp_spp_cb_event_t event, esp_spp_cb_param_t *param);
#endif

/*
  BLE stack (iOS)
*/
#ifdef BLEENABLED
#define CONFIG_BT_NIMBLE_ROLE_CENTRAL_DISABLED // No BLE client
#define CONFIG_BT_NIMBLE_ROLE_OBSERVER_DISABLED // No BLE Scan
#define CONFIG_BT_NIMBLE_MAX_CONNECTIONS 2
#define CONFIG_BT_NIMBLE_MAX_BONDS 2
#define CONFIG_BT_NIMBLE_SVC_GAP_DEVICE_NAME BONOGPS_MDNS
#define CONFIG_NIMBLE_STACK_USE_MEM_POOLS 1 // Enable the use of memory pools for stack operations. This will use slightly more RAM but may provide more stability.
#include <NimBLEDevice.h>
// ble runtime
bool ble_deviceConnected = false;
void ble_start();
void ble_stop();
String ble_client_address;
#endif

#if defined(BLEENABLED) || defined(BTSPPENABLED)
char ble_device_id[MAX_AP_NAME_SIZE];
#endif

/*
  Use Button
*/
#ifdef BUTTON
// remove unneeded feature to trim down library size
#define EASYBUTTON_DO_NOT_USE_SEQUENCES
#define WIFI_ENABLE_STA_DURATION 2000
#include <EasyButton.h>
// Instance of the button to switch wifi mode
EasyButton button(WIFI_MODE_BUTTON);
#endif

#if defined(SHOWBATTERY)
// Right now this is tailored to the TP4054 charging available on GPIO35 for LOLIN D32 Pro
// check https://www.youtube.com/watch?t=88&v=yZjpYmWVLh8&feature=youtu.be for how
// This could be extended to other solutions as needed

float ReadBatteryVoltage()
{
  return analogRead(GPIO_BATTERY) / 4096.0 * 7.445;
}

uint8_t LiPoChargePercentage(float voltage)
{
  // use as LiPoChargePercentage(ReadBatteryVoltage())
  // LOLIN D32 PRO uses a TP4054 so max V should be 4.2V https://datasheetspdf.com/pdf/1090540/NanJingTopPower/TP4054/1
  // 0% <= 3.3
  // 100% > 4.2
  uint8_t returnvalue;
  float normalizedcharge = ( voltage - 3.3 ) / (4.2 - 3.3) * 100;
  if (normalizedcharge > 100) 
  {
    returnvalue = 100;
  } else if (normalizedcharge <0)
  {
    returnvalue = 0;
  } else
  {
    returnvalue = (uint8_t) normalizedcharge;
  }
  return returnvalue;
}
#endif //#if defined(SHOWBATTERY)

/********************************
 * 
 * Declarations of prototypes required by VS Code or PlatformIO
 * 
********************************/

void WebConfig_start();
void WebConfig_stop();
void gps_initialize_settings();
void restart_after_sleep();
void wifi_AP();
void wifi_OFF();
#ifdef ENABLE_OTA
void handle_OTA();
void OTA_start();
void OTA_stop();
#endif

/********************************

   Utilities

 * ******************************/
#ifdef BUILD_ENV_NAME
#define BONO_GPS_VERSION BONOGPS_FIRMWARE_VER " [" BUILD_ENV_NAME "]"
#else
#define BONO_GPS_VERSION BONOGPS_FIRMWARE_VER " [Arduino]"
#endif

void poweroff() {
#ifdef BTSPPENABLED
  bt_spp_stop();
#endif
#ifdef BLEENABLED
  ble_stop();
#endif
  wifi_OFF();

  // https://docs.espressif.com/projects/esp-idf/en/latest/esp32/api-reference/system/sleep_modes.html
  // rtc_gpio_isolate(GPIO_NUM_12);
  esp_sleep_pd_config(ESP_PD_DOMAIN_MAX, ESP_PD_OPTION_OFF);
  esp_sleep_pd_config(ESP_PD_DOMAIN_RTC_PERIPH, ESP_PD_OPTION_OFF);
  esp_sleep_pd_config(ESP_PD_DOMAIN_RTC_SLOW_MEM, ESP_PD_OPTION_OFF);
  esp_sleep_pd_config(ESP_PD_DOMAIN_RTC_FAST_MEM, ESP_PD_OPTION_OFF);
  esp_deep_sleep_start();
}
/********************************

   GPS Settings
   These sentences are used to configure a uBlox series 8 device

 * ******************************/
// set rate of GPS to 5hz
const char UBLOX_INIT_5HZ[] PROGMEM = {0xB5, 0x62, 0x06, 0x08, 0x06, 0x00, 0xC8, 0x00, 0x01, 0x00, 0x01, 0x00, 0xDE, 0x6A};
// set rate of GPS to 10Hz
const char UBLOX_INIT_10HZ[] PROGMEM = {0xB5, 0x62, 0x06, 0x08, 0x06, 0x00, 0x64, 0x00, 0x01, 0x00, 0x01, 0x00, 0x7A, 0x12};
// set rate of GPS to 1Hz
const char UBLOX_INIT_1HZ[] PROGMEM = {0xB5, 0x62, 0x06, 0x08, 0x06, 0x00, 0xE8, 0x03, 0x01, 0x00, 0x01, 0x00, 0x01, 0x39};
#ifdef HIGHER_GPS_RATES
// set rate of GPS to 20Hz
const char UBLOX_INIT_20HZ[] PROGMEM = {0xB5, 0x62, 0x06, 0x08, 0x06, 0x00, 0x32, 0x00, 0x01, 0x00, 0x01, 0x00, 0x48, 0xE6};
// set rate of GPS to 25Hz
const char UBLOX_INIT_25HZ[] PROGMEM = {0xB5, 0x62, 0x06, 0x08, 0x06, 0x00, 0x28, 0x00, 0x01, 0x00, 0x01, 0x00, 0x3E, 0xAA};
#endif

// GLL_ON
const char UBLOX_GxGLL_ON[] PROGMEM = {0xB5, 0x62, 0x06, 0x01, 0x08, 0x00, 0xF0, 0x01, 0x00, 0x01, 0x00, 0x00, 0x00, 0x00, 0x01, 0x2F};
// GLL OFF
const char UBLOX_GxGLL_OFF[] PROGMEM = {0xB5, 0x62, 0x06, 0x01, 0x08, 0x00, 0xF0, 0x01, 0x00, 0x00, 0x00, 0x00, 0x00, 0x00, 0x00, 0x2A};

// VTG ON
const char UBLOX_GxVTG_ON[] PROGMEM = {0xB5, 0x62, 0x06, 0x01, 0x08, 0x00, 0xF0, 0x05, 0x00, 0x01, 0x00, 0x00, 0x00, 0x00, 0x05, 0x4B};
// VTG OFF
const char UBLOX_GxVTG_OFF[] PROGMEM = {0xB5, 0x62, 0x06, 0x01, 0x08, 0x00, 0xF0, 0x05, 0x00, 0x00, 0x00, 0x00, 0x00, 0x00, 0x04, 0x46};

// Enable GxGSA (GNSS DOP and Active Satellites)
const char UBLOX_GxGSA_ON[] PROGMEM = {0xB5, 0x62, 0x06, 0x01, 0x08, 0x00, 0xF0, 0x02, 0x01, 0x01, 0x00, 0x01, 0x01, 0x00, 0x05, 0x41};
// Disable GxGSA
const char UBLOX_GxGSA_OFF[] PROGMEM = {0xB5, 0x62, 0x06, 0x01, 0x08, 0x00, 0xF0, 0x02, 0x00, 0x00, 0x00, 0x00, 0x00, 0x00, 0x01, 0x31};

// Enable GxGSV (Sat View)
const char UBLOX_GxGSV_ON[] PROGMEM = {0xB5, 0x62, 0x06, 0x01, 0x08, 0x00, 0xF0, 0x03, 0x01, 0x01, 0x00, 0x01, 0x01, 0x00, 0x06, 0x48};
// Disable GxGSV
const char UBLOX_GxGSV_OFF[] PROGMEM = {0xB5, 0x62, 0x06, 0x01, 0x08, 0x00, 0xF0, 0x03, 0x00, 0x00, 0x00, 0x00, 0x00, 0x00, 0x02, 0x38};

// set Max SVs per Talker id to 8
const char UBLOX_INIT_CHANNEL_8[] PROGMEM = {0xB5, 0x62, 0x06, 0x17, 0x14, 0x00, 0x00, 0x41, 0x08, 0x02, 0x00, 0x00, 0x00, 0x00, 0x00, 0x00, 0x00, 0x01, 0x00, 0x00, 0x00, 0x00, 0x00, 0x00, 0x00, 0x00, 0x7D, 0xE7};
// standard max SVs and extended digits for unsupported SVs
const char UBLOX_INIT_CHANNEL_ALL[] PROGMEM = {0xB5, 0x62, 0x06, 0x17, 0x14, 0x00, 0x00, 0x41, 0x00, 0x02, 0x00, 0x00, 0x00, 0x00, 0x01, 0x00, 0x00, 0x01, 0x00, 0x00, 0x00, 0x00, 0x00, 0x00, 0x00, 0x00, 0x76, 0x63};

// use GP as Main talker and GSV Talker ID - this is needed for TrackAddict
const char UBLOX_INIT_MAINTALKER_GP[] PROGMEM = {0xB5, 0x62, 0x06, 0x17, 0x14, 0x00, 0x00, 0x41, 0x00, 0x02, 0x00, 0x00, 0x00, 0x00, 0x01, 0x01, 0x01, 0x01, 0x00, 0x00, 0x00, 0x00, 0x00, 0x00, 0x00, 0x00, 0x78, 0x78};
// use GP as Main talker and GSV Talker ID and restrict to GPS SVs ony - this is needed for RaceChrono
const char UBLOX_INIT_MAINTALKER_GP_GPSONLY[] PROGMEM = {0xB5, 0x62, 0x06, 0x17, 0x14, 0x00, 0x10, 0x41, 0x00, 0x02, 0x00, 0x00, 0x00, 0x00, 0x01, 0x01, 0x01, 0x01, 0x00, 0x00, 0x00, 0x00, 0x00, 0x00, 0x00, 0x00, 0x88, 0xB8};

// set gps port BAUD rate
const char UBLOX_BAUD_57600[] PROGMEM = {0xB5, 0x62, 0x06, 0x00, 0x14, 0x00, 0x01, 0x00, 0x00, 0x00, 0xD0, 0x08, 0x00, 0x00, 0x00, 0xE1, 0x00, 0x00, 0x03, 0x00, 0x03, 0x00, 0x00, 0x00, 0x00, 0x00, 0xDA, 0xA9};
const char UBLOX_BAUD_38400[] PROGMEM = {0xB5, 0x62, 0x06, 0x00, 0x14, 0x00, 0x01, 0x00, 0x00, 0x00, 0xD0, 0x08, 0x00, 0x00, 0x00, 0x96, 0x00, 0x00, 0x03, 0x00, 0x03, 0x00, 0x00, 0x00, 0x00, 0x00, 0x8F, 0x70};
const char UBLOX_BAUD_115200[] PROGMEM = {0xB5, 0x62, 0x06, 0x00, 0x14, 0x00, 0x01, 0x00, 0x00, 0x00, 0xD0, 0x08, 0x00, 0x00, 0x00, 0xC2, 0x01, 0x00, 0x03, 0x00, 0x03, 0x00, 0x00, 0x00, 0x00, 0x00, 0xBC, 0x5E};

// power saving : enable power saving mode for 1800 or 3600 seconds
// UBX-RXM-PMREQ request
const char UBLOX_PWR_SAVE_30MIN[] PROGMEM = {0xB5, 0x62, 0x02, 0x41, 0x10, 0x00, 0x00, 0x00, 0x00, 0x00, 0x40, 0x77, 0x1B, 0x00, 0x02, 0x00, 0x00, 0x00, 0xE8, 0x00, 0x00, 0x00, 0x0F, 0xF6};
const char UBLOX_PWR_SAVE_1HR[] PROGMEM = {0xB5, 0x62, 0x02, 0x41, 0x10, 0x00, 0x00, 0x00, 0x00, 0x00, 0x80, 0xEE, 0x36, 0x00, 0x02, 0x00, 0x00, 0x00, 0xE8, 0x00, 0x00, 0x00, 0xE1, 0x21};
const char UBLOX_PWR_OFF[] PROGMEM = { 0xB5, 0x62, 0x02, 0x41, 0x10, 0x00, 0x00, 0x00, 0x00, 0x00, 0x00, 0x00, 0x00, 0x00, 0x02, 0x00, 0x00, 0x00, 0x08, 0x00, 0x00, 0x00, 0x5D, 0x4B};

// restart UBX-CFG-RST with controlled GNSS only software, hotstart (<4 hrs) so that ephemeris still valid
const char UBLOX_WARMSTART[] PROGMEM = {0xB5, 0x62, 0x06, 0x04, 0x04, 0x00, 0x00, 0x00, 0x02, 0x00, 0x10, 0x68};

// Enable GxGBS to display precision in some apps
const char UBLOX_GxGBS_ON[] PROGMEM = {0xB5, 0x62, 0x06, 0x01, 0x08, 0x00, 0xF0, 0x09, 0x01, 0x01, 0x00, 0x01, 0x01, 0x00, 0x0C, 0x72};
// Disable GxGBS to display precision in some apps
const char UBLOX_GxGBS_OFF[] PROGMEM = {0xB5, 0x62, 0x06, 0x01, 0x08, 0x00, 0xF0, 0x09, 0x00, 0x00, 0x00, 0x00, 0x00, 0x00, 0x08, 0x62};

// Poll GNGSA (GN: Combined GNSS position. GNSS position fix from more than one constellation, for example, GPS and GLONASS)
const char UBLOX_GNGSA_POLL[] PROGMEM = "$EIGNQ,GSA*2D\r\n";
// Poll GNGSV (GN: Combined GNSS position. GNSS position fix from more than one constellation, for example, GPS and GLONASS)
const char UBLOX_GNGSV_POLL[] PROGMEM = "$EIGNQ,GSV*3A\r\n";
// Poll GPGSA (GP: GPS) RaceChrono only understand GPGSA
const char UBLOX_GPGSA_POLL[] PROGMEM = "$EIGPQ,GSA*33\r\n";
// Poll GPGSV (GP: GPS) RaceChrono only understand GPGSV
const char UBLOX_GPGSV_POLL[] PROGMEM = "$EIGPQ,GSV*24\r\n";
bool gsaorgsv_turn = true;

/* 
  Send a binary message to the GPS, optionally turning it on if it is in power saving mode
*/
void push_gps_message(const char message[], int message_size = 0)
{
  if (gps_powersave)
  {
    log_d("Disable powermode");
    gpsPort.end();
    delay(250);
    // assumes stored_preferences global
    gps_powersave = false;
    gps_initialize_settings();
  }
  for (int i = 0; i < message_size; i++)
  {
    gpsPort.write(message[i]);
  }
}

#ifdef TASK_SCHEDULER
/* 
  Periodically poll GSA and GSV info (details on satellites) with a scheduled task, instead of streaming with the usual frequency
*/
void poll_GSA_GSV_info()
{
  if (gsaorgsv_turn)
  {
    if (stored_preferences.racechrono)
    {
      // RaceChrono only understand GPGSA
      gpsPort.write(UBLOX_GPGSA_POLL);
    }
    else
    {
      gpsPort.write(UBLOX_GNGSA_POLL);
    }
  }
  else
  {
    if (stored_preferences.racechrono)
    {
      // RaceChrono only understand GPGSV
      gpsPort.write(UBLOX_GPGSV_POLL);
    }
    else
    {
      gpsPort.write(UBLOX_GNGSV_POLL);
    }
  }
  gsaorgsv_turn = !gsaorgsv_turn;
}

Task tpoll_GSA_GSV_info(0, TASK_FOREVER, poll_GSA_GSV_info, &ts, false);
void control_poll_GSA_GSV(int frequency)
{
  stored_preferences.nmeaGSAGSVpolling = frequency;
  if (frequency > 0)
  {
    push_gps_message(UBLOX_GxGSV_OFF, sizeof(UBLOX_GxGSV_OFF));
    push_gps_message(UBLOX_GxGSA_OFF, sizeof(UBLOX_GxGSA_OFF));
    tpoll_GSA_GSV_info.setInterval(frequency * 500);
    tpoll_GSA_GSV_info.enable();
  }
  else
  {
    tpoll_GSA_GSV_info.disable();
  }
}

/* 
  handle restart when config is lost
*/
Task trestart_after_sleep(0, 1, restart_after_sleep, &ts, false);
void restart_after_sleep()
{
  gpsPort.end();
  delay(250);
  // assumes 'stored_preferences' is global
  gps_initialize_settings();
  trestart_after_sleep.disable();
}
#endif
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
void loop()
{
  // check UART for data
  if (gpsPort.available())
  {
    size_t len = gpsPort.available();
    uint8_t sbuf[len];
    gpsPort.readBytes(sbuf, len);
    // log max buffer size
    if (len > max_buffer)
    {
      max_buffer = len;
      log_w("New max buffer: %d", max_buffer);
    }
    if (wifi_connected && NMEARemoteClient && NMEARemoteClient.connected())
    {
      //push UART data to the TCP client
      NMEARemoteClient.write(sbuf, len);
    }

#ifdef BTSPPENABLED
    if (bt_deviceConnected && stored_preferences.btspp_active)
    {
      // we have BT-SPP active
      SerialBT.write(sbuf, len);
    }
#endif

#ifdef BLEENABLED
    if (ble_deviceConnected && stored_preferences.ble_active)
    {
      // we have BLE active
      for (int i = 0; i < len; i++)
      {
        if (gps_message_pointer > MAX_UART_BUFFER_SIZE - 3)
        {
          log_e("BLE Buffer saturated, resetting ");
          gps_currentmessage[0] = (uint8_t)'$';
          gps_currentmessage[1] = (uint8_t)'\0';
          gps_message_pointer = 1;
        }
        if (sbuf[i] == 36) // $ char
        {
          gps_currentmessage[gps_message_pointer++] = (uint8_t)'\r';
          gps_currentmessage[gps_message_pointer++] = (uint8_t)'\n';
          gps_currentmessage[gps_message_pointer++] = (uint8_t)'\0';
          // There is a new message -> Notify BLE of the changed value if connected and size says it is likely to be valid
          if (gps_message_pointer > MIN_NMEA_MESSAGE_SIZE)
          {
            pCharacteristicGPS->setValue(gps_currentmessage, gps_message_pointer);
            pCharacteristicGPS->notify();
            delay(1);
          }
          gps_currentmessage[0] = (uint8_t)'$';
          gps_currentmessage[1] = (uint8_t)'\0';
          gps_message_pointer = 1;
        }
        else
        {
          // Accumulate more of the GPS message
          gps_currentmessage[gps_message_pointer++] = sbuf[i];
        }
      }
    }
#endif
  }

  if (wifi_connected)
  {
    // handle sending instructions to GPS via uBlox center connected with TCP/IP
    if (NMEARemoteClient.connected() && NMEARemoteClient.available())
    {
      gpsPort.write(NMEARemoteClient.read());
    }
    else
    {
      NMEACheckForConnections();
    }

    webserver.handleClient();
  }

#ifdef BUTTON
  // Continuously read the status of the button.
  button.read();
#endif

#ifdef TASK_SCHEDULER
  // run all periodic tasks
  ts.execute();
#else
  // if the scheduler is not available, we need to check for OTA (if builtin)
  #ifdef ENABLE_OTA
  ArduinoOTA.handle();
  #endif // #ifdef ENABLE_OTA
#endif // #ifdef TASK_SCHEDULER

}

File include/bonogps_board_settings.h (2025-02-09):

/******************************************************************************

  BonoGPS: connect a GPS to mobile Apps to track lap times
  More info at https://github.com/renatobo/bonogps
  Renato Bonomini https://github.com/renatobo

  This file contains pinout definitions for a few tested boards:
  - https://docs.platformio.org/en/latest/boards/espressif32/esp32doit-devkit-v1.html
  - https://docs.platformio.org/en/latest/boards/espressif32/lolin_d32_pro.html

  If you have an undefined board, you need to
  - identify the LED_BUILTIN pin: this is usually the builtin blue led, used to signal WiFi status
  - identify the WIFI_MODE_BUTTON pin: this is BOOT for the DOIT-DevKit as it's already there, undefined for the LOLIN
  - identify UART2 PINs RX2 TX2, if not already defined by your board

******************************************************************************/

#if defined(ARDUINO_LOLIN_D32_PRO)

// Where is Serial2 connected - for Lolin we reconfigure to 2 free pins
// until https://github.com/espressif/arduino-esp32/pull/4520 is in place, we need to manually define it 
#undef RX2
#undef TX2
#define RX2 GPIO_NUM_4 // 12
#define TX2 GPIO_NUM_2 // 14
// Which pin controls the button to switch to STA mode
// You need to attach a button to this pin
#define WIFI_MODE_BUTTON GPIO_NUM_25
// Use external led on GPIO_NUM_12 to show signs of life
// #define LED_ACTIVE_EXTERNAL GPIO_NUM_12

// Use external led on GPIO_NUM_14 to show status of WiFi
// #define LED_WIFI GPIO_NUM_14
#ifndef LED_BUILTIN
#define LED_BUILTIN 5
#endif
#define GPIO_BATTERY GPIO_NUM_35 // Read Battery status from PIN 25
#define SHOWBATTERY // Show the battery charge indicator on the top menu of the web configuration panel

#elif defined(ARDUINO_ESP32_DEV)
#undef RX2
#undef TX2
#define RX2 16 // Standard label Rx2 on board
#define TX2 17 // Standard label Tx2 on board
#define WIFI_MODE_BUTTON 0 // default is: use the boot button to switch wifi modes
#define LED_BUILTIN 2 // this should not be needed if you choose the right board

#else

// #define RX2 GPIO_NUM_17 // Serial2 standard location on devkit
// #define TX2 GPIO_NUM_16 // Serial2 standard location on devkit
#define LED_BUILTIN 2 // usually 2 or 5
#define WIFI_MODE_BUTTON 0 // default is: use the boot button to switch wifi modes

#endif

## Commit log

2020-11-27 fix(gps): updated default speed to 115k2
    [bonogps.cpp]
2020-12-06 docs(readme): setup and using instr
    Added hardware + software setup, configuration, usage with screenshots
    [esp32_to_gps.fzz, gps-bn220-config.txt]
2020-12-07 fix(saveconfig): wifi_sta fixed
    getString signature uses return
    [bonogps.cpp]
2020-12-11 fix(wifi): wifi form fixed
    after webserver refactoring, form for wifi credentials was broken
    minor optimizations
    [bonogps.cpp]
2020-12-12 feat(wifi): ability to disable wifi for powersaving
2020-12-18 fix(racechrono): fixed NMEA messages
    created new properties for RaceChrono specific needs: GPS SVs only, Main Talker: GPS
    [bonogps.cpp]
2020-12-18 docs(hardware): pics of prototypes
    Updated README to remove "features" since they are moved to issues
    Added pictures of 2 prototypes with details of HW used for them
2020-12-19 docs(images): device configurations
    New screenshots on how to configure apps and more details about the specific requirements of each app
2021-01-09 docs(GPSsetup): How to choose a compatible GPS module and bootstrap its configuration
    [gps-bn880-config.txt]
2021-01-14 fix(lolind32): Fixed support for lolin and other improvements
    BT on/off improved
    OTA improved
    platformio.ini definitions improved
    Latest version of NimbleArduino allows removing unneeded components
    [bonogps.cpp, bonogps_board_settings.h]
2021-01-14 doc(lint): improved Arduino IDE and linted
2021-01-18 feat(lolind32pro): battery voltage and documentation
    - battery level is now read for LOLIN D32 PRO
    - documentation on LOLIN D32 PRO
    - linting and clean up of documentation
2021-01-21 feat(battery): percentage displayed in home page
    - CSS in non-minized format and processor to generate the minized format
    - % of charge based on voltage between 3.3 and 4.2
2021-01-21 docs(battery): percentage displayed in home page
2021-01-22 feat(BLE battery): BLE battery and refactoring
    - now BLE broadcast battery status (doc updated)
    - BOARD_NAME macro was not needed
    - SHOW_BATTERY macro determines usage of battery gauges
    - Turn OFF (deep sleep) capablity, useful on lolin d32 pro since there is no builtin power switch
    - clients are now listed with their address
    - optimizations on web portal html generation
    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
2021-03-03 feat(leds): support 'active' and 'wifi' external LEDs for enclosure setup
    Use external led on GPIO_NUM_12 to show signs of life
    #define LED_ACTIVE_EXTERNAL GPIO_NUM_X
    Use external led on GPIO_NUM_14 to show status of WiFi
    #define LED_WIFI GPIO_NUM_Y
    [lolin_d32_pro.fzz]
2021-03-07 fix(uri braces): webserver url were not working
    With the latest arduino-esp32, the WebServer library now requires explicit usage of
    ..
    #include <uri/UriBraces.h>
    ..
    server.on(UriBraces("/users/{}"), []() {
    [bonogps.cpp]
2021-03-08 fix(battery): regression on last version: battery display was left undefined
    [bonogps.cpp, bonogps_board_settings.h]
2021-03-08 feat(longer press): testing a better wifi button function and management for wifi_sta
    When WiFi_STA is triggered w/out a known WiFi network, the device does not know what to do
2021-03-11 refactor(wifi_sta): WiFi Off default - long press for WiFi STA
    Changed behavior of BOOT button: now it switches between WiFi OFF and WiFi AP.
    If you need WiFi STA, press the button for at least 2 seconds (you change this)
2021-03-15 docs(3d print): how to build a base for under tail install
    [bonogps_panigale_baseboard.stl, bonogps_panigale_battery_slider.stl]
2021-08-05 build(libraries): Fixes for library updates
    Updates to libraries needed some dependency updates
    * NimbleArduino latest version (waiting for a release)
    * TaskScheduler updated
    [bonogps.cpp]
2022-02-11 Note on battery holder
2025-02-05 Add empty .ino for Arduino Add missing esp_bt.h include Add '#if __has_include' to bonogps.cpp when compiled from Arduino Add #ifdef guard around ble_start()
    [bonogps.cpp]
2025-02-09 Updated documentation for Arduino 2
2025-02-09 * Changed logic of BAUD switching to avoid issues with buffer setup sequence * Code comments improvements
    [bonogps.cpp]
2025-02-09 Updated h2zero/NimBLE-Arduino to ^2.2.1
2025-02-18 Added 20Hz and 25Hz when macro HIGHER_GPS_RATES is defined
2025-02-26 Documentation updated for 20/25 Hz and M10 GPS modules
2025-06-22 Fix NimBLE-Arduino version
    The latest versions of h2zero/NimBLE-Arduino library causes build issues due to address allocation conflict.
    So, i fixed version to 2.2.3.
2025-06-28 Update NimBLE-Arduino library version to 2.3.1
2025-06-28 Update NimBLE-Arduino library version to 2.3.2
2025-11-12 Improve documentation across all markdown files
    This commit enhances the documentation quality with the following improvements:
    - Fix typos and spelling errors:
    * "Don'f" → "Don't"
    * "Trasparent" → "Transparent"
    * "Reciever" → "Receiver"
    * "Configrations" → "Configurations"
    * "settins" → "settings"
    * "bongogps" → "bonogps"
    * "doesn not" → "does not"
    * "SPIFSS" → "SPIFFS"
    * "undefined,d" → "undefined,"
    - Improve grammar and sentence structure:
    * "device to reads" → "device that reads"
    * "list of hardware" → "a list of hardware"
    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
2025-11-12 Standardize WiFi spelling and fix typos in app connection docs
    Standardize terminology:
    - "Wifi" → "WiFi" (correct capitalization)
    - "Wi-Fi" → "WiFi" (consistent with rest of documentation)
    - "wifi" → "WiFi" (correct capitalization)
    Additional fixes:
    - "perfrom" → "perform"
    - "you target" → "your target"
    - "is show" → "is shown"
    Files updated:
    - software/connecting/racechrono/README.md
    - software/connecting/harrylaptimer/README.md
    All instances now use "WiFi" consistently throughout the documentation,
    matching the predominant usage pattern in the project.
2025-11-12 Add comprehensive Troubleshooting and FAQ sections
    This commit adds extensive troubleshooting guides and FAQ sections based
    on common issues reported in GitHub discussions and issue tracker.
    Main README.md - New "Troubleshooting and FAQ" section:
    GPS and Hardware Issues:
    - GPS acquisition time and satellite fix problems
    - No GPS data reaching mobile app (baudrate, wiring, messages)
    - GPS module selection guidance with recommendations
    - Antenna placement and orientation tips
    Bluetooth and Connection Issues:
    - ESP32 reboot on Bluetooth settings change (partition space, memory)
    - RaceChrono BT-SPP reconnection problems (known issue #30)
    - BLE connection issues with Harry's Lap Timer (UUID co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
2025-11-12 Add comprehensive hardware-specific troubleshooting guides
    This commit adds extensive hardware troubleshooting sections to help users
    diagnose and resolve common hardware, wiring, and assembly issues.
    hardware/GPS/README.md - New "GPS Hardware Troubleshooting" section:
    Module-Specific Issues:
    - BN220/BN880 (M8): Communication, signal quality, configuration persistence
    - BK280/BK880 (M10): 25Hz configuration, U-Center recognition, performance
    - NEO-M8N (genuine u-blox): Multi-constellation limitations, value proposition
    - Module-specific solutions for common problems
    Antenna Issues:
    - Intermittent GPS fix and signal drops
    - Active antenna troubleshooting (power, cable, LNA)
    - Installation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
2025-11-12 Add comprehensive documentation enhancements
    - Quick Start Guide: Added 5-step beginner guide with budget breakdowns
    - Technical Specifications: Added detailed specs for GPS accuracy, power consumption, connectivity, memory usage, NMEA messages, and environmental conditions
    - Cross-references: Added 'See also' sections throughout documentation linking related guides
    - Time/Difficulty Estimates: Added time estimates and difficulty levels to all major sections
    - Navigation: Improved internal linking between hardware, software, and app connection guides
    These enhancements help new users get started faster and provide clear expectations for build time, difficulty, and system performance.
2025-11-12 Add verification checklist and common mistakes section
    - Verification Checklist: Added comprehensive checklist to verify working setup
    - Hardware & boot checks (ESP32, LEDs, power)
    - GPS functionality (satellite fix, signal quality)
    - Connectivity & web interface access
    - App connection and data reception
    - Track day readiness checks
    - Common Mistakes: Added detailed common mistakes to avoid
    - Critical mistakes (GPS configuration, partition scheme, wiring, indoor testing)
    - App compatibility mistakes (Talker ID, connection methods, refresh rates)
    - Build mistakes (library versions, Git cloning, USB power)
    - Hardware mistakes (voltage, soldering, antenna placement)
    - Conf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
2025-11-12 Add Glossary, Known Good Configurations, and Complete BOM
    Three high-ROI documentation additions for beginner users:
    1. Glossary (70+ technical terms):
    - GPS & Navigation terms (fix, cold start, GNSS, M8/M10, C/N0, HDOP)
    - GPS Antenna terms (active vs passive, LNA)
    - GPS Message Formats (NMEA, UBX, Talker IDs, all message types)
    - Connectivity terms (BLE, BT-SPP, TCP-IP, UART, baudrate, mDNS)
    - ESP32 terms (flash, RAM, PSRAM, partition, SPIFFS, GPIO)
    - Build & Development terms (Arduino IDE, PlatformIO, libraries)
    - u-blox Configuration terms (u-center, UBX-CFG commands)
    - Hardware terms (DevKit, LOLIN, Li-Ion, connectors, pins)
    - App-specific terms (HLT, RaceChro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
2026-07-13 Fix GPS rate reset to 10Hz on reboot with app preset active (#67)
    gps_enable_common() unconditionally set stored_preferences.gps_rate = 10
    and pushed the 10Hz UBX command. On boot, gps_initialize_settings() calls
    the active app preset (TrackAddict/RaceChrono/RaceTime) before applying the
    stored rate, so the preset clobbered the saved value and the rate switch
    that followed re-sent 10Hz. A user who saved 25Hz got 10Hz after every
    reboot. Users with no preset were unaffected.
    Decouple rate from presets:
    - Add gps_set_rate(uint8_t), single source of truth for rate -> UBX mapping
    (unknown rate defaults to 1Hz), replacing the duplicated switch in
    handle_rate() and gps_initialize_settings().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
    [bonogps.cpp]
